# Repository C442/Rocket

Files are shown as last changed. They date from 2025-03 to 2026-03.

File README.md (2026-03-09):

Rocket 2025
======
Project 2025 (http://www.youtube.com/watch?v=yQALvxHjtCE)

Welcome to our latest Project: a rocket guidance system. 

This project took around half a year to build, the other part of the year was spent documenting it. It was originally aimed to improve larger project management under time pressure and university schedule. We wanted to do this project a few years ago already, but somehow ended up with other side quests to fulfill, so this can be seen as our last highschool project, marking a waypoint for bigger, badder and more complex projects. I almost forgot that this project was also supposed to "cure problems related to boredom" and I want to point out that it definitely managed to fill quite some hours...maybe a few too many? Nah...this was worth it. 

This repo will only serve as a project overview and memory. This encompasses the code, the prints, the project paper and most importantly: some pictures 

Table of Content
================

<!--ts-->
- [Visual Designs](#Visual-Designs)
- [Board Computer](#Board-Computer)
- [Parachute Deployment](#Parachute-Deployment)
- [Thrust Vector Control System](#TVC-System)
- [About us](#About-us)
<!--te-->

Visual Designs
==============
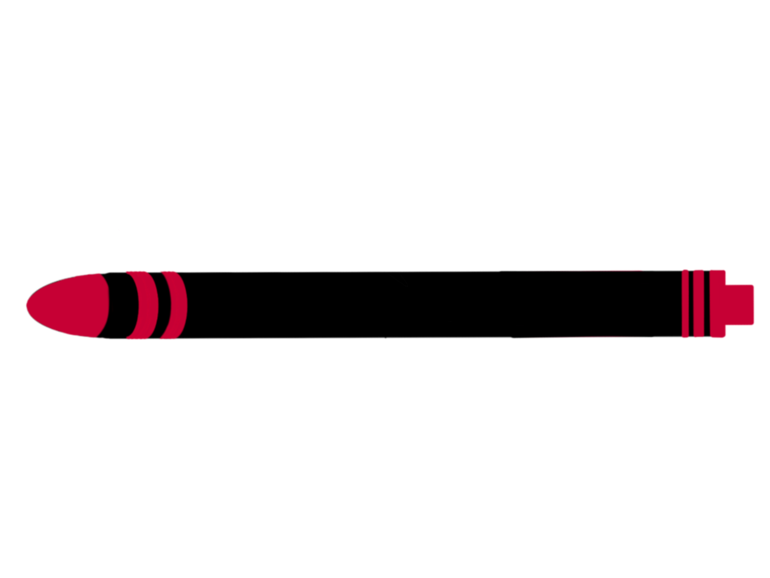
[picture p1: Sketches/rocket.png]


Board Computer
==============
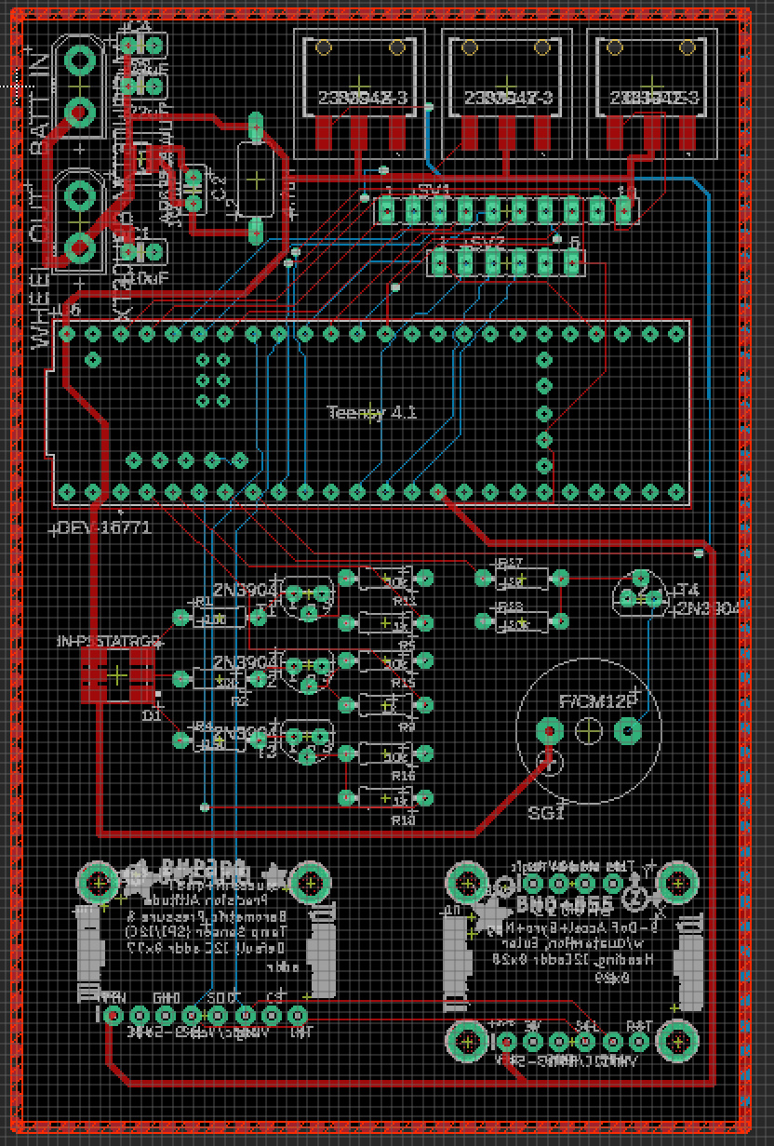
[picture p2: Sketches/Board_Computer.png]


Parachute Deployment
====================
Demo Preview

TVC System
==========
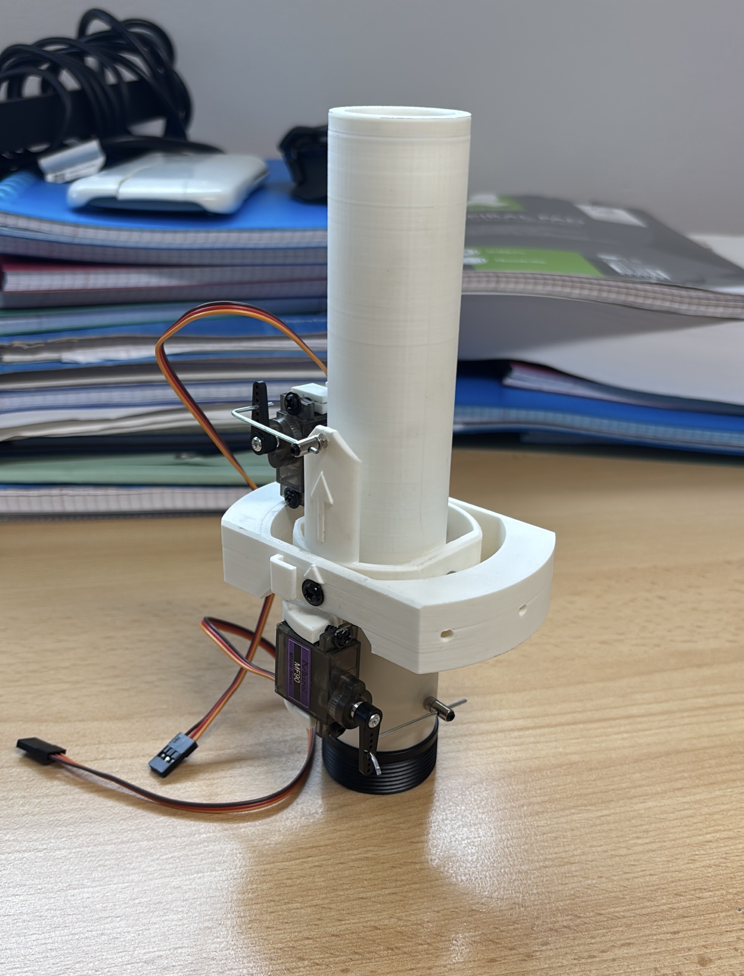
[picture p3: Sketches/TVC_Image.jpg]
TVC System


References
==========

1. [Collins Dictionary – Rocketry](https://www.collinsdictionary.com/dictionary/english/rocketry)  
   Accessed 12 January 2026.

2. [YouTube Video – Our first rocket launch](https://www.youtube.com/watch?v=nfHlhmoQnFs)  
   Accessed 27 January 2026.

3. [Luxembourg Space Agency – Spacewatch Global Article](https://spacewatch.global/2018/09/luxembourg-space-agency-open-for-business-as-new-space-hub/)  
   Accessed 28 January 2026.

4. [BBC News – Rocket Article](https://www.bbc.com/news/articles/cjewvpkw7weo)

5. [NASA Rockets Educator Guide](https://www.nasa.gov/wp-content/uploads/2012/07/rockets-educator-guide-20.pdf)  
   Accessed 28 January 2026.

6. [Wikipedia – Booster (Rocketry)](https://en.wikipedia.org/wiki/Booster_(rocketry))  
   Accessed 28 January 2026.

7. [BBC Science & Environment – Rocket Article](https://www.bbc.com/news/science-environment-24331860)  
   Accessed 28 January 2026.

8. [Eurocircuits – PCB Manufacturing](https://www.eurocircuits.com/)  
   Accessed 2 February 2026.

9. [Printables – Rocket Thrust Vector Control Gimbal](https://www.printables.com/model/9920-k-9-rocket-thrust-vector-control-gimbal-v8/related?lang=de)  
   Accessed 2 February 2026.

10. [YouTube – Nicola Gaiani](https://www.youtube.com/@nicola_gaiani)  
    Accessed 2 February 2026.

11. [Springer – Technische Mechanik Buch](https://link.springer.com/book/10.1007/978-3-662-59886-3)  
    p. 290. Accessed 9 February 2026.

12. [Wikipedia – PID Controller](https://en.wikipedia.org/wiki/Proportional%E2%80%93integral%E2%80%93derivative_controller)  
    Accessed 28 January 2026.

13. [YouTube – Parachute Ejection Inspiration](https://www.youtube.com/watch?v=COkh5ykzC3Y)  
    Accessed 9 February 2026.

14. [Madgwick Filter Explanation](https://medium.com/@k66115704/imu-madgwick-filter-explanation-556fbe7f02e3)  
    Accessed 9 February 2026.

15. [Introduction to Quaternions](https://lisyarus.github.io/blog/posts/introduction-to-quaternions.html)  
    Accessed 9 February 2026.

16. [YouTube – Moto Moto Song](https://www.youtube.com/watch?v=vx5vpG6jEXI)  
    Accessed 9 February 2026.

17. ChatGPT was used to check the text and correct it. In the abstract it was used to rephrase. It was also used to generate code.

18. [Project GitHub Repository](https://github.com/C442/Rocket)  
    The repository designated to this project.

About us
========
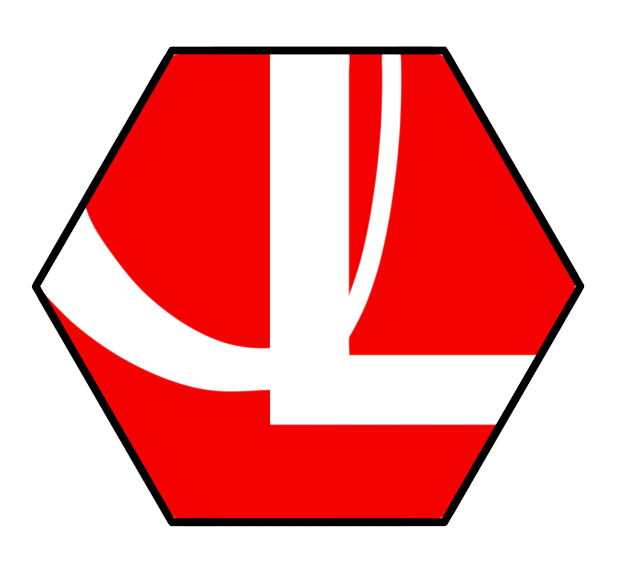
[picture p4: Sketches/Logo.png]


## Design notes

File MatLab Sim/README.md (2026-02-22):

# Modeling a Thrust Vector Controlled Rocket in Simulink

View Modeling a Thrust Vector Controlled Rocket in Simulink on File Exchange (https://www.mathworks.com/matlabcentral/fileexchange/80716-modeling-a-thrust-vector-controlled-rocket-in-simulink)

Thrust Vectoring or Thrust Vector control is the ability of an aircraft or a rocket's propulsion system to manipulate the direction of its thrust to control the rocket or aircrafts attitude or angular velocity. Adjusting the gimbal angle, controls the direction and attitude of the of the rocket as shown in the image below

Gimbaled_thrust_diagram

<a href="https://commons.wikimedia.org/wiki/File:En_Gimbaled_thrust_diagram.svg" title="via Wikimedia Commons">Gimbaled_thrust_diagram.gif:Brian0918 at en.wikipediaderivative work: Titimaster</a> / Public domain

Code in this repository is discussed in this BPS.Space YouTube video shown below.(http://www.youtube.com/watch?v=nwgd1CV__rs "")

To use the files,

- Clone the repository as seen [here](https://www.mathworks.com/help/simulink/ug/clone-git-repository.html)

- Open `simpleTVCRocketModel.slx`

- Click the appropriate hyperlink to choose between a simple Aerospace Blockset or Simscape implementation

- Move the Gimbal angle slider to see the effect of different gimbal angles on the trajectory of the rocket. 

[Learn how to get MATLAB and Simulink](https://www.mathworks.com/products/get-matlab.html)

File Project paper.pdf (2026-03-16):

# Project Paper

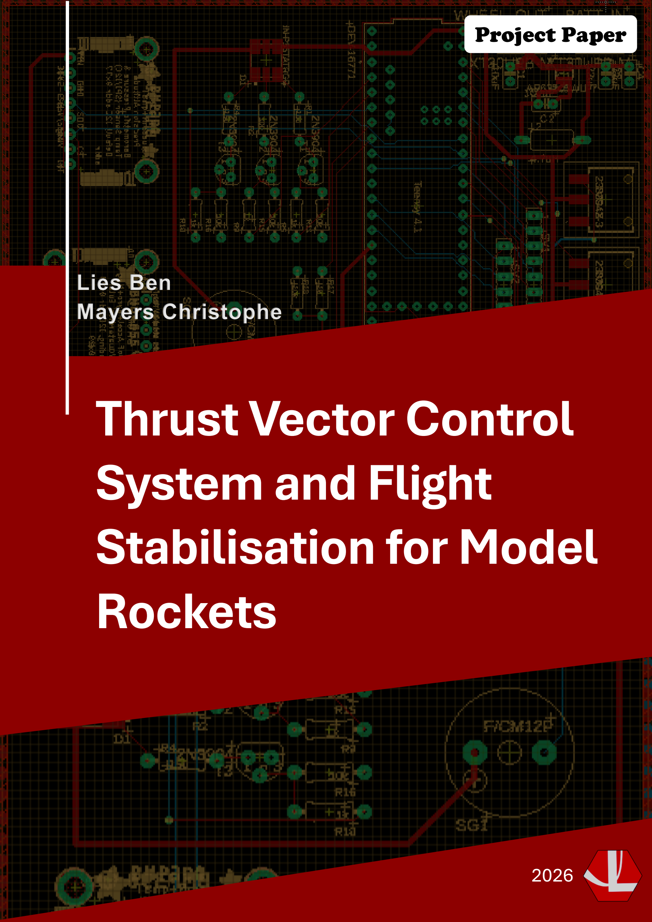
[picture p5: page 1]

## Lies Ben Mayers Christophe

# Thrust Vector Control System and Flight Stabilisation for Model Rockets

## Abstract

Rocketry is an engineering discipline concerned with the design, construction, and launch of rockets at both professional and amateur levels [1]. Due to its modular nature, it provides an effective framework for introducing engineering concepts at an early stage, allowing increasing levels of complexity to be incorporated across successive projects.

A first model rocket was launched in 2023 [2] and was equipped with an Arduinobased flight computer for data acquisition. Post-flight analysis revealed significant issues, including an unstable, highly elliptical flight path and limited usefulness of the collected data. These shortcomings motivated the development of the present project.

Building upon the earlier design, a new model rocket was designed, constructed, and simulated. Improvements included a smaller body tube, a higher-performance flight computer, and the integration of a flight guidance and stabilisation system based on thrust vector control. The primary objectives were achieved; however, the results also revealed new limitations, providing clear direction for future design iterations.
Index terms- Rocketry, guided flight, thrust vector control, flight stabilisation

List of Figures

## Contents

1 Introduction | 6
1.1 Domain | | 6
1.2 Scientific deliveries | | 6
1.3 Technical deliveries | | 6
2 Methodology | 7
2.1 Tools and prerequisites | | 7
2.2 Printed Circuit Board (PCB) | | 8
| 2.2.1 Design | | 8
| 2.2.2 Production | | 9
2.3 Thrust-Vector-Control System (TVC) | | 9
| 2.3.1 Design | | 9
| 2.3.2 Production | | 9
2.4 Reaction wheel | 11
2.4.1 Design | 11
2.4.2 Production | 13
2.5 Rocket body and nosecone | 15
2.5.1 Design | 15
2.5.2 Production | 16
2.6 Software | 16
2.6.1 Madgwick Filter [14] | 16
2.6.2 State Machine | 17
2.6.3 LQR Controller | 18
2.7 Simulations | 19
3 Results | 21
3.1 Printed Circuit Board (PCB) | 21
3.2 Thrust-Vector-Control System (TVC) | 21
3.3 Reaction Wheel | 22
3.4 Body and nosecone | 23
3.5 Simulations | 23
3.6 Software | 25
4 Conclusion | 25

## List of Figures

1 | Final board designed in EAGLE | | 8
2 | Final assembled PCB | | 9
3 | First TVC Mount prototype | 10

List of Figures

4 | Curve Fitting of the Y TVC Servo | 10
5 | Reaction wheel | 12
6 | Casing for the reaction wheel and PCB | 12
7 | Test setup | 13
8 | Early rocket body design | 15
9 | Nosecone | 15
10 Overview of the state machine | 17
11 Overview of the whole SIMULINK simulation | 19
12 Simulation of the rocket dynamics | 19
13 Simulation of the LQR Controller | 20
14 Converting torque to TVC angles | 20
15 Final TVC | 21
16 Finished reaction wheel | 22
17 Final assembled rocket | 23
18 Torque applied to the rocket | 24
19 Simulation results | 24
20 Software results | 25

1 Introduction

## 1 Introduction

Aerospace engineering has seen drastic advancements and an increasing public interest in Luxembourg. With the Luxembourg Space Agency (LSA) pushing the frontiers of international politics into an extra-planetary dimension in pursuit of a “commercial space hub“[3], the question of a sustainable rocket launching infrastructure rises naturally. The core problem of a space economy and the ability to utilise the associated vast resources is a logistical one. Transportation costs are currently not sustainable[4]. Reducing overall cost per launch is hence a necessary step for future space travel that can be achieved by optimizing the most cost inducing sections, like booster stages. Boosters are rocket engines that help with the initial thrust of a rocket to escape Earth’s gravity until reaching low orbit [5]. After expending all available fuel, they are cut off [6] and fall back to earth. The possibility of reusing these booster stages for future missions would substantially reduce operational costs [7] and could be achieved by making them land themselves, reducing potential damages. This work focuses on replicating a mandatory capability towards this novelty, namely controlled flight, and documenting it.

### 1.1 Domain

This project can be placed into the engineering domain. Main problems will revolve around correct algorithm tuning, managing components and the operating speed of the flight computer. Connecting so many electrical components to a development platform usually results in unpredictable behavior and requires a lot of careful preparation. This will be solved using a printed circuit board. The chosen algorithm must be adapted to the rocket, simulated and tuned which is closer to an art form than a science. However, the most important aspect is the operating speed of the development board which must keep up with mid-flight-calculation and communication. These parameters are most decisive for the success of this project.

### 1.2 Scientific deliveries

The scientific deliveries for this project are a deepened understanding of rocketry and preparing for more complex future projects. Rocket science is renowned to demand precision and a lot of knowledge. To attain a professional, or even an amateur level, can take years and depend on a lot of dedication, like any other skill. With the finalisation of this project, perseverance is proven and a contribution to public awareness is made. Potentially inspiring others to become scientists themselves would be one of the most preferable deliveries: “Not everyone can become a great [scientist], but a great [scientist] can come from anywhere”. (Ratatouille, 2007)

### 1.3 Technical deliveries

The technical deliveries are more dispersed and build up to a fully functioning model rocket with a directional guidance system. The hardware consisting of the printed circuit board (PCB), the thrust-vector-control (TVC) system, the reaction wheel, the nose cone with its parachute release mechanism and the rocket body. The software will be a directory of files responsible for the communication between components, collecting information, controlling servo and brushless motors, and the flight algorithm.

## 2 Methodology

### 2.1 Tools and prerequisites

Since this project encompasses the entire production process of a rocket, a wide range of technical skills and tools is required:

- Simulink is the software used to simulate the flight algorithms performance and later tune the necessary parameters in the program on the development board. A rocket computer alone is unaware that it is a flying object and only reacts within the rules of its programming. If one were to use the exact same algorithm for a 2m and a 20 cm long rocket, one would most likely have drastically different results. Flight algorithms are not “add-on solutions” and must be tested and adjusted. This fine tuning allows to adapt the algorithm to the rocket’s specific requirements. Understanding how Simulink works is hence crucial for this project.
- Autodesk Fusion360 is the computer-Aided-Design (CAD) platform used for 3d modelling. 3D modelling is necessary to visualise and later easily, qualitatively and efficiently try out hardware components for the rocket. This skill set is hence not only a must for this project, but for any future engineer.
- GitHub is the chosen developer platform that helps to organise, manage and store our files for this project. It is beneficial, but not mandatory since it mostly just improves team related workflow.
- Arduino/C++/Matplotlib/Jupyter Notebook are the programming languages used for this project because of all the algorithms and scripts for the electronic components. Matplotlib and jupyter notebook were mostly used to do some quick calculations and TVC gimbal curve fitting. The entire software relies on understanding these programming languages.
- Autodesk Eagle is an electronic design automation software (EDA) that helps to design PCBs. As this project revolves around a custom printed circuit board, knowing the physical behaviour of the components and being familiar with this tool is recommended.
- Prusa/Cura Slicer and Bambulab PS1 printer are the next natural step after the 3D modelling program. The slicer is used to prepare the 3D model for printing. Most parts of this project require high precision and durability. Access to good printers and a general comprehension of this process is therefore compulsory.

2 Methodology

- Hand tools and painting equipment are also required. All secondary tasks, like the assembly of the PCB or painting the rocket body need tools, like a soldering iron or spray paint.

### 2.2 Printed Circuit Board (PCB)

The PCB is the heart of the entire rocket. It is connected to an 11.1V battery and controls all the actuators. Besides that, it gathers important sensor data, logs it onto an SD Card and has sensor fusion to predict and correct the rocket’s position.

### 2.2.1 Design

The design process mostly began with the question of which information would be needed to keep a rocket upright. We settled on a BNO055 inertial measurement unit (IMU) sensor to obtain the orientation and a BMP390 barometer to determine the altitude. Then, only the actuator side needed to be covered. To accomplish this, three terminal blocks were used to connect the X and Y servos of the TVC and the servo controlling the parachute ejection. For visual and audible feedback, a bright RGB LED and a buzzer was chosen. As most of the components required 3.3V or 5V, a voltage converter from 11.1V to 5V was implemented. The most important component of the PCB was a Teensy 4.1 acting as main MCU. It is known for its incredible speed and even having an SD Card reader/writer already onboard, outperforming the more commonly used Arduino Uno by far.

As the last step we used EAGLE to draw a simple schematic and create a board connecting all previously chosen components. Additionally, some headers for debugging and a reaction wheel was added.

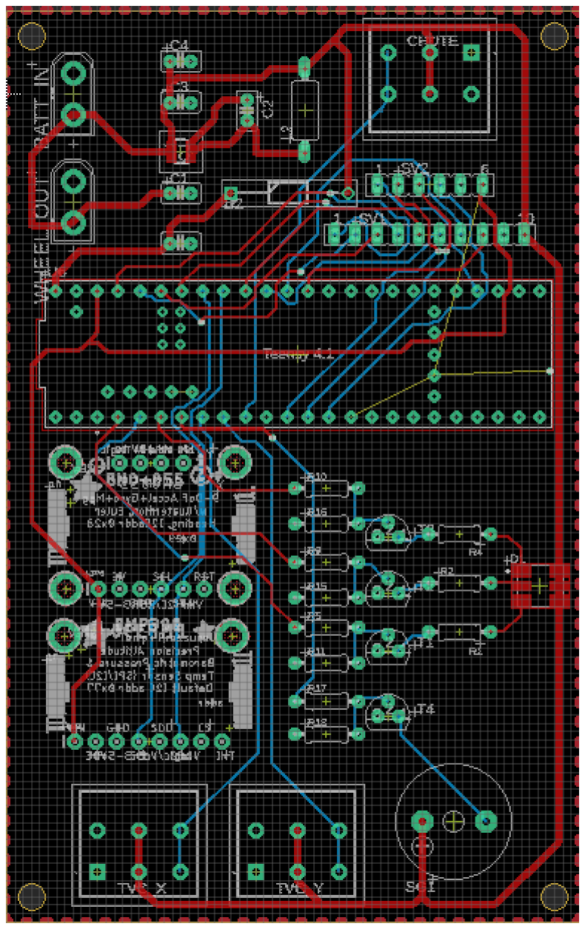
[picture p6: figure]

Figure 1: Final board designed in EAGLE

2.3 Thrust-Vector-Control System (TVC)

### 2.2.2 Production

The files of the PCB were sent to Eurocircuits [8] from which the later on finished boards were received. All components were then soldered onto it and tested with a voltmeter to prevent unexpected future errors. To exemplify, it was through this method immediately noticeable that an RGB LED was soldered the wrong way onto the PCB or the voltage converter design flawed. The voltage converter was then later replaced by the brushless motor’s electronic speed controller which luckily also had the necessary 5V power distribution.

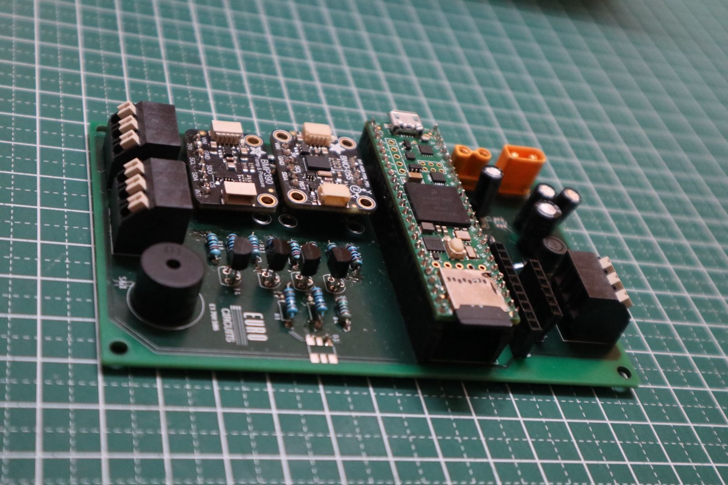
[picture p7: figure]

Figure 2: Final assembled PCB

### 2.3 Thrust-Vector-Control System (TVC)

The TVC can be simply described as a two axis gimbal which holds a solid rocket motor in place and allows to precisely control the motors orientation through two servos. Without it, stabilizing a rocket would be impossible.

### 2.3.1 Design

For the design we looked for online inspiration and quickly found some already existing solutions [9] which seem to work quite well. After adapting the design to the required parameters of the chosen rocket body in Fusion360, the first prototype was made.

### 2.3.2 Production

The TVC mount was fully 3D printed in PLA and then assembled with screws and servo linkages until we end up with the following:

2 Methodology


Figure 3: First TVC Mount prototype

Having the physical model ready, it was then essential to determine a function that converts servo angle to gimbal angle for both axis. Two approaches were trialed to achieve this:

Engineering approach: For this approach we strapped an inertial measurement unit (IMU) to the gimbal, sent known angles to the servos and measured the resulting gimbal angle with the IMU. This process was repeated several times for redundancy. Afterwards, one would only need to do some curve fitting with Matplotlib/Jupyter Notebook and get an appropriate function.

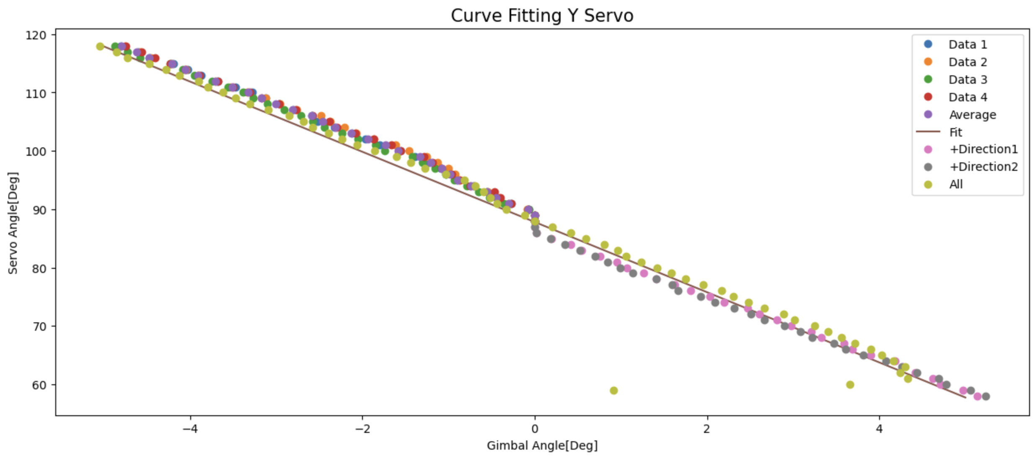
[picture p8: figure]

Figure 4: Curve Fitting of the Y TVC Servo

Mathematical approach: For this approach we used a mathematical model developed by the YouTuber Nicola Gaiani [10]. One would need to enter the specific parameters of the TVC mount and then get for each servo angle input an appropriate gimbal angle output. This process required curve fitting again.

2.4 Reaction wheel

Source code 1: Mathematical model of the TVC mount 1 import math

2
3 | # Constants (in mm)
4 | l1_s1 = 10.5 | # length of servo attach
5 | l2_s1 = 32.5 | # bar length
6 | l3_s1 = 42.5 | # distance from pin to bar on the 3D printed part
7 | Cx_s1 = 30.0 | # x distance between servo wheel and mount pin
8 | Cy_s1 = -29.0 # y distance

9
10 import numpy as np

11
12 | def m_to_s1(a):
13 | a = np.radians(90-a)

14
15 | px = Cx_s1 + l3_s1 * np.cos(a)
16 | py = Cy_s1 + l3_s1 * np.sin(a)
17 | d = np.sqrt(px**2+ py**2)

18
19 | x1 =(l1_s1**2+ d**2- l2_s1**2) / (2 * d)
20 | y1 = np.sqrt(l1_s1**2- x1**2)

21
22 ang = np.arctan2(py, px)

23
24 | x2 = x1 * np.cos(ang)- y1 * np.sin(ang)
25 | y2 = x1 * np.sin(ang)+ y1 * np.cos(ang)

26

27
28 return np.degrees(np.arctan2(y2, x2))

### 2.4 Reaction wheel

The reaction wheel tries to conserve the angular momentum of the rocket while not using any fuel. It tries to counter rotate any undesired rotational spin, caused by air drag for example, acting as a small support system for the thrust vector control system. By keeping the rotational speed low, or null at best, it could prevent a potential coning motion, usually referred to as precession. In this project, it consists of an electronic speed controller (ESC), a brushless motor and the reaction wheel.

### 2.4.1 Design

The design phase mostly revolved around finding an acceptable hardware solution for a reaction wheel, finding a good production method and deciding on its placement in the rocket.

2 Methodology

Originally, the reaction wheel was supposed to be out of lightweight aluminum to maximize the power limits of the brushless motor, but the addressed milling company made us reconsider. Consequently, it was 3D printed. To achieve the highest moment of inertia the reaction wheel got the form of a ring with radial support to a central hub that connects directly to the brushless motor [11]. To compensate for the missing weight, screw holes were added for later weight addition.

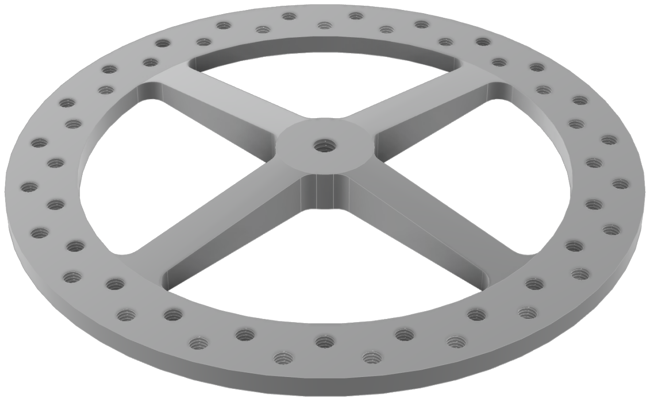
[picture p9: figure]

Figure 5: Reaction wheel

To guarantee the safety of the internal rocket body and simultaneously give the brushless motor a fixed place, a casing was designed for it. However, the casing sealed the motor from the PCB and entailed the electronics to run between the inner rocket body wall and the casing.

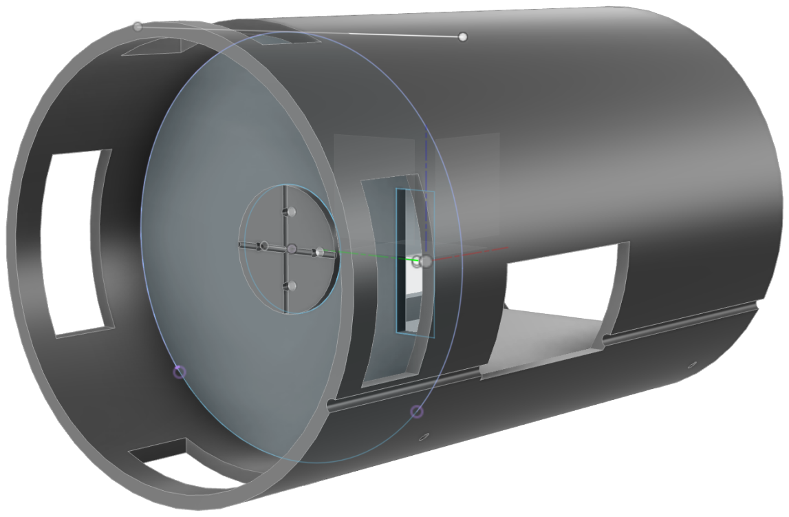
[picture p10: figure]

Figure 6: Casing for the reaction wheel and PCB

2.4 Reaction wheel

### 2.4.2 Production

The production process describes the practical realization of the reaction wheel and its addition to the PCB. It began with 3D printing the reaction wheel and adding screws onto it. Afterwards, the brushless motor was tested while attached to the PCB.

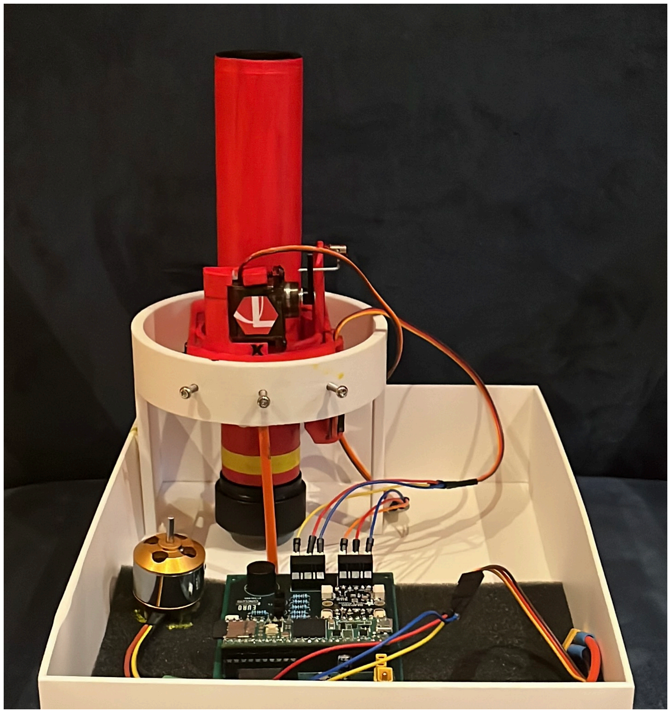
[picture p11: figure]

Figure 7: Test setup

In these coding experiments, the electronic speed controller didn’t support bi-directional spin. After projecting the problem into the domain of model cars, it could have been solved with an H-bridge, allowing switching the polarity of the brushless motor with relays. This task was not foreseen, implied a redesign of the power supply and remodeling of all involved components. The easiest solution was however to replace it with a new bidirectionally supported ESC, even though it was monetarily more expensive. The latter solution was implemented. For improved movement, we added a PID controller to the reaction wheel [12]. A PID controller is a control algorithm that works with a continuous feedback loop for a correct adjustment around a fixed setpoint. In this project, this fix set point can be interpreted as a state, namely the rocket not rotating around its own axis. This correction revolves around magnitude of the error between the setpoint and the actual value. This controller projects this error into the near future and remembers how it was in the past. Based on this information it tries to decides to adjust the motor speed accordingly. This lowers the risk of overshooting and consequently making too harsh movements in this time sensitive operation.

Source code 2: PID controller implementation for reaction wheel

1 | void MotorController::update() {
2 | // 1. Read gyro (Y-axis rate)
3 | imu::Vector<3> gyro = bno.getVector(Adafruit_BNO055::→ω
| VECTOR_GYROSCOPE);
4 | measuredRate = gyro.y();

5

2 Methodology

6 | // 2. Time step
7 | unsigned long now = millis();
8 | float dt =(now - prevTime) / 1000.0;
9 | prevTime = now;

10
11 | // 3. PID
12 | float error = setpoint - measuredRate;
13 | integral += error * dt;
14 | float derivative =(error - prevError)/ dt;
15 | prevError = error;

16
17 | float pidOutput = Kp * error + Ki * integral + Kd * derivative→ω
| ;

18
19 | // 4. Compute throttle
20 | int throttle = computeThrottle(error, pidOutput);
21 | esc.writeMicroseconds(throttle);

22
23 | // 5. Debug
24 | Serial.print("Y rate: "); Serial.print(measuredRate);
25 | Serial.print(" | Error: "); Serial.print(error);
26 | Serial.print(" | PID: "); Serial.print(pidOutput);
27 | Serial.print(" | Throttle: "); Serial.println(throttle);
28 | }

After testing completed successfully, no further problems arose. The reaction wheel was added to the casing and the ESP finally soldered to the PCB. We then used 2 component glue to fix the casing into the rocket body.

2.5 Rocket body and nosecone

### 2.5 Rocket body and nosecone

The rocket body contains all the electronics. The nosecone is responsible for the parachute release.

### 2.5.1 Design

The design phase of the rocket body and nosecone covers the decision for the size, appearance and the parachute mechanism.

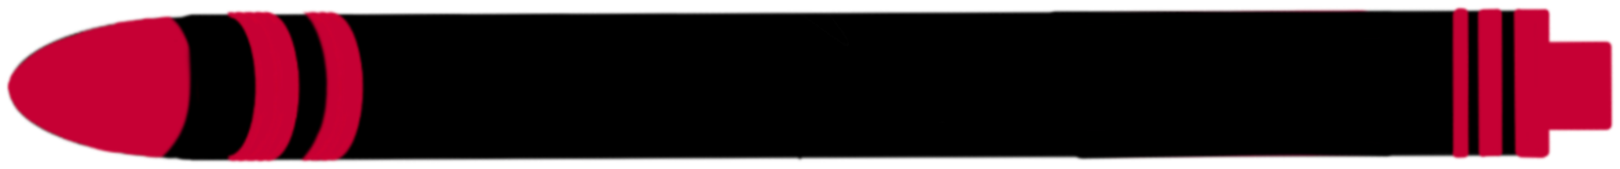
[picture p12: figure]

Figure 8: Early rocket body design

The most influential factor for the decision of the rocket body was convenience. It should be large enough to justify a TVC system, but not too large to unnecessarily waste space. A tube with a diameter of 10 cm and length of 100 cm was chosen. The nose cone must have a reliable parachute release mechanism and fit our personalised rocket body. Taking inspiration from the Youtube Channel Air Command Rockets [13] it was hence opted to 3D model it and add an empty chamber that opened with a servo motor. This servo motor would hold a plate that could fall off and open the chamber, allowing the parachute to simply fall out.

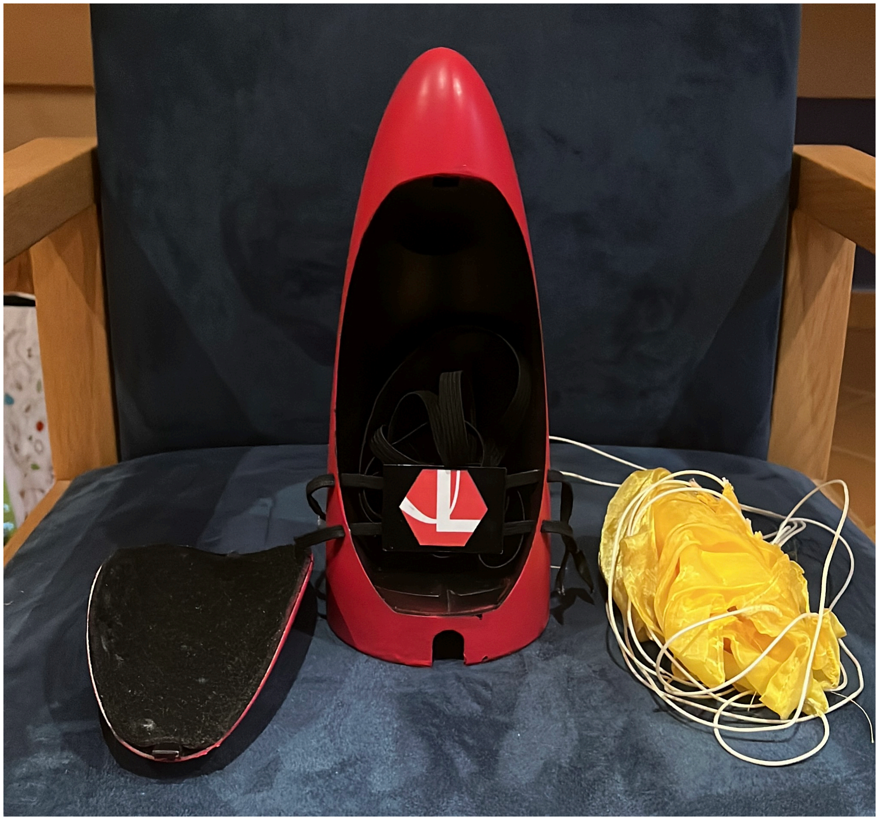
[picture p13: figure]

Figure 9: Nosecone

2 Methodology

For the paint job, it was decided to go for a bright red with yellow and dark elements imitating a famous Formula 1 car design.

### 2.5.2 Production

The production process included the rocket body and nosecone modifications. On arrival, the rocket body was painted with spray cans and then cut in half. Firstly, it received a black coating and then red stripes. At the same time, we painted the nosecone completely red. The cord was attached to the parachute, folded, put into the nosecone chamber and then sealed with the door. After putting in all the electronics, the lower half contained the TVC system and PCB. The upper part consisted out of the reaction wheel and the nosecone. At last, we reattached the 2 halves.

### 2.6 Software

The onboard flight software is responsible for real-time state estimation, flight-phase management, and thrust vector control during powered ascent.

The software is structured into three main layers:

1. Sensor acquisition and attitude estimation,
2. State machine governing flight phases, and
3. a control layer computing thrust vector commands based on the estimated state

### 2.6.1 Madgwick Filter [14]

Accurate attitude estimation is essential for thrust vector control, as control commands depend directly on the rocket’s orientation. Gyroscopes provide smooth short-term orientation but suffer from drift, while accelerometers provide an absolute reference to the gravity direction but are sensitive to dynamic accelerations.

The Madgwick filter fuses both sensor types in a computationally efficient manner, making it well suited for real-time embedded applications. Orientation is represented using quaternions [15], avoiding gimbal locks. Gyroscope measurements are used to propagate orientation through quaternion integration, while accelerometers are used to correct long-term drift.

The correction is obtained by comparing the measured gravity direction with the direction predicted by the current orientation estimate. The resulting misalignment is expressed as an error function in quaternion space and its gradient provides a correction direction. The estimated quaternion derivative is given by:

2.6 Software

q˙ est = q˙ ω ↑ ω ↓f
↔↓f↔ | (1)

Where ω controls the influence of the accelerometer-based correction. In our case this value is set very low as the rocket represents a highly dynamic environment.

### 2.6.2 State Machine

The flight software is organized as a finite state machine to ensure deterministic and robust behavior throughout the flight. Each state encapsulates a distinct flight phase with well-defined actions and transition conditions. Separating the flight into phases also improves safety, since time-critical control tasks are only enabled when required.

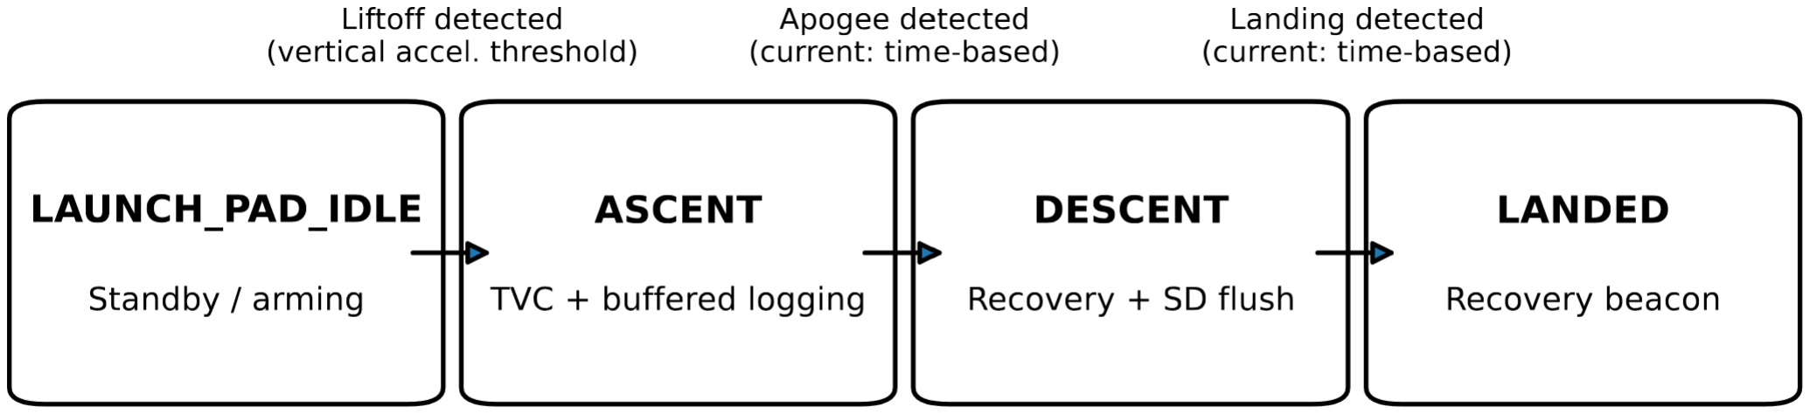
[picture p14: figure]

Figure 10: Overview of the state machine

LAUNCH_PAD_IDLE (pre-launch) In the LAUNCH_PAD_IDLE state, the flight computer remains in a safe standby mode on the launch pad. Sensors are active and the system continuously evaluates a liftoff condition using the measured vertical acceleration. Once liftoff is detected, the system timestamps the start of flight and records a corresponding entry in the event log.
Transition to ASCENT: Liftoff detected (vertical acceleration threshold exceeded).

ASCENT (powered flight / TVC active) During ASCENT, thrust vector control is enabled and the software runs two periodic tasks with different update rates. The control loop executes at 100 Hz and performs attitude estimation, control law evaluation, and servo command output. In parallel, a health monitoring and logging task runs at 25 Hz. To avoid non-deterministic latency introduced by SD card writes, high-rate flight data is buffered in the Teensy flash memory during ascent. Discrete events (e.g., liftoff, apogee) are stored in a separate event file together with timestamps.
Transition to DESCENT: Apogee detected (current implementation: time-based criterion).

DESCENT (recovery phase) After apogee, the system transitions to DESCENT and the parachute is ejected. Since strict real-time control is no longer required, buffered flight data stored in flash is flushed to the SD card during descent. Logging is finalized and closed as well as flight control actions are disabled.
Transition to LANDED: Landing detected (current implementation: time-based criterion).

2 Methodology

LANDED (post-flight) In the terminal LANDED state the system enters a safe post-flight mode. A recovery beacon (buzzer and LED) is activated to facilitate locating the rocket.

### 2.6.3 LQR Controller

During powered ascent, the rocket is stabilized using a Linear Quadratic Regulator (LQR) acting on the rotational dynamics of the vehicle. The system is linearized about the nominal upright flight condition, and the state vector is defined as

x = !

ωε"T , | (2)

where ω denotes small attitude deviations from the vertical reference and ε the corresponding angular rates.

The LQR computes a state-feedback control law of the form

ϑ cmd = ↑Kx, | (3)

where ϑ cmd is the demanded control torque about the rocket’s center of mass. The gain matrix K is obtained by minimizing the quadratic cost function

J =

#→

0

$
xTQx + ϑ T

cmdRϑ cmd%
dt. | (4)

The weighting matrices Q and R penalize attitude deviations and excessive control torque, respectively, allowing a systematic trade-off between stability and control effort.

The demanded torque is subsequently converted into thrust vector deflection commands using the known thrust magnitude and lever arm of the thrust vector control mechanism. The LQR controller is active exclusively during the ascent phase and relies on the attitude estimate provided by the Madgwick filter.

2.7 Simulations

### 2.7 Simulations

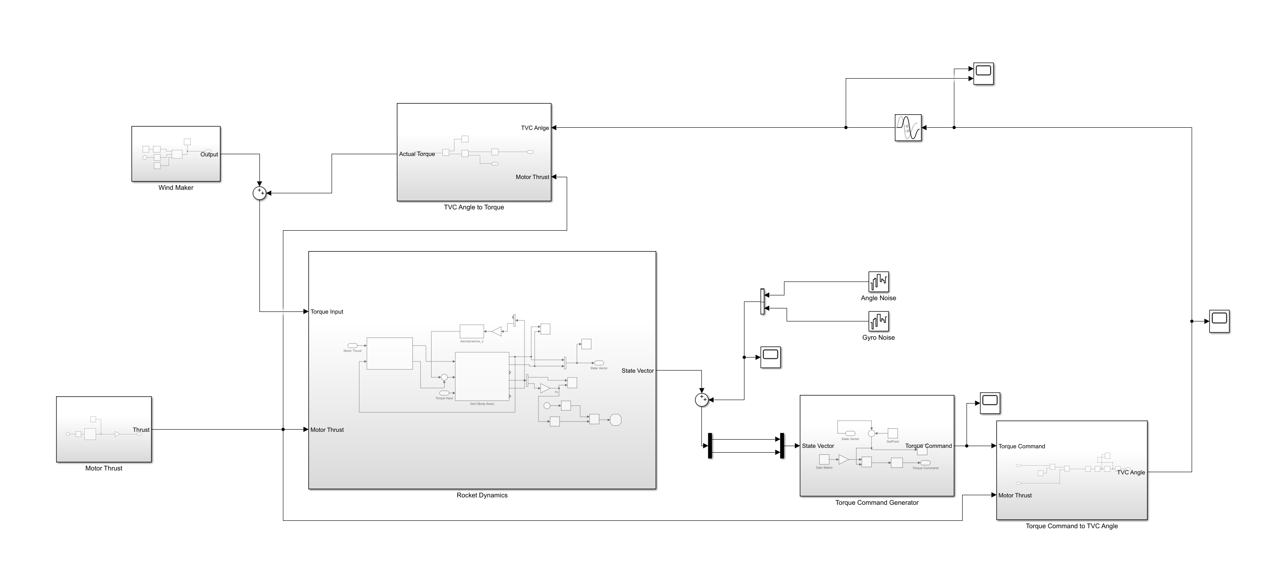
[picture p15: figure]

Figure 11: Overview of the whole SIMULINK simulation

A nonlinear simulation environment was developed in SIMULINK to validate the proposed state estimation and control architecture prior to flight testing. The simulation captures the rotational dynamics of the rocket, thrust vector control actuation, sensor noise, and external disturbances, while maintaining a structure that closely resembles the onboard flight software. This allows controller parameters and state machine logic to be evaluated under realistic conditions before deployment.

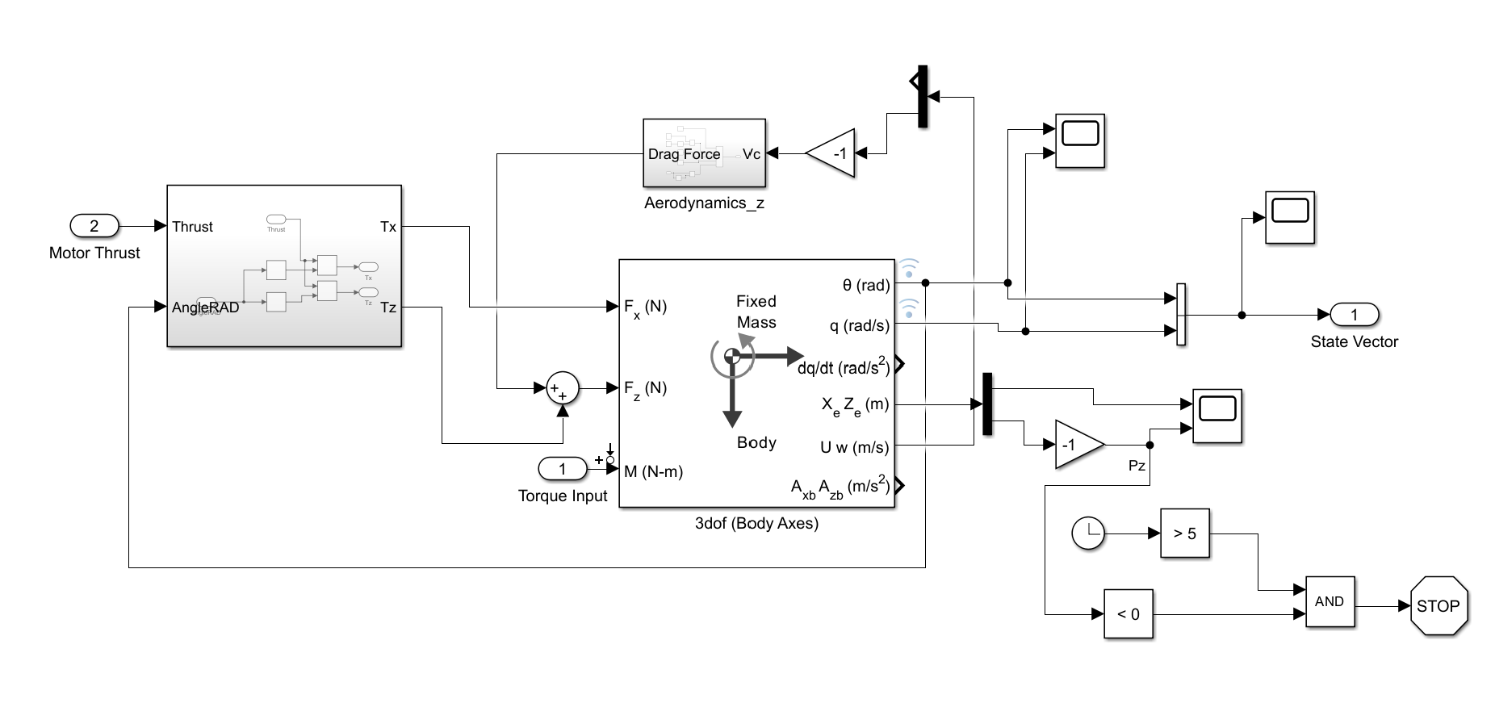
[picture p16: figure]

Figure 12: Simulation of the rocket dynamics

Rocket Dynamics Model The rocket is modeled as a rigid body rotating about its center of mass. The rotational dynamics are governed by Euler’s equation:

Iε˙ = ϑ TVC + ϑ dist,

2 Methodology

where I denotes the moment of inertia, ϑ TVC the control torque generated by thrust vectoring, and ϑ dist external disturbance torques.
The angular rate is integrated to obtain the attitude state, which forms the basis for feedback control. Motor thrust is provided as an external input to the dynamics block, allowing the simulation to capture thrust variations over time.

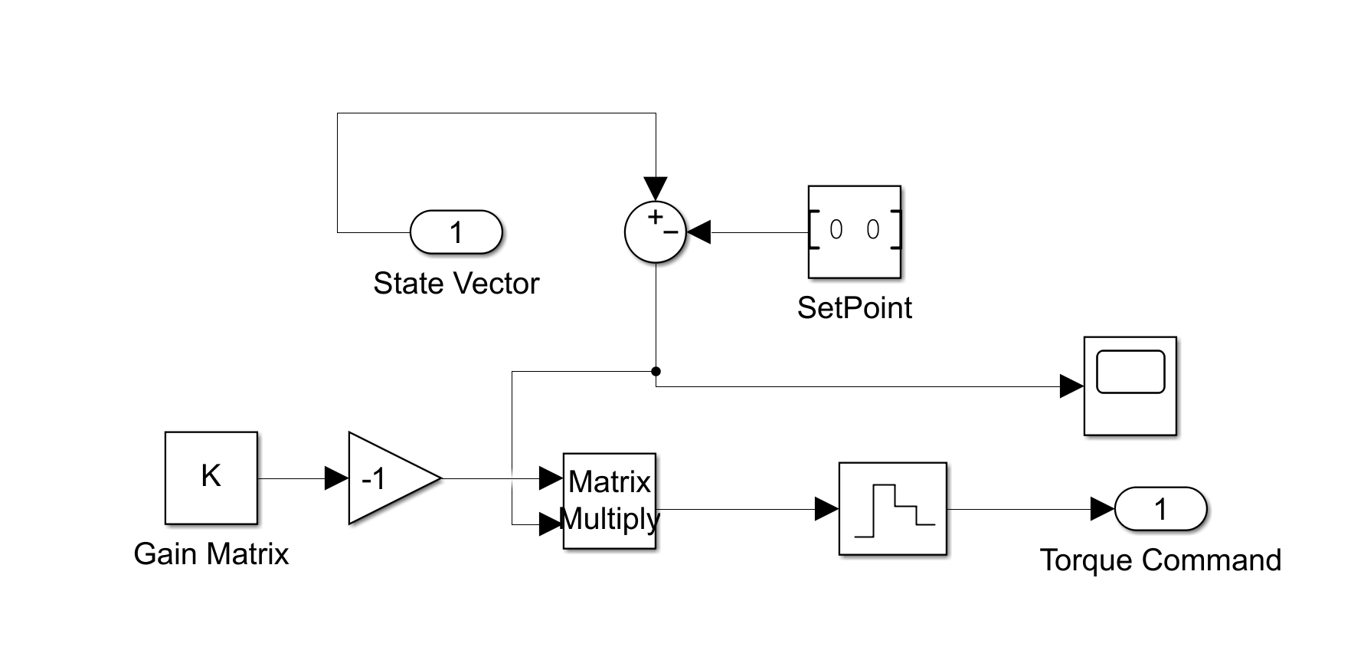
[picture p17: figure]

Figure 13: Simulation of the LQR Controller

Thrust Vector Control and Actuator Mapping The LQR controller outputs a demanded control torque about the rocket body axes. This torque is converted into a thrust vector deflection angle using the known motor thrust magnitude and moment arm of the TVC mechanism. The resulting TVC angle represents the actuator command applied to the motor mount.

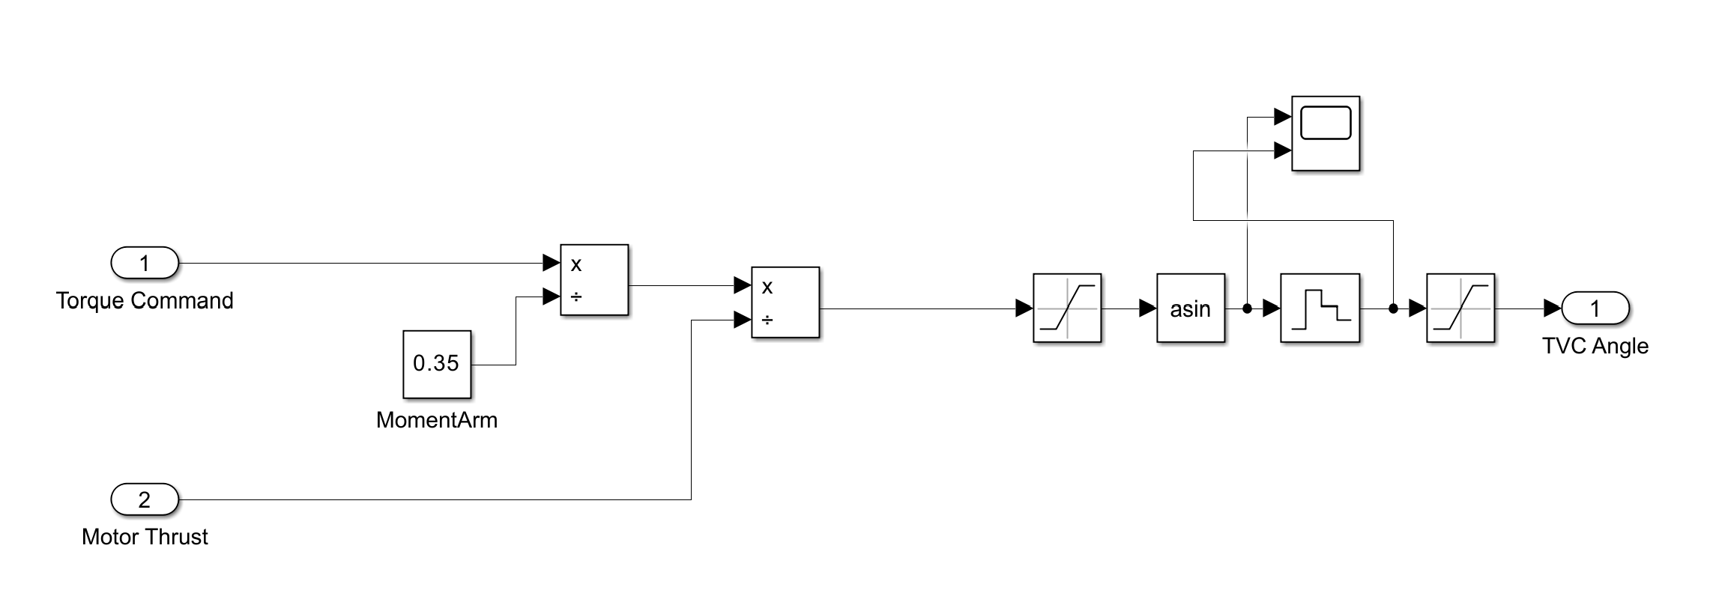
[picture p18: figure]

Figure 14: Converting torque to TVC angles

Within the simulation, this mapping takes into account actuator limits (max deflection angle, actuator delay, etc) as well as flight computer limits (control loop runs at 100Hz)

Sensor Noise and Disturbances To evaluate robustness, sensor noise and external disturbances are explicitly included in the simulation. Gaussian noise is added to both the measured attitude and angular rate signals to emulate inertial sensor imperfections.

Additionally, external disturbance torques are injected into the system to represent aerodynamic effects such as wind gusts. These disturbances act directly on the rotational dynamics and allow the controller’s disturbance rejection capability to be assessed.

## 3 Results

In the following subsections, each component is analysed and discussed. The discussions will revolve around expected behaviour, the accuracy of the simulation and suggested improvements for the next project. Disclaimer: As there were two failed launches our results only rely on ground tests.

### 3.1 Printed Circuit Board (PCB)

The PCB works perfectly as expected besides the voltage converter being replaced by the motor driver. Structurally one could improve the terminal blocks because cables tend to get stuck in them and are therefore hard to remove. In addition one could have made appropriate outputs for the reaction wheel and reduce its size as it is pretty chunky[16].

### 3.2 Thrust-Vector-Control System (TVC)

The TVC fulfills its purpose but there are a lot of things to improve. First of all, it was printed in PLA which is structurally weak and sensitive to high temperature. Better would have been materials like ABS or nylon. Secondly, the motor plug at the top was printed with 30% infill and immediately ripped open when firing the rocket motor and therefore the reason for our first failed launch. Better would have been a 100% infill. Finally, the servos are fine when choosing a rocket motor with a max thrust of around 60N but above that we would have to look for stronger servos.

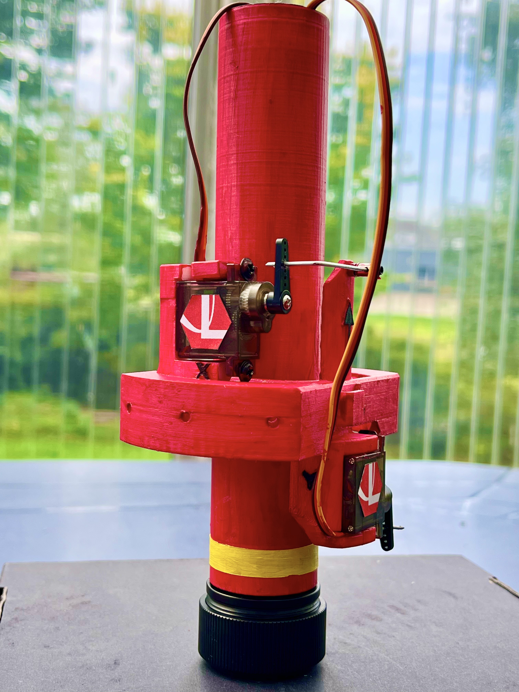
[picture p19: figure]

Figure 15: Final TVC

3 Results

### 3.3 Reaction Wheel

The reaction wheel works as intended and can serve as a small support system. It is capable of counter acting the rotational movement the rocket could experience, lowering the risk of coning motions.

In contrast to the TVC system however, the range of referenced capabilities can be questioned because of a lack of calculations and simulations. Most parameters, like weight, motor strength and the necessity of a PID controller are estimated and not part of the simulations. It is hence a possible sources of error and can, in the worst case, cause the opposite of the desired effect.

Even if the reaction wheel has been successfully made, it will not be used in the launch since it could taint the following evaluation of the simulations too much. It will hence unfortunately only be additional weight. The reason for it not being implemented in the simulations is the difference in the time of completion of the components. The TVC System was the first realised part of the rocket and took months for proper simulation and testing. The idea and decision to add a reaction wheel came much later. It serves now as a prototype and can be considered in the next project from the very beginning.

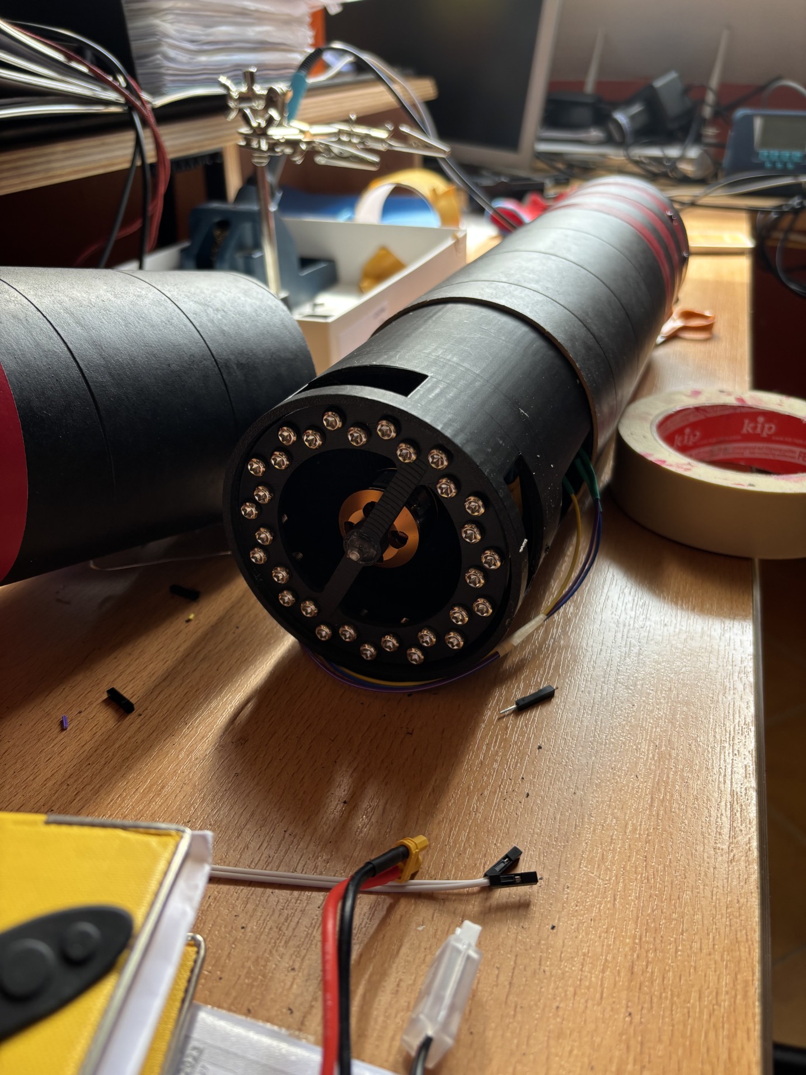
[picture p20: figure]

Figure 16: Finished reaction wheel

3.4 Body and nosecone

### 3.4 Body and nosecone

As there have not been any strong modifications to the rocket body, there are not many results in that regard. The desired visual appeal has been achieved and the nosecone works reliably. Besides the parachute opening midair, there are no concerns.

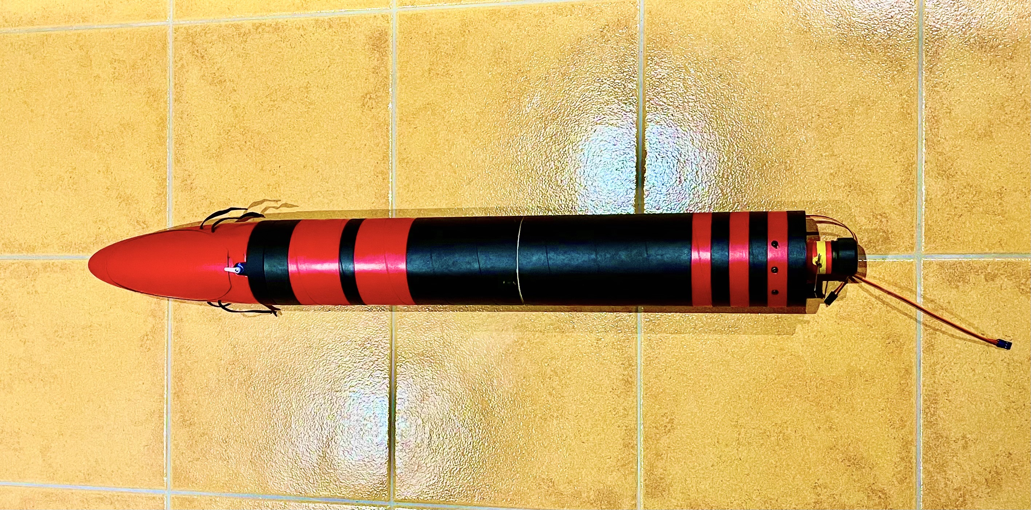
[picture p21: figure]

Figure 17: Final assembled rocket

### 3.5 Simulations

The rotational dynamics used for LQR design are described by the linear state-space model

x˙ = Ax + Bϑ cmd, | (5)

with the state vector

x =

&
ε
ϑ

'

The system matrices are given by

A =

&
01

00'
, B =

&
0

1
I

'
=

& 0

11.6686'
, | (6)

where the moment of inertia is I =0.0857 kg m². The LQR weighting matrices are chosen as

Q =

&
10 0

01'
, | R =2.5. | (7)

Solving the algebraic Riccati equation yields the optimal state feedback gain K = !

2.0000 0.8619"
| , | (8)

resulting in the control law

ϑ cmd = ↑Kx. | | (9)

By applying random torque to the rocket over a period of time (simulating wind gusts or other disturbances) like shown in the following graph:

3 Results

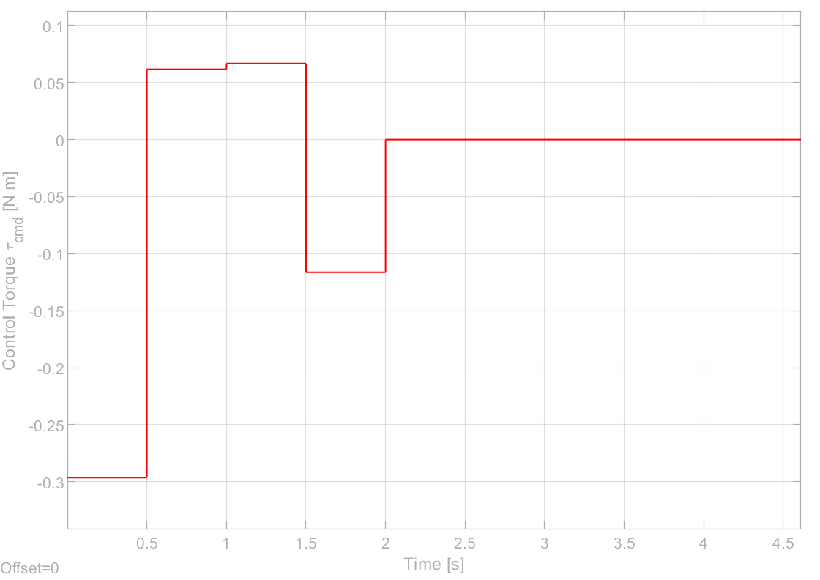
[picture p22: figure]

Figure 18: Torque applied to the rocket

We come to the following results:

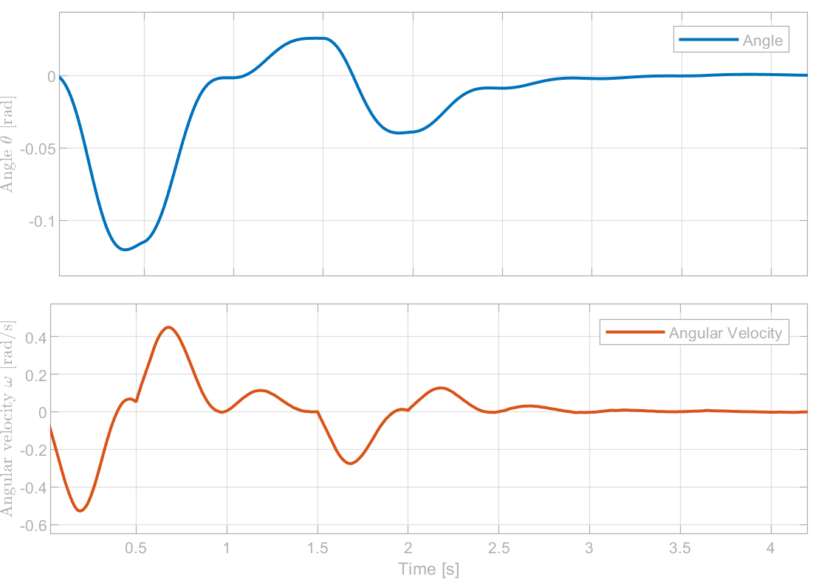
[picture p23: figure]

Figure 19: Simulation results

Figure 19 shows the resulting closed-loop attitude and angular rate response. Despite the applied disturbance torques, the controller maintains stability and rapidly drives both the attitude deviation and angular velocity back toward zero. The response exhibits well-damped behavior with no sustained oscillations, indicating effective disturbance rejection.

The peak attitude deviation remains limited, and angular rates stay within acceptable bounds for the thrust vector control system. This demonstrates that the selected LQR gains provide a

3.6 Software

favorable balance between disturbance rejection performance and control effort, validating the controller design.

### 3.6 Software

By feeding our flight software with sensor data from the simulation we could check if the whole system acts as expected. Placing an IMU on the top of the TVC mount we get the following results:

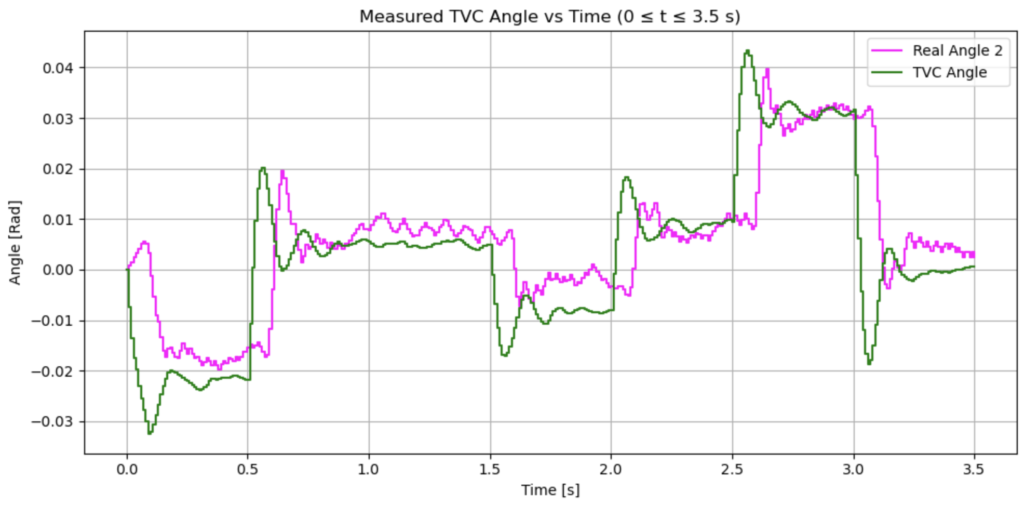
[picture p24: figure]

Figure 20: Software results

Figure 20 compares the simulated TVC angle (in green) with the measured TVC angle (in magenta) obtained during experimental testing. The measured response closely follows the simulated trajectory over the entire time interval, indicating that our software works perfectly.

A consistent time offset between the commanded and measured TVC angle is visible and corresponds to the servo actuation delay of approximately 0.09 s, which is already explicitly modeled in the simulation.

Remaining discrepancies between the simulated and measured TVC angles are attributed primarily to the measurement setup. As stated the TVC angle is inferred from an inertial measurement unit mounted on top of the TVC mechanism, which introduces additional dynamics and measurement noise.

## 4 Conclusion

To conclude, this project was a total success. In 6 months, the entire process of designing, building and simulating a model rocket was achieved. It was a great opportunity to improve necessary skills for future projects, like 3D modelling, printing, painting, soldering, simulating and, most importantly, teamwork. A deeper understanding of rocketry has also been accomplished by discovering the Madgwick filter allowing for accurate sensor fusion, the importance

References

of simulations for component expectations and the gained knowledge on solving the problem for controlled flight. The project hence resulted in a fully functioning, painted and simulated rocket.

When comparing the previously made model rocket in 2023, major differences can be noted. Firstly, the PCB was a huge improvement in regards to cable management and testability. It saved a lot of time and, of course, was visually more appealing. Secondly, it should be impossible with the newly designed nosecone for the parachute to remain stuck in the rocket, like the last time. Lastly, the TVC system could solve the biggest problem yet encountered: the rocket drifting in the wrong direction. This was the reason why the last rocket recovery had become fairly time intensive. All these improvements make this rocket a milestone of a project. This journey is however far from over and every skill and all the experience will be carried into the next projects, just like before.

With all the calculations, simulations, expectations and waiting, there is only one thing left to do and we are sincerely looking forward to it. This project was presented to you by Ben and Christophe and we are ready for our third attempt.

## References

[1] https://www.collinsdictionary.com/dictionary/english/rocketry (https://www.collinsdictionary.com/dictionary/english/rocketry) accessed on 12 January 2026.
[2] https://www.youtube.com/watch?v=nfHlhmoQnFs accessed on 27 January 2026.
[3] https://spacewatch.global/2018/09/luxembourg-space-agencyopen-for-business-as-new-space-hub/ (https://spacewatch.global/2018/09/luxembourg-space-agency-open-for-business-as-new-space-hub/) Accessed on 28 January 2026.
[4] https://www.bbc.com/news/articles/cjewvpkw7weo
[5] https://www.nasa.gov/wp-content/uploads/2012/07/rocketseducator-guide-20.pdf (https://www.nasa.gov/wp-content/uploads/2012/07/rockets-educator-guide-20.pdf) Accessed on 28 January 2026.
[6] https://en.wikipedia.org/wiki/Booster_(rocketry) Accessed on 28 January 2026.
[7] https://www.bbc.com/news/science-environment-24331860 Accessed on 28 January 2026.
[8] https://www.eurocircuits.com/ Accessed on 2 February 2026.
[9] https://www.printables.com/model/9920-k-9-rocket-thrustvector-control-gimbal-v8/related?lang=de (https://www.printables.com/model/9920-k-9-rocket-thrust-vector-control-gimbal-v8/related?lang=de) Accessed on 2 February 2026.

References

[10] https://www.youtube.com/@nicola_gaiani Accessed on 2 February 2026.
[11] https://link.springer.com/book/10.1007/978-3-662-59886-3?utm_source=chatgpt.com (https://link.springer.com/book/10.1007/978-3-662-59886-3?utm_source=chatgpt.com) (S. 290). Accessed on 9 February 2026.
[12] https://en.wikipedia.org/wiki/Proportional%E2%80%93integral%E2%80%93derivative_controller (https://en.wikipedia.org/wiki/Proportional%E2%80%93integral%E2%80%93derivative_controller) Accessed on 28 January 2026.
[13] https://www.youtube.com/watch?v=COkh5ykzC3Y Accessed on 9 February 2026.
[14] https://medium.com/@k66115704/imu-madgwick-filterexplanation-556fbe7f02e3 (https://medium.com/@k66115704/imu-madgwick-filter-explanation-556fbe7f02e3) Accessed on 9 February 2026.
[15] https://lisyarus.github.io/blog/posts/introduction-toquaternions.html (https://lisyarus.github.io/blog/posts/introduction-to-quaternions.html) Accessed on 9 February 2026.
[16] https://www.youtube.com/watch?v=vx5vpG6jEXI Accessed on 9 February 2026.
[17] ChatGPT was used to check over the text and correct. In the abstract it was used to rephrase. It was also used to generate code.
[18] https://github.com/C442/Rocket The Github repository designated to this project ! (https://github.com/C442/Rocket)

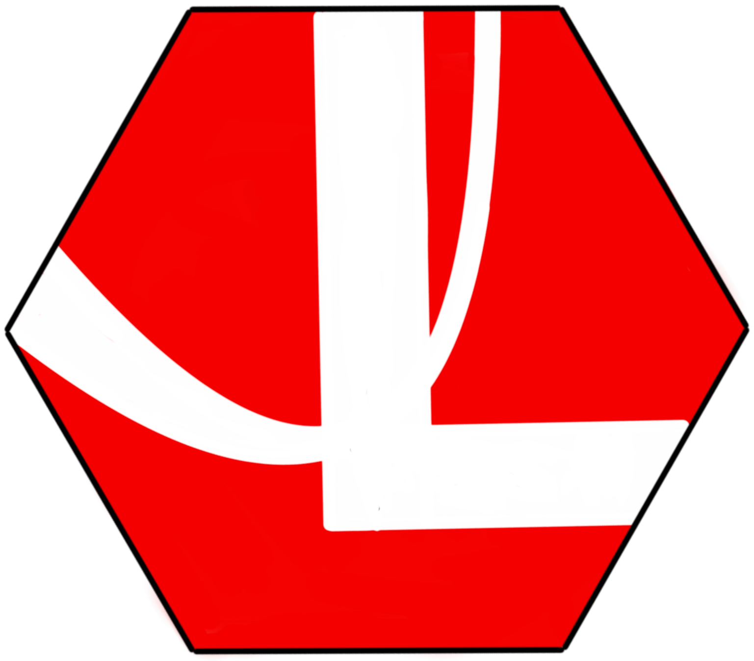
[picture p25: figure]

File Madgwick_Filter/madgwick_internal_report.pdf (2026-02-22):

# An efficient orientation filter for inertial and inertial/magnetic sensor arrays

### Sebastian O.H. Madgwick

### April 30, 2010

Abstract

This report presents a novel orientation filter applicable to IMUs consisting of tri-axis gyroscopes and accelerometers, and MARG sensor arrays that also include tri-axis magnetometers. The MARG implementation incorporates magnetic distortion and gyroscope bias drift compensation. The filter uses a quaternion representation, allowing accelerometer and magnetometer data to be used in an analytically derived and optimised gradient-descent algorithm to compute the direction of the gyroscope measurement error as a quaternion derivative. The benefits of the filter include: (1) computationally inexpensive; requiring 109 (IMU) or 277 (MARG) scalar arithmetic operations each filter update, (2) effective at low sampling rates; e.g. 10 Hz, and (3) contains 1 (IMU) or 2 (MARG) adjustable parameters defined by observable system characteristics. Performance was evaluated empirically using a commercially available orientation sensor and reference measurements of orientation obtained using an optical measurement system. A simple calibration method is presented for the use of the optical measurement equipment in this application. Performance was also benchmarked against the propriety Kalman-based algorithm of orientation sensor. Results indicate the filter achieves levels of accuracy exceeding that of the Kalman-based algorithm; < 0.6

◦
static RMS error, < 0.8
- dynamic RMS error. The implications of the low computational load and ability to operate at low sampling rates open new opportunities for the use of IMU and MARG sensor arrays in real-time applications of limited power or processing resources or applications that demand extremely high sampling rates.

## Contents

1 Introduction | 3
2 Quaternion representation | 4
3 Filter derivation | 6
4 Experimentation | 14
5 Results | 19
6 Discussion | 24
7 Conclusions | 25
A IMU filter implementation optimised in C | 29
B MARG filter implementation optimised in C | 30

## 1 Introduction

The accurate measurement of orientation plays a critical role in a range of fields including: aerospace [1, 2, 3], robotics [4, 5], navigation [6, 7] and human motion analysis [8, 9] and machine interaction [10]. Whilst a variety of technologies enable the measurement of orientation, inertial based sensory systems have the advantage of being completely self contained such that the measurement entity is constrained neither in motion nor to any specific environment or location. An IMU (Inertial Measurement Unit) consists of gyroscopes and accelerometers enabling the tracking of rotational and translational movements. In order to measure in three dimensions, tri-axis sensors consisting of 3 mutually orthogonal sensitive axes are required. A MARG (Magnetic, Angular Rate, and Gravity) sensor is a hybrid IMU which incorporates a tri-axis magnetometer. An IMU alone can only measure an attitude relative to the direction of gravity which is sufficient for many applications [4, 2, 8, 1]. MARG systems, also known as AHRS (Attitude and Heading Reference Systems) are able to provide a complete measurement of orientation relative to the direction of gravity and the earth’s magnetic field.
A gyroscope measures angular velocity which, if initial conditions are known, may be integrated over time to compute the sensor’s orientation [11, 12]. Precision gyroscopes, ring laser for example, are too expensive and bulky for most applications and so less accurate MEMS (Micro Electrical Mechanical System) devices are used in a majority of applications [13]. The integration of gyroscope measurement errors will lead to an accumulating error in the calculated orientation. Therefore, gyroscopes alone cannot provide an absolute measurement of orientation. An accelerometer and magnetometer will measure the earth’s gravitational and magnetic fields respectively and so provide an absolute reference of orientation. However, they are likely to be subject to high levels of noise; for example, accelerations due to motion will corrupt measured direction of gravity. The task of an orientation filter is to compute a single estimate of orientation through the optimal fusion of gyroscope, accelerometer and magnetometer measurements.
The Kalman filter [14] has become the accepted basis for the majority of orientation filter algorithms [4, 15, 16, 17] and commercial inertial orientation sensors; xsens [18], micro-strain [19], VectorNav [20], Intersense [21], PNI [22] and Crossbow [23] all produce systems founded on its use. The widespread use of Kalman-based solutions are a testament to their accuracy and effectiveness, however, they have a number of disadvantages. They can be complicated to implement which is reflected by the numerous solutions seen in the subject literature [3, 4, 15, 16, 17, 24, 25, 26, 27, 28, 29, 30, 31, 32]. The linear regression iterations, fundamental to the Kalman process, demand sampling rates far exceeding the subject bandwidth; for example, a sampling rate between 512 Hz [18] and 30 kHz [19] may be used for a human motion caption application. The state relationships describing rotational kinematics in three-dimensions typically require large state vectors and an extended Kalman filter implementation [4, 17, 24] to linearise the problem.
These challenges demand a large computational load for implementation of Kalman-based solutions and provide a clear motivation for alternative approaches. Many previous approaches to address these issues have implemented either fuzzy processing [2, 5] or fixed filters [33] to favour accelerometer measurements of orientation at low angular velocities and the integrated gyroscope measurements at high angular velocities. Such an approach is simple but may only be effective under limited operating conditions. Bachman et al [34] proposed an alternative approach where the filter achieves an optimal fusion of measurements data at all angular velocities. However, the process requires a least squares regression, which also brings in an associated computational load. Mahony et al [35] developed the complementary filter which is shown to be an efficient and effective solution; however, performance is only validated for an IMU.
This report introduces novel orientation filter that is applicable to both IMUs and MARG sensor arrays addressing issues of computational load and parameter tuning associated with Kalman-based approaches. The filter employs a quaternion representation of orientation (as in: [34, 17, 24, 30, 32]) to describe the coupled nature of orientations in three-dimensions and is not subject to the problematic singularities associated with an Euler angle representation¹ .
A complete derivation and empirical evaluation of the new filter is presented. Its performance is benchmarked against an existing commercial filter and verified with optical measurement system. Innovative aspects of the proposed filter include: a single adjustable parameter defined by observable systems characteristics; an analytically derived and optimised gradient-descent algorithm enabling performance at low sampling rates; an on-line magnetic distortion compensation algorithm; and gyroscope bias drift compensation.

## 2 Quaternion representation

A quaternion is a four-dimensional complex number that can be used to represent the orientation of a ridged body or coordinate frame in three-dimensional space. An arbitrary orientation of frame B relative to frame A can be achieved through a rotation of angle θ around an axis Arˆ defined in frame A. This is represented graphically in figure 1 where the mutually orthogonal unit vectors xÂ, yÂ and zÂ, and xˆB, yˆB and zˆB define the principle axis of coordinate frames A and B respectively. The quaternion describing this orientation, A Bqˆ,
is defined by equation (1) where rx, ry and rz define the components of the unit vector Arˆ in the x, y and z axes of frame A respectively. A notation system of leading super-scripts and sub-scripts adopted from Craig [37] is used to denote the relative frames of orientations and vectors. A leading sub-script denotes the frame being described and a leading super-script denotes the frame this is with reference to. For example, A
Bqˆ describes the orientation of frame B relative to frame A and Arˆ is a vector described in frame A. Quaternion arithmetic often requires that a quaternion describing an orientation is first normalised. It is therefore conventional for all quaternions describing an orientation to be of unit length.

A
Bqˆ =
q1 | q2 | q3 | q4
=
cos θ
2 | −rxsinθ
2 | −rysinθ
2 | −rzsinθ
2
(1)

The quaternion conjugate, denoted by ∗ , can be used to swap the relative frames described by an orientation. For example, B

Aqˆ is the conjugate of A
Bqˆ and describes the orientation of frame A relative to frame B. The conjugate of A Bqˆ is defined by equation (2).

A
Bqˆ

∗ =
B
Aqˆ =
q1 | −q2 | −q3 | −q4
(2)

1Kuipers [36] offers a comprehensive introduction to this use of quaternions.

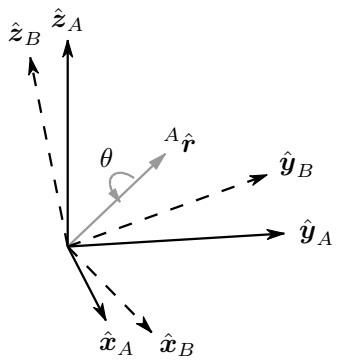
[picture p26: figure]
yÂ; yˆB; Arˆ; xÂ; xˆB; zÂ zˆB

Figure 1: The orientation of frame B is achieved by a rotation, from alignment with frame A, of angle θ around the axis Ar.

The quaternion product, denoted by ⊗, can be used to define compound orientations. For example, for two orientations described by A
Bqˆ and B

C qˆ, the compounded orientation A
Cqˆ
can be defined by equation (3).

A
Cqˆ =

B
C qˆ ⊗

A
Bqˆ | (3)

For two quaternions, a and b, the quaternion product can be determined using the Hamilton rule and defined as equation (4). A quaternion product is not commutative; that is, a ⊗ b 6= b ⊗ a.

a ⊗ b =

a1 | a2 | a3 | a4
⊗
b1 | b2 | b3 | b4

=

a1b1 − a2b2 − a3b3 − a4b4
a1b2 + a2b1 + a3b4 − a4b3
a1b3 − a2b4 + a3b1 + a4b2
a1b4 + a2b3 − a3b2 + a4b1

T
(4)

A three dimensional vector can be rotated by a quaternion using the relationship described in equation (5) [36]. Av and Bv are the same vector described in frame A and frame B respectively where each vector contains a 0 inserted as the first element to make them 4 element row vectors.

Bv =

A
Bqˆ ⊗

Av ⊗

A
Bqˆ

∗
(5)

The orientation described by A

Bqˆ can be represented as the rotation matrix A BR defined
by equation (6) [36].

A
BR =

2q

2
1 − 1 + 2q

2
2

2(q2q3 + q1q4) 2(q2q4 − q1q3) 2(q2q3 − q1q4) 2q

2
1 − 1 + 2q

2
3

2(q3q4 + q1q2)
2(q2q4 + q1q3) 2(q3q4 − q1q2) 2q

2
1 − 1 + 2q

2
4

- (6)

Euler angles ψ, θ and φ in the so called aerospace sequence [36] describe an orientation of frame B achieved by the sequential rotations, from alignment with frame A, of ψ around zˆB, θ around yˆB, and φ around xˆB. This Euler angle representation of A Bqˆ is defined by
equations (7), (8) and (9).

ψ = Atan2
2q2q3 − 2q1q4, 2q

2
1 + 2q

2
2 − 1
(7)

θ = −sin⁻¹
(2q2q4 + 2q1q3) | (8)

φ = Atan2
2q3q4 − 2q1q2, 2q

2
1 + 2q

2
4 − 1
(9)

## 3 Filter derivation

### 3.1 Orientation from angular rate

A tri-axis gyroscope will measure the angular rate about the x, y and z axes of the senor
frame, termed ωx, ωy and ωz respectively. If these parameters (in rads⁻¹ | ) are arranged into
the vector Sω defined by equation (10), the quaternion derivative describing the rate of
change of orientation of the earth frame relative to the sensor frame S | Eq˙ can be calculated
[38] as equation (11).

Sω =

0 ωx | ωy | ωz
(10)

S
Eq˙ =

1
2

S
Eqˆ ⊗
Sω | (11)

The orientation of the earth frame relative to the sensor frame at time t,

E
| S qω,t, can
be computed by numerically integrating the quaternion derivative S | Eq˙ω,t as described by
equations (12) and (13) provided that initial conditions are known. In these equations, Sωt
is the angular rate measured at time t, ∆t is the sampling period and S | Eqêst,t-1 is the previous
estimate of orientation. The sub-script ω indicates that the quaternion is calculated from angular rates.

S
Eq˙ω,t =

1
2

S
Eqêst,t-1 ⊗
Sωt | (12)

S
Eqω,t =

S
Eqêst,t-1 +

S
Eq˙ω,t∆t | (13)

### 3.2 Orientation from vector observations

A tri-axis accelerometer will measure the magnitude and direction of the field of gravity in the sensor frame compounded with linear accelerations due to motion of the sensor. Similarly, a tri-axis magnetometer will measure the magnitude and direction of the earth’s magnetic field in the sensor frame compounded with local magnetic flux and distortions. In the context of an orientation filter, it will initially be assumed that an accelerometer will measure only gravity, a magnetometer will measure only the earth’s magnetic field.

If the direction of an earth’s field is known in the earth frame, a measurement of the field’s direction within the sensor frame will allow an orientation of the sensor frame relative to the earth frame to be calculated. However, for any given measurement there will not be a unique sensor orientation solution, instead there will infinite solutions represented by all those orientations achieved by the rotation the true orientation around an axis parallel with the field. In some applications it may be acceptable to use an Euler angle representation allowing an incomplete solution to be found as two known Euler angles and one unknown [5]; the unknown angle being the rotation around an axis parallel with the direction of the field. A quaternion representation requires a complete solution to be found. This may be achieved through the formulation of an optimisation problem where an orientation of the sensor, S Eqˆ,
is that which aligns a predefined reference direction of the field in the earth frame, Edˆ, with the measured direction of the field in the sensor frame, Ssˆ, using the rotation operation described by equation (5). Therefore S
Eqˆ may be found as the solution to (14) where equation
(15) defines the objective function. The components of each vector are defined in equations
(16) to (18).

min

S
E

qˆ∈<⁴

f(

S
Eqˆ,

Edˆ,
S
sˆ) | (14)

f(

S
Eqˆ,

Edˆ,
S

sˆ) = S
Eqˆ

∗ ⊗

Edˆ⊗
S
Eqˆ −

S
sˆ | (15)

S
Eqˆ =
q1 | q2 | q3 | q4
(16)

Edˆ=

0 dx | dy | dz
(17)

S
sˆ =
0 sx | sy | sz
(18)

Many optimisation algorithms exist but the gradient descent algorithm is one of the simplest to both implement and compute. Equations (19) describes the gradient descent algorithm for n iterations resulting in an orientation estimation of S
Eqˆn+1 based on an ‘initial guess’ orientation S
Eqˆ0 and a step-size µ. Equation (20) computes the gradient of the solution surface defined by the objective function and its Jacobian; simplified to the 3 row vectors defined by equations (21) and (22) respectively.

S
Eqk+1 =

S
Eqˆk − µ

∇f(

S
Eqˆk
,

Edˆ,
Ssˆ)

∇f(

S
E

qˆk
,

Edˆ,
Ssˆ)
, k = 0, 1, 2...n | (19)

∇f(

S
Eqˆk
,

Edˆ,
S
sˆ) = J

T
(

S
Eqˆk
,

Edˆ)f(
S
Eqˆk
,

Edˆ,
S
sˆ) | (20)

f(

S
Eqˆk
,

Edˆ,
S
sˆ) =

2dx(

1
2 − q

2
3 − q
2/4) + 2dy(q1q4 + q2q3)+
2dx(q2q3 − q1q4) + 2dy(

1
2 − q

2
2 − q
2/4)+
2dx(q1q3 + q2q4) + 2dy(q3q4 − q1q2)+

2dz(q2q4 − q1q3) − sx
2dz(q1q2 + q3q4) − sy
2dz(

1
2 − q

2
2 − q

2/3) − sz

(21)

J(

S
Eqˆk,

Edˆ) =

2dyq4 − 2dzq3 | 2dyq3 + 2dzq4
−2dxq4 + 2dzq2 | 2dxq3 − 4dyq2 + 2dzq1
2dxq3 − 2dyq2 | 2dxq4 − 2dyq1 − 4dzq2
−4dxq3 + 2dyq2 − 2dzq1 | −4dxq4 + 2dyq1 + 2dzq2
2dxq2 + 2dzq4 | −2dxq1 − 4dyq4 + 2dzq3
2dxq1 + 2dyq4 − 4dzq3 | 2dxq2 + 2dyq3

(22)

Equations (19) to (22) describe the general form of the algorithm applicable to a field predefined in any direction. However, if the direction of the field can be assumed to only have components within 1 or 2 of the principle axis of the global coordinate frame then the equations simplify. An appropriate convention would be to assume that the direction of gravity defines the vertical, z axis as shown in equation (23). Substituting Egˆ and normalised accelerometer measurement Sâ for Edˆ and Ssˆ respectively, in equations (21) and (22) yields equations (25) and (26).

E
gˆ =
0 0 0 1
(23)

Sâ =

0 ax | ay | az
(24)

fg(

S
Eqˆ,

Sâ) =

2(q2q4 − q1q3) − ax
2(q1q2 + q3q4) − ay
2( ¹
2 − q

2
2 − q
2/3) − az

- (25)

Jg(

S
Eqˆ) =
−2q3 | 2q4 | −2q1 | 2q2
2q2 | 2q1 | 2q4 | 2q3
0 | −4q2 | −4q3 | 0

- (26)

The earth’s magnetic field can be considered to have components in one horizontal axis and the vertical axis; the vertical component due to the inclination of the field which is between 65◦ and 70◦
to the horizontal in the UK [39]. This can be represented by equation (27). Substituting Eˆb and normalised magnetometer measurement Smˆ for Edˆ and Ssˆ respectively, in equations (21) and (22) yields equations (29) and (30).

Eˆb =

0 bx 0 bz
(27)

Smˆ =

0 mx | my | mz
(28)

fb(

S
Eqˆ,

Eˆb,
Smˆ ) =

2bx(0.5 − q

2
3 − q

2/4) + 2bz(q2q4 − q1q3) − mx 2bx(q2q3 − q1q4) + 2bz(q1q2 + q3q4) − my 2bx(q1q3 + q2q4) + 2bz(0.5 − q

2
2 − q

2/3) − mz

- (29)

Jb(

S
Eqˆ,

Eˆb) =

−2bzq3 | 2bzq4 | −4bxq3 − 2bzq1
−2bxq4 + 2bzq2 | 2bxq3 + 2bzq1 | 2bxq2 + 2bzq4
2bxq3 | 2bxq4 − 4bzq2 | 2bxq1 − 4bzq3
| | −4bxq4 + 2bzq2
| | −2bxq1 + 2bzq3
| | 2bxq2

(30)

As has already been discussed, the measurement of gravity or the earth’s magnetic field alone will not provide a unique orientation of the sensor. To do so, the measurements and reference directions of both fields may be combined as described by equations (31) and (32). Whereas the solution surface created by the objective functions in equations (25) and
(29) have a minimum defined by a line, the solution surface define by equation (31) has a minimum define by a single point, provided that bx 6= 0.

fg,b(

S
Eqˆ,

Sâ,

Eˆb,

Smˆ ) =
fg(

S
Eqˆ,

Sâ)
fb(

S
Eqˆ,

Eˆb,
Smˆ )
(31)

Jg,b(

S
Eqˆ,

Eˆb) =
J

T
g

(

S
Eqˆ)
J

T
b

(

S
Eqˆ,

Eˆb)

(32)

A conventional approach to optimisation would require multiple iterations of equation
(19) to be computed for each new orientation and corresponding senor measurements. Efficient algorithms would also require the step-size µ to be adjusted each iteration to an optimal value; usually obtained based on the second derivative of the objective function, the Hessian. However, these requirements considerably increase the computational load of the algorithm and are not necessary in this application. It is acceptable to compute one iteration per time sample provided that the convergence rate governed by µt

is equal or greater than
the physical rate of change of orientation. Equation (33) calculates the estimated orientation S
Eq∇,t computed at time t based on a previous estimate of orientation S
Eqêst,t-1
and the
objective function gradient ∇f defined by sensor measurements Saˆt and Smˆ t sampled at time t. The form of ∇f is chosen according to the sensors in use, as shown in equation (34). The sub-script ∇ indicates that the quaternion is calculated using the gradient descent algorithm.

S
Eq∇,t =

S
Eqêst,t-1 − µt

∇f

# k∇fk

(33)

∇f =

J

T
g

(

S
Eqêst,t-1)fg(

S
Eqêst,t-1,

Saˆt)
J

T
g,b(

S
Eqêst,t-1,

Eˆb)fg,b(
S
Eqêst,t-1,

Sâ,

Eˆb,
Smˆ )

(34)

An optimal value of µt can be defined as that which ensures the convergence rate of S
Eq∇,t
is limited to the physical orientation rate as this avoids overshooting due an unnecessarily large step size. Therefore µt can be calculated as equation (35) where ∆t is the sampling period and S
Eq˙ω,t is the physical orientation rate measured by gyroscopes and α is an augmentation of µ to account for noise in accelerometer and magnetometer measurements.

µt = α

S
Eq˙ω,t
∆t, α > 1 | (35)

### 3.3 Filter fusion algorithm

An estimated orientation of the sensor frame relative to the earth frame, S | Eqest,t, is obtained
through the fusion of the orientation calculations, S
Eqω,t and S | Eq∇,t; calculated using equations
(13) and (33) respectively. The fusion of S

Eqˆω,t and S
Eq∇,t is described by equation (36) where γt and (1 − γt) are weights applied to each orientation calculation.

S
Eqest,t = γt

S
Eq∇,t + (1 − γt)

S
Eqω,t, 0 ≤ γt ≤ 1 | (36)

An optimal value of γt can be defined as that which ensures the weighted divergence of S

Eqω is equal to the weighted convergence of S
Eq∇. This is represented by equation (37) where µt
∆t

is the convergence rate of S

Eq∇ and β is the divergence rate of S Eqω expressed as
the magnitude of a quaternion derivative corresponding to the gyroscope measurement error. Equation (37) can be rearranged to define γt as equation (38).

(1 − γt)β = γt

µt
∆t

(37)

γt =

β

µt
∆t + β

(38)

Equations (36) and (38) ensure the optimal fusion of S

Eqω,t and S
Eq∇,t assuming that the
convergence rate of S
Eq∇ governed by α is equal or greater than the physical rate of change of orientation. Therefore α has no upper bound. If α is assumed to be very large then µt

, defined by equation (35), also becomes very large and the orientation filter equations simplify. A large value of µt used in equation (33) means that S
Eqêst,t-1 becomes negligible and the equation can be re-written as equation (39).

S
Eq∇,t ≈ −µt

∇f

# k∇fk

(39)

The definition of γt

in equation (38) also simplifies as the β term in the denominator becomes negligible and the equation can be rewritten as equation (40). It is possible from equation (40) to also assume that γt ≈ 0.

γt ≈

β∆t
µt

(40)

Substituting equations (13), (39) and (40) into equation (36) directly yields equation (41). It is important to note that in equation (41), γt has been substituted as both as equation (39) and 0.

S
Eqest,t =

β∆t
µt
−µt

∇f

# k∇fk

+ (1 − 0)
S
Eqêst,t-1 +

S
Eq˙ω,t∆t
(41)

Equation (41) can be simplified to equation (42) where S Eqėst,t is the estimated rate of change of orientation defined by equation (43) and S
E

˙qˆ,t is the direction of the error of S
Eqėst,t
defined by equation (44).

S
Eqest,t =

S
Eqêst,t-1 +

S
Eqėst,t∆t | (42)

S
Eqėst,t =

S
Eq˙ω,t − β

S
E
˙qˆ,t | (43)

S
E

˙qˆ,t =

∇f

# k∇fk

(44)

It can be seen from equations (42) to (44) that the filter calculates the orientation S
Eqest
by numerically integrating the estimated orientation rate S
Eq˙

est. The filter computes S
Eqėst
as the rate of change of orientation measured by the gyroscopes, S
Eq˙ω
, with the magnitude
of the gyroscope measurement error, β, removed in the direction of the estimated error, S
E

˙qˆ
,
computed from accelerometer and magnetometer measurements. Figure 2 shows a block diagram representation of the complete orientation filter implementation for an IMU.

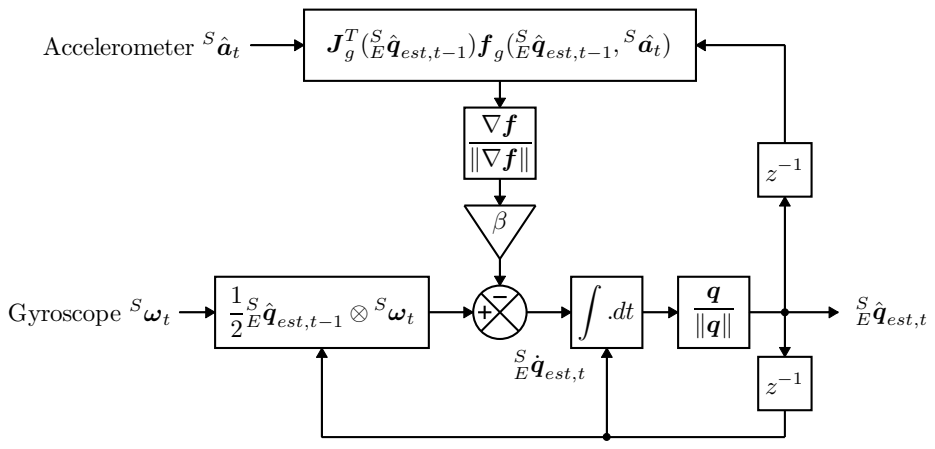
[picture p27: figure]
Accelerometer Saˆt; Gyroscope Sωt; S Eqêst,t; S Eq˙ est,t; S Eqêst,t−1 ⊗; Sωt; q kqk; S Eqêst,t−1; Saˆt)

Figure 2: Block diagram representation of the complete orientation filter for an IMU implementation

### 3.4 Magnetic distortion compensation

Measurements of the earth’s magnetic field will be distorted by the presence of ferromagnetic elements in the vicinity of the magnetometer. Investigations into the effect of magnetic distortions on an orientation sensor’s performance have shown that substantial errors may be introduced by sources including electrical appliances, metal furniture and metal structures within a buildings construction [40, 41]. Sources of interference fixed in the sensor frame, termed hard iron biases, can be removed through calibration [42, 43, 44, 45]. Sources of interference in the earth frame, termed soft iron, cause errors in the measured direction of the earth’s magnetic field. Declination errors, those in the horizontal plane relative to the earth’s surface, cannot be corrected without an additional reference of heading. Inclination errors, those in the vertical plane relative to the earth’s surface, may be compensated for as the accelerometer provides an additional measurement of the sensor’s attitude.
The measured direction of the earth’s magnetic field in the earth frame at time t,

Ehˆ
t

, can
be computed as the normalised magnetometer measurement, Smˆ t , rotated by the estimated orientation of the sensor provided by the filter, S
Eqêst,t-1; as described by equation (45). The effect of an erroneous inclination of the measured direction earth’s magnetic field, Ehˆ
t

, can
be corrected if the filter’s reference direction of the earth’s magnetic field, Eˆbt
, is of the same
inclination. This is achieved by computing Eˆbt as Ehˆ
t normalised to have only components in the earth frame x and z axes; as described by equation (46).

Ehˆ
t =
0 hx | hy | hz
=

S
Eqêst,t-1 ⊗

Smˆ t ⊗
S
Eqˆ

∗
est,t-1

(45)

Eˆbt =

0

p
h

2
x + h

2
y

0 hz

(46)

Compensating for magnetic distortions in this way ensures that magnetic disturbances are limited to only affect the estimated heading component of orientation. The approach also eliminates the need for the reference direction of the earth’s magnetic field to be predefined; a potential disadvantage of other orientation filter designs [17, 24].

### 3.5 Gyroscope bias drift compensation

The gyroscope zero bias will drift over time, with temperature and with motion. Any practical implementation of an IMU or MARG sensor array must account for this. An advantage of Kalman-based approaches is that they are able to estimate the gyroscope bias as an additional state within the system model [26, 30, 15, 24]. However, Mahony et al [35] showed that gyroscope bias drift may also be compensated for by simpler orientation filters through the integral feedback of the error in the rate of change of orientation. A similar approach will be used here.
The normalised direction of the estimated error in the rate of change of orientation, S
E

˙qˆ
,
may be expressed as the angular error in each gyroscope axis using equation (47); derived as the inverse to the relationship defined in equation (11). The gyroscope bias, Sωb, is represented by the DC component of Sω and so may removed as the integral of Sω weighted by an appropriate gain, ζ. This would yield the compensated gyroscope measurements Sωc, as shown in equations (48) and (49). The first element of Sωc is always assumed to be 0.

Sω,t = 2S
Eqˆ

∗
est,t-1 ⊗

S
E
˙qˆ,t | (47)

Sωb,t = ζ

X

t

Sω,t∆t | (48)

Sωc,t =

Sωt −

Sωb,t | (49)

The compensated gyroscope measurements, Sωc, may then be used in place of the of the gyroscope measurements, Sω, in equation (11). The magnitude of the angular error in

each axis, Sω
is equal to a quaternion derivative of unit length. Therefore the integral gain ζ directly defines the rate of convergence of the estimated gyroscope bias, Sωb, expressed as the magnitude of a quaternion derivative. As this process requires the use of the filter estimate of a complete orientation, S
Eqêst, it is only applicable to a MARG implementation of the filter. Figure 3 shows a block diagram representation of the complete filter implementation for a MARG sensor array, including the magnetic distortion and gyroscope bias drift

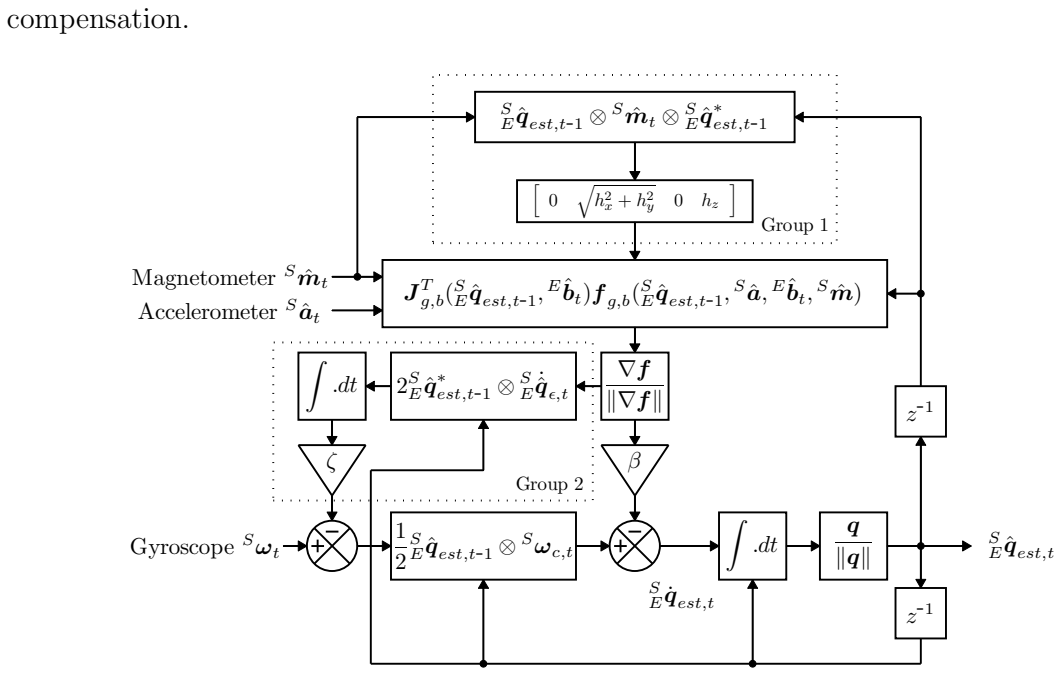
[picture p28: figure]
compensation.; Accelerometer Saˆt; Magnetometer Smˆ t; Gyroscope Sωt; S Eqêst,t; S Eq˙ est,t; S Eqêst,t-1 ⊗; Sωc,t; q kqk; S Eqêst,t-1; E ˆbt)fg,b( S Eqêst,t-1; Sâ,; E ˆbt; Smˆ ); Smˆ t ⊗; S Eqˆ; ∗ est,t-1; ∗ est,t-1 ⊗; ˙qˆ²,t Z .dt; Group 2; Group 1

Figure 3: Block diagram representation of the complete orientation filter for an MARG implementation including magnetic distortion (Group 1) and gyroscope drift (Group 2) compensation

### 3.6 Filter gains

The filter gain β represents all mean zero gyroscope measurement errors, expressed as the magnitude of a quaternion derivative. The sources of error include: sensor noise, signal aliasing, quantisation errors, calibration errors, sensor miss-alignment, sensor axis nonorthogonality and frequency response characteristics. The filter gain ζ represents the rate of convergence to remove gyroscope measurement errors which are not mean zero, also expressed as the magnitude of a quaternion derivative. These errors represent the gyroscope bias. It is convenient to define β and ζ using the angular quantities ωβ and ˙ωζ respectively, where ˜ωβ represents the estimated mean zero gyroscope measurement error of each axis and ω˙ ζ represents the estimated rate of gyroscope bias drift in each axis. Using the relationship described by equation (11), β may be defined by equation (50) where qˆ is any unit quaternion. Similarly, ζ may be described by equation (51).

β =

1
2

qˆ ⊗

0 ˜ωβ | ω˜β | ω˜β
=

r
3
4
ω˜β | (50)

ζ =

r
3
4
ω˜˙ ζ | (51)

## 4 Experimentation

### 4.1 Equipment

The filter was tested using the xsens MTx orientation sensor [18] containing 16 bit resolution tri-axis gyroscopes, accelerometers and magnetometers. The device and accompanying software offer a mode of operations where raw sensor data may be logged at a rate of 512 Hz and then post-processed to provide calibrated sensor measurements. The calibrated sensor measurements could then be processed by the proposed filter to provide the estimated orientation of the sensor. The software also incorporates a propriety Kalman-based orientation filter to provide an additional estimate orientation. As both the Kalman-based algorithm and proposed filter’s outputs could be computed using identical sensor data, the performance of each algorithm could be evaluated relative to one-another, independent of sensor performance.
A Vicon system, consisting of 8 MX3+ cameras connected to an MXultranet server
[46] and Nexus [47] software was used to provide reference measurement of the orientation sensor’s actual orientation. The system is an array of IR (Infrared) sensitive cameras with incorporated IR flood lights. The cameras are fixed at calibrated positions and orientations so that the measurement subject is within the field of view of multiple cameras. The Cartesian positions of IR reflective optical markers fixed to the measurement subject may then be computed in the coordinate frame of the camera array. Cameras were fixed at a height of approximately 2.5 m, evenly distributed around the perimeter of a 4 m by 4 m enclosure. Each camera was orientated to face toward the centre of the room, approximately 30◦
| to
60◦
to horizontal. Experiments were conducted with the measurement subject in the centre of the room at a height of approximately 1 m. To measure the orientation of the sensor, it was fixed to an optical orientation measurement platform specifically designed for this application. The system was used to log the positions of optical markers at a rate of 120 Hz.

### 4.2 Orientation from optical measurements

The orientation measurement platform is comprised of 3 500 mm, mutually orthogonal rods, rigidly connected at the central position along each length. Optical markers were positioned at both ends of each rod and the orientation sensor fixed to a platform at the point where the rods coincide. The platform was constructed from an aluminium central hub, carbon fibre rods and assembled using adhesives to ensure that it had no magnetic properties that may interfere with the orientation sensor’s magnetometer. Additional optical markers were placed at arbitrary but dissimilar positions along the lengths of the rods to break the rotational symmetry and aid the identification of each rod within the measurement data. Figure 4 shows an annotated photograph of the orientation measurement platform where Cistart,

Ciend,

Cjstart,

Cjend,

Ckstart and Ckend define the measured position of each marker within the camera frame. These positions may be used to define 3 mutually orthogonal unit vectors,

CxˆM,

CyˆM, and CzˆM within the camera frame representing the direction the x, y and z axes of the orientation measurement platform coordinate frame; as described by equations (52),
(53) and (54). These vectors define the rotation matrix describing the orientation of the measurement platform in the camera frame; as shown in equation (55).

C xstart; C xend; C jstart; C jend; C zstart; C zend; Sensor

Figure 4: Photograph of the orientation measurement platform

CxˆM =

Ciend − Cistart
k

Ciend − Cistartk

(52)

CyˆM =

Cjend − Cjstart
k

Cjend − Cjstartk

(53)

CzˆM =

Ckend − Ckstart
k

Ckend − Ckstartk

(54)

C
MR =
CxˆM

CyˆM

CzˆM

(55)

Due to measurement errors and tolerances in the marker frame construction, the rotation matrix defined by equation (55) cannot be considered orthogonal and so does not represent a pure rotation. Bar-Itzhack provides a method [48] where by an optimal ‘best fit’ quaternion may be extracted from an imprecise and non-orthogonal rotation matrix. The method requires the construction of the symmetric 4 by 4 matrix, K, defined by equation (56), where rmn corresponds to the element of the mth row and n

th column of C
MR. The optimal
quaternion C
Mqˆ is found as the normalised Eigen vector corresponding to the maximum Eigen value of K. Equation (57) defines the optimal quaternion accounting the alternative quaternion element order convention assumed by the method, where v1, v2, v3 and v4 define elements of the normalised Eigen vector.

K =

1
3
r11 − r22 − r33 | r21 + r12 | r31 + r13 | r23 − r32
r21 + r12 | r22 − r11 − r33 | r32 + r23 | r31 − r13
r31 + r13 | r32 + r23 | r33 − r11 − r22 | r12 − r21
r23 − r32 | r31 − r13 | r12 − r21 | r11 + r22 + r33

(56)

C
Mqˆ =
v4 | v1 | v2 | v3
(57)

### 4.3 Calibration of frame alignments

In order to compare the optical measurement of the platform orientation in the camera frame,

C
Mqˆ, and the orientation filter’s estimated orientation of the earth in the sensor frame, S
Eqêst,
it is necessary to know the alignment of the earth frame relative to the camera frame, C Eqˆ,
and the alignment of the measurement platform relative to the sensor frame, S
Mqˆ. Once these
quantities are found the optical measurement of the sensor frame orientation in the earth frame, S
Eqˆmeas, may be defined by equation (58). Although the use of optical measurement equipment in this application is documentaed [26, 24, 41], little discussion is offered on the calibration of these two quantities.

S
Eqˆmeas =

C
Eqˆ ⊗

M
C qˆ ⊗

S
Mqˆ | (58)

The earth frame x and z axes are defined by the earth’s magnetic and gravitational fields respectively. Measurements of these fields in the camera frame can be used to define the alignment C
Eqˆ. The direction of gravity was measured using a pendulum constructed from a 1 m length of cotton thread with a small weight fixed to one end. Optical markers where fixed at either end of the length of cotton and the pendulum left to come to rest. Additional optical markers were required at arbitrary fixed positions relative to the static pendulum to break the rotational symmetry of the optical marker constellation. Figure 5 shows an annotated photograph of the pendulum where Cpstart and Cpend define the position of the optical markers in the camera frame. The mean position of each marker over a period of time defines the direction of the pendulum in the camera frame, Cpˆ. This directly defines the earth frame z axis in the camera frame, CzÊ; as shown in equation (59).

Cpˆ =

Cp¯end − Cp¯start
k

Cp¯end − Cp¯startk

=

CzÊ =

z1
z2
z3

- (59)

The direction of earth’s magnetic field was measured using a magnetic compass constructed from a 1 m carbon-fibre rod with neodymium magnets fixed to each end; polarising each end to either magnetic north or south. The compass was hung from a 1 m length of cotton thread and left to come to rest. Optical markers were fixed to either end of the rod as well as to an arbitrary position along the length, but off-set form the rod’s axis, to beak the rotational symmetry optical marker constellation. Figure 60 shows an annotated photograph of the compass where Ccstart and Ccend define the position of the optical markers

C pend

C pstart


Figure 5: Photograph of the pendulum and optical markers used to measure the direction of gravity in the camera frame

in the camera frame. The mean position of each marker over a period of time define the direction of the compass in the camera frame, Ccˆ; as shown in equation (60).

C cstart; C cend

Figure 6: Photograph of the magnetic compass and optical markers used to measure the direction of the earth’s magnetic field in the camera frame

C
cˆ =

Cc¯end − Cc¯start
k

Cc¯end − Cc¯startk

(60)

Due to measurement errors and the imbalance of the suspended magnetic compass, Ccˆ cannot be assumed to be orthogonal to the direction of gravity defined by Cpˆ and so cannot be used to directly define the earth x axis. The non-orthogonal component of Ccˆ can be computed as the vector projection of Ccˆ on Cpˆ. This can then be removed from Ccˆ to define the the earth x axis direction in the camera frame, CxE; as shown in equation (61). Once normalised, this defines the earth x axis; CxÊ, as shown in equation (62).

CxE =

C
cˆ −

Ccˆ ·

Cpˆ
k

Cpˆk

2

Cpˆ | (61)

CxÊ =

CxE
k

CxEk

=

x1
x2
x3

- (62)

The earth frame y axis in the camera frame, CyÊ, can be calculated as the vector that is orthogonal to both CxÊ and CzÊ and so be defined by equation (63) where signs are chosen to satisfy the relative axis direction direction convention. The alignment of the earth frame may be defined as the rotation matrix C

ER, constructed from CxÊ,

CyÊ, and CzÊ. The
quaternion representation, C
Eqˆ, can then be extracted form this using Bar-Itzhack’s method [48].

CyÊ =

±

p
1 − x

2
1 − z

2
1
±

p
1 − x

2
2 − z

2
2
±

p
1 − x

2
3 − z

2
3
- ,
CxÊ ·

CyÊ = 0,

CzÊ ·

CyÊ = 0 | (63)

C
ER =
CxÊ

CyÊ

CzÊ

(64)

In order to find the alignment S
Mqˆ it is assumed that the static error of the orientation filter’s Kalman-based algorithm is mean zero. The mean algorithm’s output, S

Eqˆ¯Kalman, was
computed for the measurement platform held stationary for a period of approximate 10 seconds. This was used with the alignment E

Cqˆ and optical measurement C Mqˆ to define the
alignment of the measurement platform in the sensor frame, S Mqˆ, as equation (65).

S
Mqˆ =

C
Mqˆ ⊗

E
Cqˆ ⊗

S
Eqˆ¯Kalman | (65)

### 4.4 Experimental proceedure

The optical measurement data and raw orientation sensor data were logged simultaneously. The raw orientation sensor data was then processed by the accompanying software to provide the calibrated sensor data and Kalman-based algorithm output. This data then synchronised the optical measurement data, with the optical measurement data interpolated to match the higher sampling rate of the orientation sensor data. The calibrated sensor data was then processed through both the IMU and MARG implementations of the proposed orientation filter and calibrated orientation measurements were extracted from the optical measurement data using the methods described in sections 4.2 and 4.3.
The proposed filter’s gain β was set to 0.033 for the IMU implementation and 0.041 for the MARG implementation. Trials summarised in section 5.3, found these values to provide optimal performance. However, an initial value of 2.5 was used for the first 10 seconds of any experiment to ensure the convergence of algorithm states from initial conditions. The gain ζ, applicable to the MARG implementation of the proposed filer, was set to 0 as the calibrated orientation sensor data was not subject to gyroscope bias drift.

Data was obtained for a sequence of rotations preformed by hand. The measurement platform was initially held stationary for 20 to 30 seconds to allow time for algorithm states to converge to steady-state values. The platform was then rotated 90◦ around its x axis, then 180◦

in the opposite direction, and then 90◦ to bring the platform back to the starting position. The platform was held stationary for 3 to 5 seconds between each rotation. This sequence was then repeated around the y and then z axes. The peak angular rate measured during each rotation was between 110◦/s and 190◦/s. The experiment was repeated 8 times to compile a dataset representative of system performance.

## 5 Results

It is common [24, 26, 18, 19, 20, 21] to quantify orientation sensor performance as the static and dynamic RMS (Root-Mean-Square) errors in the decoupled Euler parameters describing the pitch, roll, and heading components of an orientation. Pitch, φ, roll, θ and heading, ψ correspond to rotations around the sensor frame x, y, and z axis respectively. An Euler angle representation has the advantage that the decoupled angles may be more easily interpreted or visualised. The disadvantage of an Euler representation is that it fails to described the coupling between each of the parameters and will subject to large and erratic errors if the Euler angle sequence reaches a singularity.
Euler parameters were computed directly from quaternion data using equations (7), (8) and (9). A total of 4 sets of of Euler parameters were computed, corresponding to the calibrated optical measurements of orientation, the Kalman-based algorithm estimated orientation and the proposed filter estimates orientation for both the MARG and IMU implementations. The errors of estimated Euler parameters, φ

, θ and ψ
, were computed as the
difference between the Euler parameters of the calibrated optical measurements and those of each of the corresponding estimated values.

### 5.1 Typical results

Figures 7, 8 and 9 show results typical of the 8 experiments for both the Kalman-based algorithm and the proposed filter MARG implementation. In each figure, the 3 traces of the upper plot represent the optically measured angle, the Kalman-based algorithm estimated angle, and the proposed filter estimated angle. The 2 traces of the lower plot represent the calculated error in each of the estimated angles.

φ (degrees); Measured Kalman Proposed filter; Error; ε (degrees); time (seconds); Kalman Proposed filter; θ (degrees)

Measured and estimated angle φ

Figure 7: Typical results for measured and estimated angle φ (top) and error (bottom)

Measured and estimated angle θ

Figure 8: Typical results for measured and estimated angle θ (top) and error (bottom)

Measured and estimated angle ψ; ψ (degrees); Measured Kalman Proposed filter; Error; ψε (degrees); time (seconds); Kalman Proposed filter

Figure 9: Typical results for measured and estimated angle ψ (top) and error (bottom)

### 5.2 Static and dynamic performance

The static and dynamic RMS values of φ

, θ
, and ψ were calculated where a static state was assumed when the measured corresponding angular rate was < 5

◦/s, and a dynamic
state when ≥ 5

◦/s. This threshold was chosen to be suitably high enough above the noise floor of the data. Each RMS value was calculated for the period of time framing only the rotation sequence of the corresponding Euler parameter; as indicated in figures 7, 8 and
9. This was to prevent errors due to initial convergence or singularities in the Euler angle representation from corrupting results; that is, when θ = ±90. The results are summarised in table 1. Each value, represents the mean of all 8 experiments. Values of RMS[ψ

] were
not computed for the IMU implementation of the proposed filter as the filter cannot, nor is intended to, compensate for an accumulating error in this parameter.
Euler parameter | Kalman-based Proposed filter Proposed filter
| algorithm | (MARG) | (IMU)
RMS[φ
] static | 0.789◦ | 0.581◦ | 0.594◦
RMS[φ
] dynamic | 0.769◦ | 0.625◦ | 0.623◦
RMS[θ
] static | 0.819◦ | 0.502◦ | 0.497◦
RMS[θ
] dynamic | 0.847◦ | 0.668◦ | 0.668◦
RMS[ψ
] static | 1.150◦ | 1.073◦ | N/A
RMS[ψ
] dynamic | 1.344◦ | 1.110◦ | N/A

Table 1: Static and dynamic RMS error of Kalman-based algorithm and proposed filter IMU and MARG implementations

Results indicate that the proposed filter achieves higher levels of accuracy than the Kalman-based algorithm. The manufacturer of orientation sensor specify the typical performance of the Kalman-based algorithm as having a static RMS error of < 0.5

◦
in φ and

θ, and < 1

◦
in ψ; and a dynamic RMS error of < 2

◦
in φ, θ, and ψ [18]. These values do not conform with those listed in table 1. Other studies [49] have shown that accuracy may far less than that quoted by the manufacture and that quoted levels of accuracy are only achieved once the devices is recalibrated. The lower levels of accuracy in the heading, ψ

, are to due characteristics of the sensor’s measurements of the earth’s magnetic field. The inclination of the earth’s magnetic field during testing was between 65◦ and 70◦
to the
horizontal [39]. As a consequence the component of the magnetic flux vector available as a reference of heading is relatively small. The larger component of the vector serves as an additional reference for pitch, φ, and roll, θ, alongside the reference measurement of gravity; hence errors in pitch, φ

, and roll, θ
, may be expected to be less than those in heading, ψ
The magnetometer is specified [18] as having a bandwidth of 10 Hz which, relative to the 30 Hz and 40 Hz bandwidth of the accelerometer and gyroscope respectively, suggests an increased heading error, ψ

, in dynamic conditions.

### 5.3 Filter gain vs. performance

The results of an investigation into the effect of the filter adjustable parameter, β, on the proposed filter performance are summarised in Figure 10. The static and dynamic performance is quantified as the mean of the corresponding RMS values of φ and θ

, for the IMU
implementation and φ

, θ and φ

for the MARG implementation. The experimental data was processed though the separate proposed filter IMU and MARG implantations, using fixed values of β between 0 to 0.5. There is a clear optimal value of β for each filter implementation; high enough to minimises errors due to integral drift but sufficiently low enough that unnecessary noise is not introduced by large steps of gradient descent iterations.

mean[ RMS[; ε], RMS[θ; ε] ] (degrees); Static performance Dynamic performance; ε], RMS[; ψε] ] (degrees)

Effect of β on proposed filter performance (IMU)

Effect of β on proposed filter performance (MARG)

Figure 10: The effect of the adjustable parameter, β, on the performance of the proposed filter IMU (left) and MARG (right) implementations

### 5.4 Sampling rate vs. performance

The results of an investigation into the effect of sampling rate on filter performance is summarised in Figure11. The experimental data was processed though the separate proposed filter IMU and MARG implantations, using the previously defined, optimal values β where the experimental data was decimated to simulate sampling rates between 1Hz and 512 Hz. It can be seen from Figure11 that the propsoed filter acheives similar levels of performance at 50 Hz as at 512 Hz. Both filter implemntation are able to acheive a static error < 2

◦
and dynamic error < 7
- while sampling at 10 Hz. This level of accracuy may be sufficent be effective for applications such as human motion capture.

Sampling rate (Hz); mean[ RMS[; ε], RMS[θ; ε] ] (degrees); Static performance Dynamic performance; ε], RMS[; ψε] ] (degrees)

Effect of sampling rate on proposed filter performance (IMU)

Effect of sampling rate on proposed filter performance (MARG)

Figure 11: The effect of sampling rate on the performance of the proposed filter IMU (left) and MARG (right) implementations

### 5.5 Gyroscope bias drift

The calibrated gyrscope data used by the propsoed filter did not contain any bias errors. To investiagate the propsoed filter’s ability to compensate for bias drift, errors were artifically introduced to the 8 experimental datasets. A constant drift of 0.2

◦/s/s was introduced to
the gyroscope x axis measuremnts, ωx and a constant bias error of −0.2

◦/s as added to the
gyroscope x axis measuremnts, ωy. The filter gain ζ was set to 0 for the first 10 seconds of each experiment whilst the filter states converge from intial conditions. After this a value of 0.015 was used corrisponding a maximum convergene rate of the esitmated gyroscope bias of 1◦/s/s.
Figure 12 shows resutls typical of teh 8 experimetns, showing the gyroscope x and y axis bias estimated by the filter, plotted against the actual. From these results, the fitler can be seen to scuseffuly esitmate teh gyroscope biases witht eh rate limtied rate of convergese. The filter performance under these conditions was constent with that described in Table 1.

Gyroscope bias drift compensation; degrees/s; seconds; ωx,b (actual) ωx,b (estimated) ωy,b (actual) ωy,b (estimated)

Figure 12: Filter tracking of gyroscope bias drift

## 6 Discussion

The derivation of the filter initially assumed that the accelerometer and magnetometer would only measure gravity and the earth’s magnetic field. In practise, accelerations due to motion will result in an erroneous observed direction of gravity and so a potentially corrupt the estimated attitude and local magnetic distortions may still corrupt the estimated heading. In many applications it can be assumed that accelerations due to motion and local magnetic distortions are present for only short periods of time. Therefore the magnitude of the filter gain β may be chosen low enough that the divergence caused by the erroneous gravitational and magnetic field observations is reduced to an acceptable level over the period. The minimum acceptable value of β is limited by the gyroscope measurement error. In many applications it may be beneficial to use dynamic values of gains β and ζ. This will the influence accelerometers and magnetometers have on the estimated orientation to be reduced during potential problematic periods; for example, when large accelerations are detected. The use of large gains during the filter initialisation may also improve the filter’s convergence from initial conditions. For example, it was found that a β and β gain of 10 enabled the filter states to converge within 5 seconds when initiated with a gyroscope bias error of 1000 deg/s in each axis.
The structure of the filter implantation for a MARG sensor array is similar to that proposed by Bachman et al [34]. Both filters estimate the gyroscope measurement error as the gradient of a error surface created by the magnetometer and accelerometer measurements. Bachman’s filter computes this using a Gauss-Newton approach which requires numerical differentiation and a matrix inversion. The filter proposed in this report uses an analytical derivation of the Jacobian and operates on a normalised gradient of the error surface. As a result, the filter proposed in this paper provides a substantial reduction in computational load and enables the derivation of an optimal filter gain based on system characteristics. Appendix A and B describe the filter IMU and MARG implementations respectively, each implemented in C where the code has been optimised to reduce the number of arithmetic operations at the expense of data memory. The IMU implementation requires 108 arithmetic operations each filter update, and the MARG implementation requires 277 arithmetic operations per filter update; which includes the magnetic distortion and gyroscope drift compensation. These low computational requirements make the algorithm accessible for low power embedded systems systems enabling the use of low cost, low power hardware. The experimental procedure used to evaluated the filter performances has a number of limitations; the filter performance was not evaluated for simultaneous rotations around more than one rotational axis and rotational velocities were limited to short periods and in magnitude. These limitations were necessary so that repeatable and quantifiable and practical.

## 7 Conclusions

In this work, we have introduced a novel orientation filter, applicable to both IMUs and MARG sensor arrays, that significantly ameliorates the computational load and parameter tuning burdens associated with conventional Kalman-based approaches. The filter is based on a Newton optimization using an analytic formulation of the gradient that is derived from a quaternion representation of motion. Novel aspects of the filter include:

- Analytic derivation of the Jacobian matrix, which eliminates significant computational load, allowing implementation at lower sampling frequencies and onto lower power, smaller platforms.
- The need to tune only one or two filter gains (β and ζ)), defined by the gyroscope measurement error. Least squares curve fitting and complex tuning processes are therefore eliminated.

The filter derivation, magnetic distortion anf gyroscope bias drift compensation, and experimental testing have been detailed. Empirical testing and benchmarking has shown that the filter performs as well as a high quality commercial Kalman-based system, even with a full order of magnitude in reduction of sampling rate. The filter is both simple to implement and simple to tune. The implications of the low computational load and ability to operate at low sampling rates open a very wide range of new opportunities for the use of IMU and MARG sensor arrays in real-time applications. Applications where limited power or processing resources may be available are particularly well suited for the new filter. The filter also has great potential to alleviate computational load for applications that demand extremely high sampling rates.

## References

[1] Mark Euston, Paul Coote, Robert Mahony, Jonghyuk Kim, and Tarek Hamel. A complementary filter for attitude estimation of a fixed-wing uav with a low-cost imu. In 6th International Conference on Field and Service Robotics, July 2007.
[2] Sung Kyung Hong. Fuzzy logic based closed-loop strapdown attitude system for unmanned aerial vehicle (uav). Sensors and Actuators A: Physical, 107(2):109 – 118, 2003.

[3] A. Kallapur, I. Petersen, and S. Anavatti. A robust gyroless attitude estimation scheme for a small fixed-wing unmanned aerial vehicle. pages 666 –671, aug. 2009.
[4] B. Barshan and H. F. Durrant-Whyte. Inertial navigation systems for mobile robots. 11(3):328–342, June 1995.
[5] L. Ojeda and J. Borenstein. Flexnav: fuzzy logic expert rule-based position estimation for mobile robots on rugged terrain. In Proc. IEEE International Conference on Robotics and Automation ICRA ’02, volume 1, pages 317–322, May 11–15, 2002.
[6] David H. Titterton and John L. Weston. Strapdown inertial navigation technology. The Institution of Electrical Engineers, 2004.
[7] S. Beauregard. Omnidirectional pedestrian navigation for first responders. In Proc. 4th Workshop on Positioning, Navigation and Communication WPNC ’07, pages 33–36, March 22–22, 2007.
[8] H. J. Luinge and P. H. Veltink. Inclination measurement of human movement using a 3-d accelerometer with autocalibration. 12(1):112–121, March 2004.
[9] Huiyu Zhou and Huosheng Hu. Human motion tracking for rehabilitation–a survey. volume 3, pages 1 – 18, 2008.
[10] E. A. Heinz, K. S. Kunze, M. Gruber, D. Bannach, and P. Lukowicz. Using wearable sensors for real-time recognition tasks in games of martial arts - an initial experiment. In Proc. IEEE Symposium on Computational Intelligence and Games, pages 98–102, May 22–24, 2006.
[11] J. E. Bortz. A new mathematical formulation for strapdown inertial navigation. (1):61– 66, January 1971.
[12] M B Ignagni. Optimal strapdown attitude integration algorithms. In Guidance, Control, and Dynamics, volume 13, pages 363–369, 1990.
[13] N. Yazdi, F. Ayazi, and K. Najafi. Micromachined inertial sensors. 86(8):1640–1659, August 1998.
[14] R. E. Kalman. A new approach to linear filtering and prediction problems. Journal of Basic Engineering, 82:35–45, 1960.
[15] E. Foxlin. Inertial head-tracker sensor fusion by a complementary separate-bias kalman filter. In Proc. Virtual Reality Annual International Symposium the IEEE 1996, pages 185–194,267, March 30–April 3, 1996.
[16] H. J. Luinge, P. H. Veltink, and C. T. M. Baten. Estimation of orientation with gyroscopes and accelerometers. In Proc. First Joint [Engineering in Medicine and Biology 21st Annual Conf. and the 1999 Annual Fall Meeting of the Biomedical Engineering Soc.] BMES/EMBS Conference, volume 2, page 844, October 13–16, 1999.

[17] J. L. Marins, Xiaoping Yun, E. R. Bachmann, R. B. McGhee, and M. J. Zyda. An extended kalman filter for quaternion-based orientation estimation using marg sensors. In Proc. IEEE/RSJ International Conference on Intelligent Robots and Systems, volume 4, pages 2003–2011, October 29–November 3, 2001.
[18] Xsens Technologies B.V. MTi and MTx User Manual and Technical Documentation. Pantheon 6a, 7521 PR Enschede, The Netherlands, May 2009.
[19] MicroStrain Inc. 3DM-GX3 -25 Miniature Attutude Heading Reference Sensor. 459 Hurricane Lane, Suite 102, Williston, VT 05495 USA, 1.04 edition, 2009.
[20] VectorNav Technologies, LLC. VN -100 User Manual. College Station, TX 77840 USA, preliminary edition, 2009.
[21] InterSense, Inc. InertiaCube2+ Manual. 36 Crosby Drive, Suite 150, Bedford, MA 01730, USA, 1.0 edition, 2008.
[22] PNI sensor corporation. Spacepoint Fusion. 133 Aviation Blvd, Suite 101, Santa Rosa, CA 95403-1084 USA.
[23] Crossbow Technology, Inc. AHRS400 Series Users Manual. 4145 N. First Street, San Jose, CA 95134, rev. c edition, February 2007.
[24] A. M. Sabatini. Quaternion-based extended kalman filter for determining orientation by inertial and magnetic sensing. 53(7):1346–1356, July 2006.
[25] H. J. Luinge and P. H. Veltink. Measuring orientation of human body segments using miniature gyroscopes and accelerometers. Medical and Biological Engineering and Computing, 43(2):273–282, April 2006.
[26] David Jurman, Marko Jankovec, Roman Kamnik, and Marko Topic. Calibration and data fusion solution for the miniature attitude and heading reference system. Sensors and Actuators A: Physical, 138(2):411–420, August 2007.
[27] Markus Haid and Jan Breitenbach. Low cost inertial orientation tracking with kalman filter. Applied Mathematics and Computation, 153(4):567–575, June 2004.
[28] D. Roetenberg, H. J. Luinge, C. T. M. Baten, and P. H. Veltink. Compensation of magnetic disturbances improves inertial and magnetic sensing of human body segment orientation. 13(3):395–405, September 2005.
[29] John L. Crassidis and Landis F. Markley. Unscented filtering for spacecraft attitude estimation. Journal of guidance, control, and dynamics, 26(4):536–542, 2003.
[30] D. Gebre-Egziabher, R.C. Hayward, and J.D. Powell. Design of multi-sensor attitude determination systems. Aerospace and Electronic Systems, IEEE Transactions on, 40(2):627 – 649, april 2004.

[31] N.H.Q. Phuong, H.-J. Kang, Y.-S. Suh, and Y.-S. Ro. A DCM based orientation estimation algorithm with an inertial measurement unit and a magnetic compass. Journal of Universal Computer Science, 15(4):859–876, 2009.
[32] Daniel Choukroun. Novel methods for attitude determination using vector observations. PhD thesis, Israel Institute of Technology, May 2003.
[33] R. A. Hyde, L. P. Ketteringham, S. A. Neild, and R. J. S. Jones. Estimation of upperlimb orientation based on accelerometer and gyroscope measurements. 55(2):746–754, February 2008.
[34] E. R. Bachmann, I. Duman, U. Y. Usta, R. B. McGhee, X. P. Yun, and M. J. Zyda. Orientation tracking for humans and robots using inertial sensors. In Proc. IEEE International Symposium on Computational Intelligence in Robotics and Automation CIRA ’99, pages 187–194, November 8–9, 1999.
[35] R. Mahony, T. Hamel, and J.-M. Pflimlin. Nonlinear complementary filters on the special orthogonal group. Automatic Control, IEEE Transactions on, 53(5):1203 –1218, june 2008.
[36] J. B. Kuipers. Quaternions and Rotation Sequences: A Primer with Applications to Orbits, Aerospace and Virtual Reality. Princeton University Press, 1999.
[37] John J. Craig. Introduction to Robotics Mechanics and Control. Pearson Education International, 2005.
[38] David R. Pratt Robert B. McGhee Joseph M. Cooke, Michael J. Zyda. Npsnet: Flight simulation dynamic modelling using quaternions. Presence, 1:404–420, 1994.
[39] John Arthur Jacobs. The earth’s core, volume 37 of International geophysics series. Academic Press, 2 edition, 1987.
[40] E. R. Bachmann, Xiaoping Yun, and C. W. Peterson. An investigation of the effects of magnetic variations on inertial/magnetic orientation sensors. In Proc. IEEE International Conference on Robotics and Automation ICRA ’04, volume 2, pages 1115–1122, April 2004.
[41] C.T.M. Baten F.C.T. van der Helm W.H.K. de Vries, H.E.J. Veeger. Magnetic distortion in motion labs, implications for validating inertial magnetic sensors. Gait & Posture, 29(4):535–541, 2009.
[42] Speake & Co Limited. Autocalibration algorithms for FGM type sensors. Application note.
[43] Michael J. Caruso. Applications of Magnetoresistive Sensors in Navigation Systems. Honeywell Inc., Solid State Electronics Center, Honeywell Inc. 12001 State Highway 55, Plymouth, MN 55441.

[44] J. F. Vasconcelos, G. Elkaim, C. Silvestre, P. Oliveira, and B. Cardeira. A geometric approach to strapdown magnetometer calibration in sensor frame. In Navigation, Guidance and Control of Underwater Vehicles, volume 2, 2008.
[45] Demoz Gebre-Egziabher, Gabriel H. Elkaim, J. David Powell, and Bradford W. Parkinson. Calibration of strapdown magnetometers in magnetic field domain. Journal of Aerospace Engineering, 19(2):87–102, 2006.
[46] Vicon Motion Systems Limited. Vicon MX Hardware. 5419 McConnell Avenue, Los Angeles, CA 90066, USA, 1.6 edition, 2004.
[47] Vicon Motion Systems Limited. Vicon Nexus Product Guide - Foundation Notes. 5419 McConnell Avenue, Los Angeles, CA 90066, USA, 1.2 edition, November 2007.
[48] Itzhack Y Bar-Itzhack. New method for extracting the quaternion from a rotation matrix. AIAA Journal of Guidance, Control and Dynamics, 23(6):10851087, Nov.Dec 2000. (Engineering Note).
[49] M. A. Brodie, A. Walmsley, and W. Page. The static accuracy and calibration of inertial measurement units for 3D orientation. Computer Methods in Biomechanics and Biomedical Engineering, 11(6):641–648, December 2008.
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

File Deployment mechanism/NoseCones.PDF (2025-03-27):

# THE DESCRIPTIVE GEOMETRY OF NOSE CONES

© 1996 Gary A. Crowell Sr.

In my work on the VCP program, it was necessary to collect the equations describing the various nose cone shapes. This collection also brought together some nomenclature and nose cone information that I have never seen gathered in a single source, so I’ve tried to tidy it up and present it here for your amusement.
GENERAL DIMENSIONS

In all of the following nosecone shape; centerline (C /L). Note that the equations; Dimensions used in the equations

equations, L is the overall length of the nosecone, and R is the radius of the base of the nosecone. y is the radius at any point x, as x varies from 0, at the tip of the nosecone, to L. The equations define the 2-dimensional profile of the nose shape.
The full body of revolution of the nosecone
is formed by rotating the profile around the

describe the ‘perfect’ shape; practical nosecones are often blunted or truncated for manufacturing or aerodynamic reasons (see the following section on ‘Bluffness Ratio’).
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

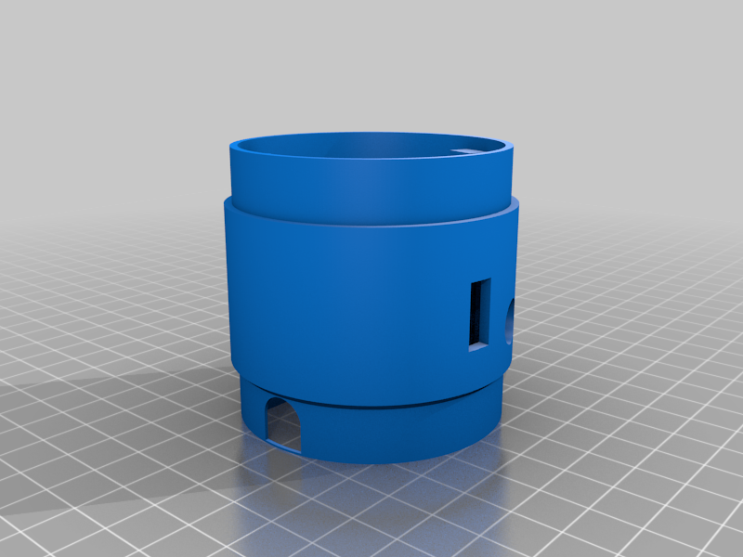
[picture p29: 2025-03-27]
Deployment mechanism/Nose Cone Inspo/images/16c3a8e3-1865-4696-90c5-e0d80077c4c7.png

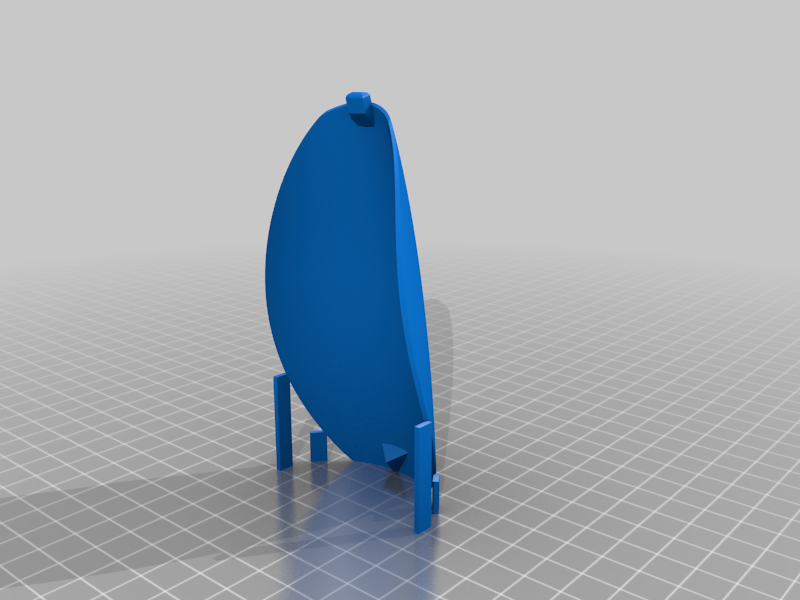
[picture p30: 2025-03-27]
Deployment mechanism/Nose Cone Inspo/images/69d2b99c-418d-4f8e-915a-3b5fa68790b6.png

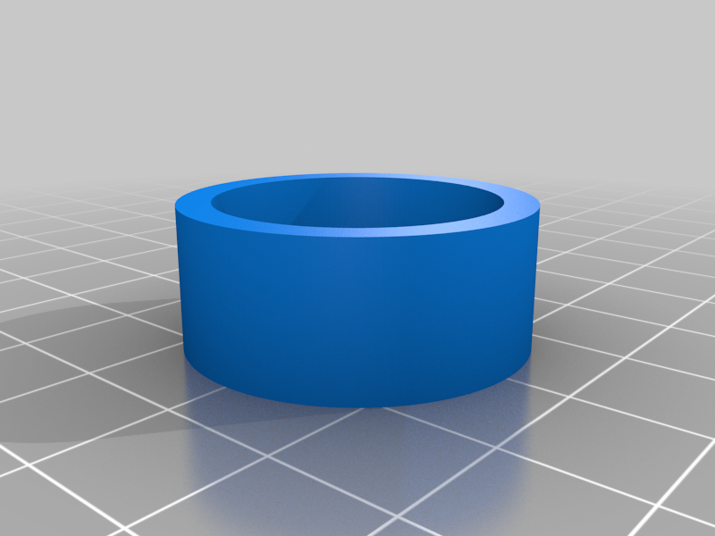
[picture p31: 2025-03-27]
Deployment mechanism/Nose Cone Inspo/images/36b71c4e-dd04-4948-948c-f88aedef48b5.png

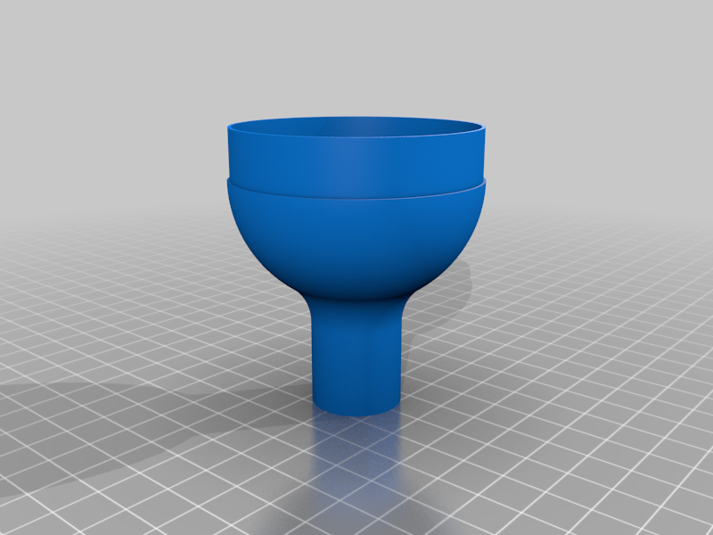
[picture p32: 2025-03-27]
Deployment mechanism/Nose Cone Inspo/images/e361d4f4-346d-4208-bea3-8abbda08b567.png

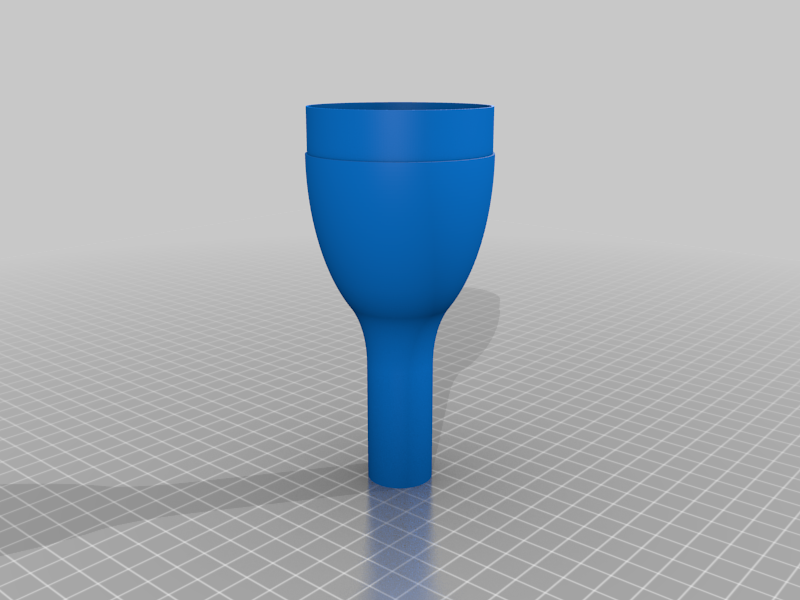
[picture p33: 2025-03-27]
Deployment mechanism/Nose Cone Inspo/images/b4a780fb-7740-4f21-b405-98c225118ab4.png

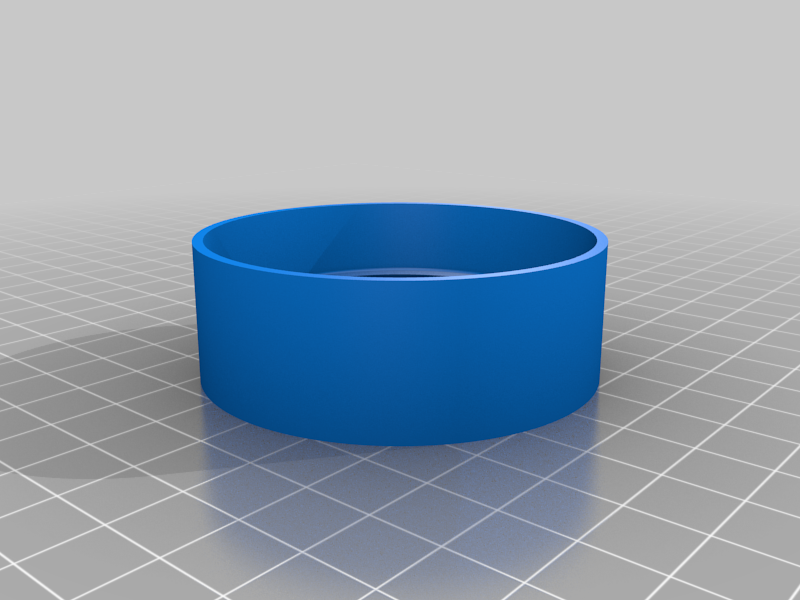
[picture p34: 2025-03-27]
Deployment mechanism/Nose Cone Inspo/images/b1d1b7d1-9ebb-4e82-9e29-f9c1a24ced98.png

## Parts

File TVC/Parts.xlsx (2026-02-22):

Parts | Where | Link
M3 Screws | Outer | https://shorturl.at/NAhjO
M3.5 Screws | Inner | https://shorturl.at/NAhjO
Servos Metal | Movement | https://shorturl.at/ichXq
Wire Metal | Connectors

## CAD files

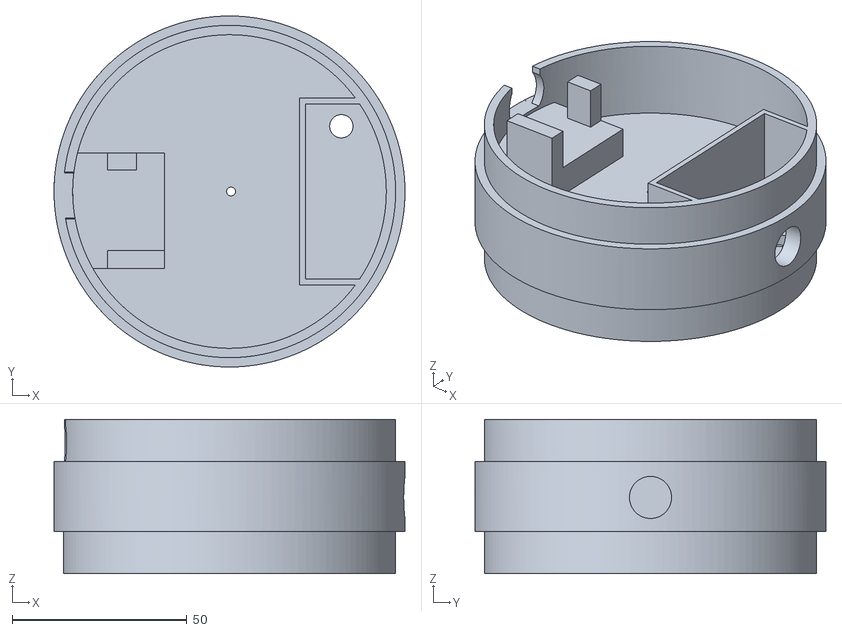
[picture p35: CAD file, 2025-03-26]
Deployment mechanism/Nose Cone Adjusted 10cm/New Base 10cm.stl
100.5 x 100.5 x 44.2

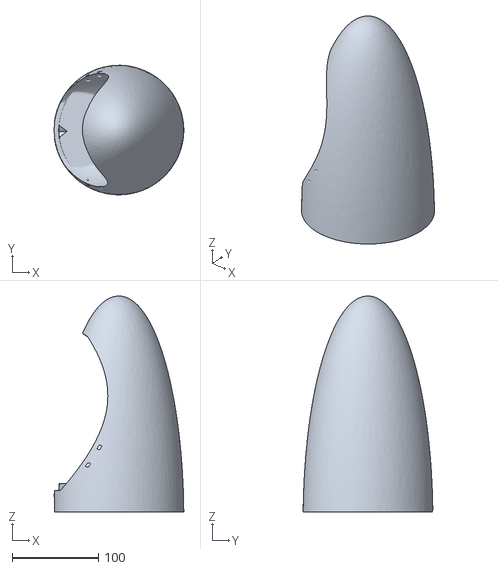
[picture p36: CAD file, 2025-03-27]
Deployment mechanism/Nose Cone Adjusted 15cm/Nose Cone.stl
150.0 x 150.0 x 250.0

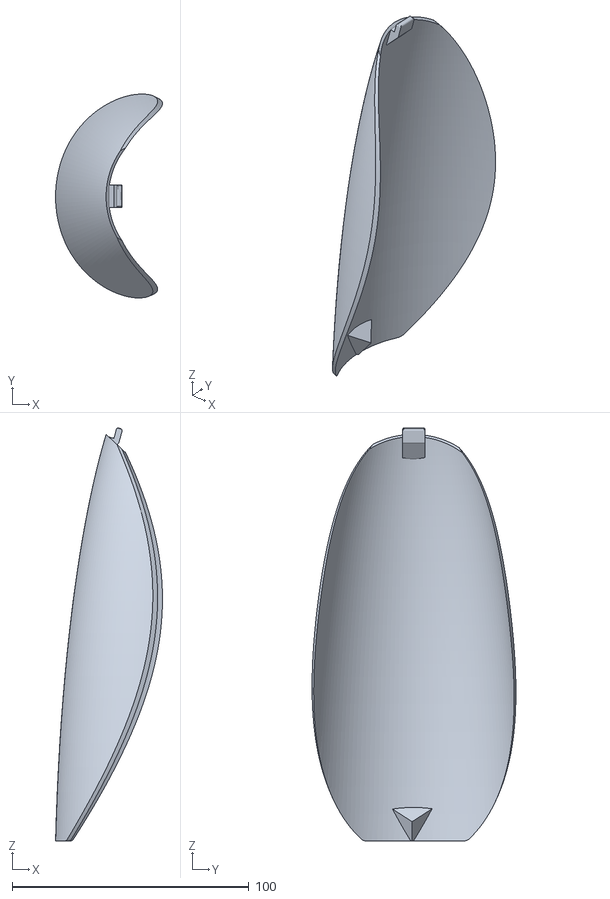
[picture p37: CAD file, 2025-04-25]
Deployment mechanism/Nose Cone Fit 10cm/Cap Finished.stl
45.1 x 86.1 x 174.4

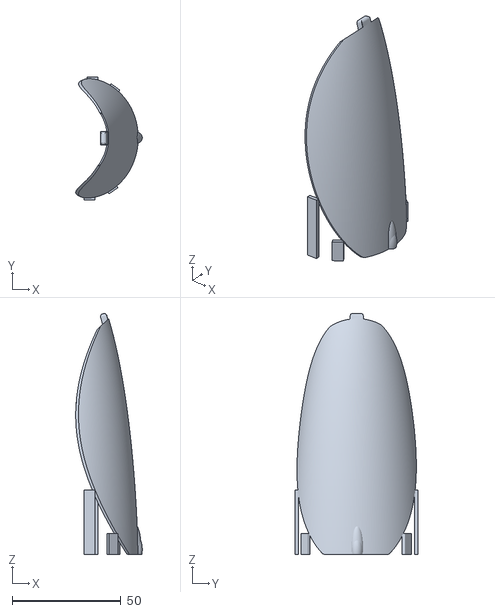
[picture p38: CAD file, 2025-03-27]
Deployment mechanism/Nose Cone Inspo/files/cover.stl
30.6 x 56.4 x 110.7

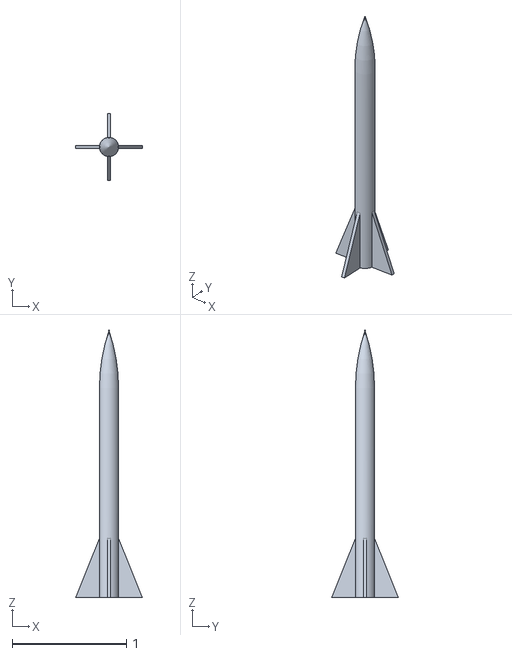
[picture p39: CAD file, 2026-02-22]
MatLab Sim/Rocket.stl
0.584 x 0.584 x 2.34

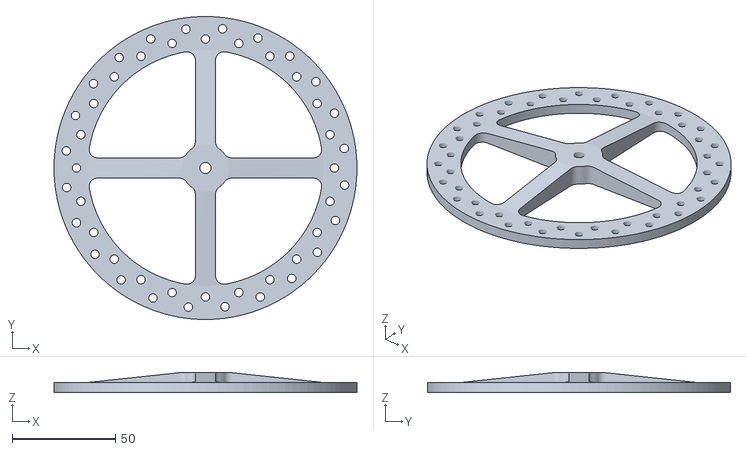
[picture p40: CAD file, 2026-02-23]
Reaction Wheel/3D Files/reaction_wheel.stl
146.7 x 146.7 x 9.78

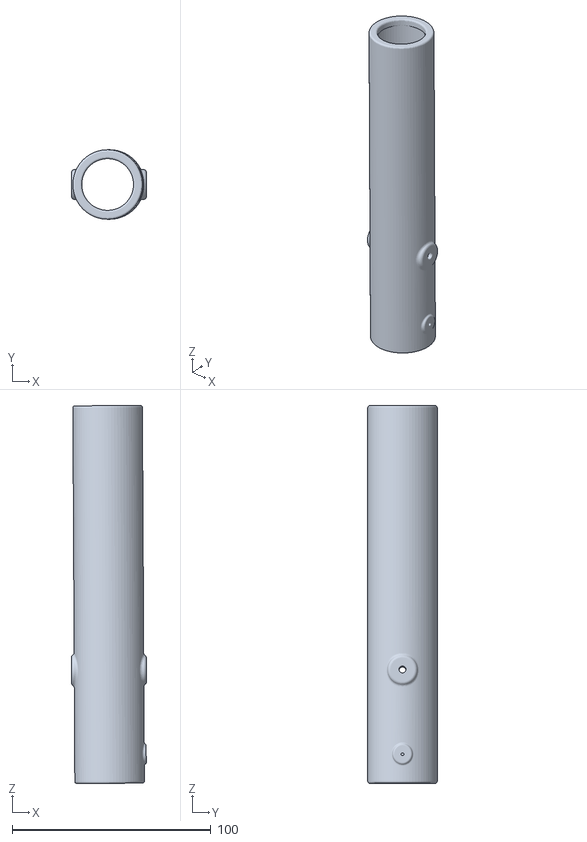
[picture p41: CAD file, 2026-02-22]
TVC/Design/Tube.stl
37.8 x 35.0 x 190.2

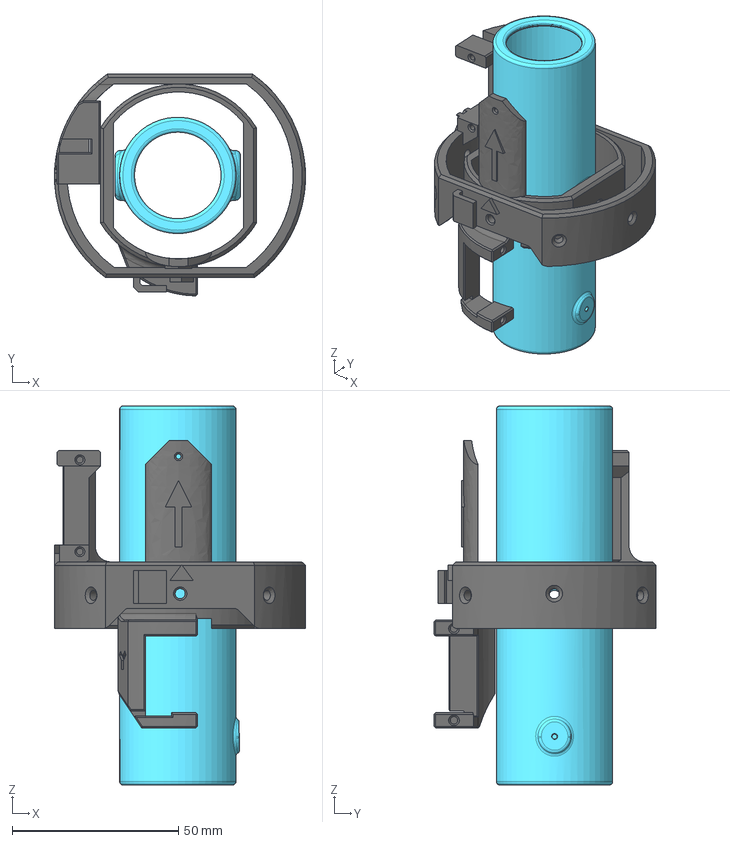
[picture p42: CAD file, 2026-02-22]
TVC/K-9_TVC_V7_R1_.step
75.5 x 66.8 x 114.0 mm
Outer GImbal
Motor Tube
Inner GImbal

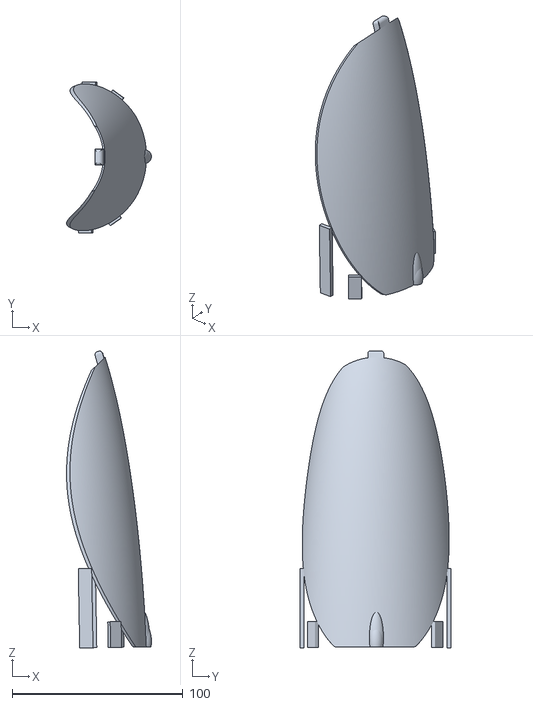
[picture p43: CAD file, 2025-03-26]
Deployment mechanism/Nose Cone Adjusted 10cm/Cap 10cm.stl
49.8 x 88.5 x 174.0

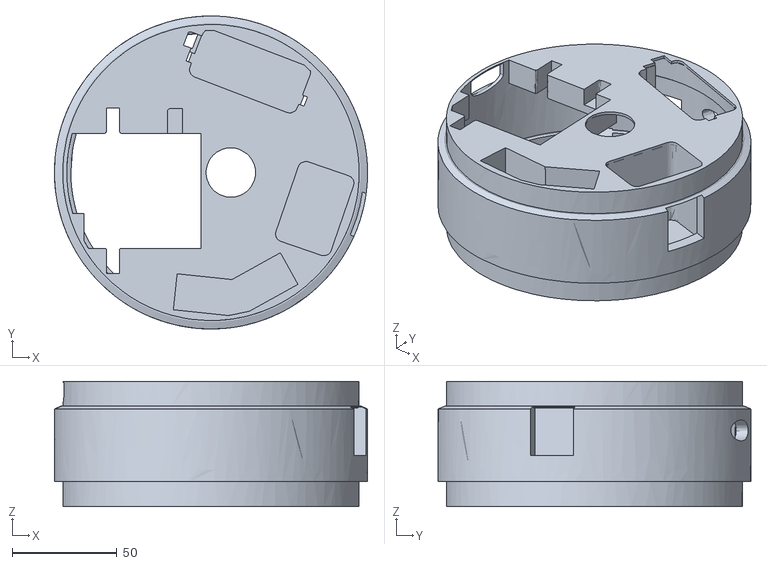
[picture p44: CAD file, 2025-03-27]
Deployment mechanism/Nose Cone Adjusted 15cm/Base.stl
149.2 x 149.1 x 59.8

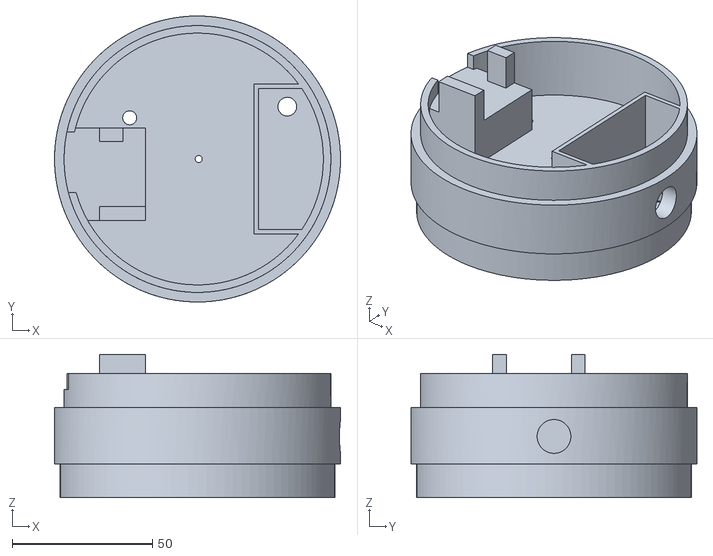
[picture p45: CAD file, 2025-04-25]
Deployment mechanism/Nose Cone Fit 10cm/Base Finished.stl
102.0 x 102.0 x 51.1

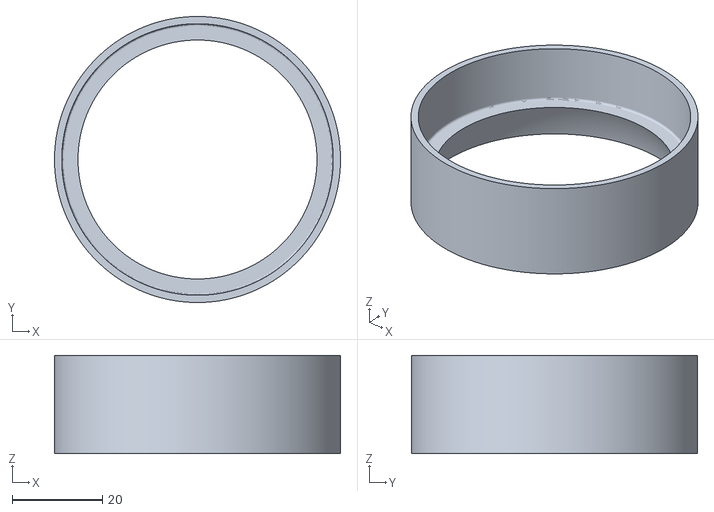
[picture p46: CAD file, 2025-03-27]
Deployment mechanism/Nose Cone Inspo/files/mount.stl
63.4 x 63.4 x 21.8

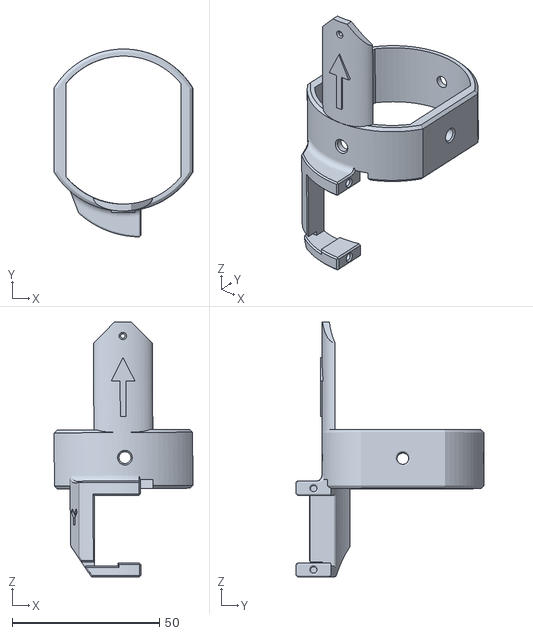
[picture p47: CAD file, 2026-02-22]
TVC/Design/Inner Gimbal.stl
47.1 x 63.8 x 86.5

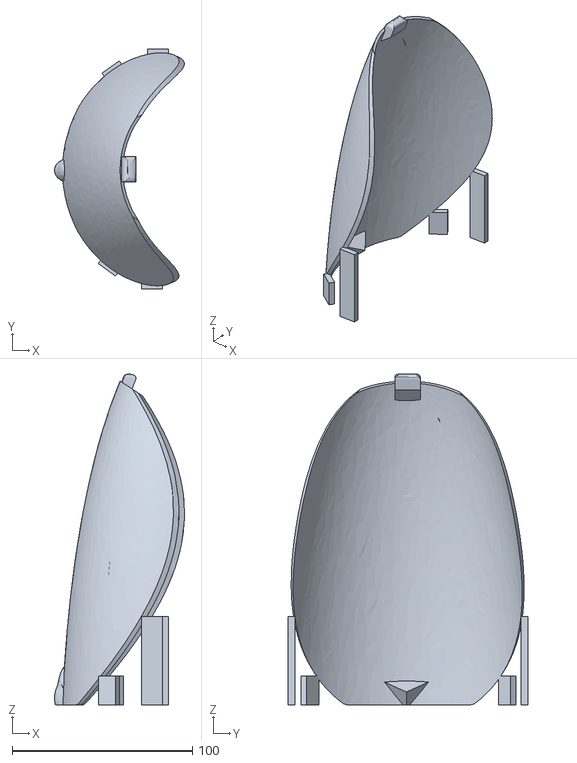
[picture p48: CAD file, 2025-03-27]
Deployment mechanism/Nose Cone Adjusted 15cm/Cap.stl
72.2 x 133.1 x 183.8

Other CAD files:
TVC/Motor Tube.stl
Deployment mechanism/Nose Cone Inspo/files/retain.stl
TVC/Design/Casing.stl
TVC/Inner Gimbal.stl
Deployment mechanism/Nose Cone Adjusted 15cm/New Base.stl
Deployment mechanism/Nose Cone Inspo/files/60mm_closure.stl
Deployment mechanism/Nose Cone Inspo/files/New Nose Cone.stl
Deployment mechanism/Nose Cone Inspo/files/payload.stl
TVC/Design/Outer Gimbal.stl
TVC/Design/Reaction Wheel.stl
TVC/Outer Gimbal.stl
TVC/TVC Test Stand.stl

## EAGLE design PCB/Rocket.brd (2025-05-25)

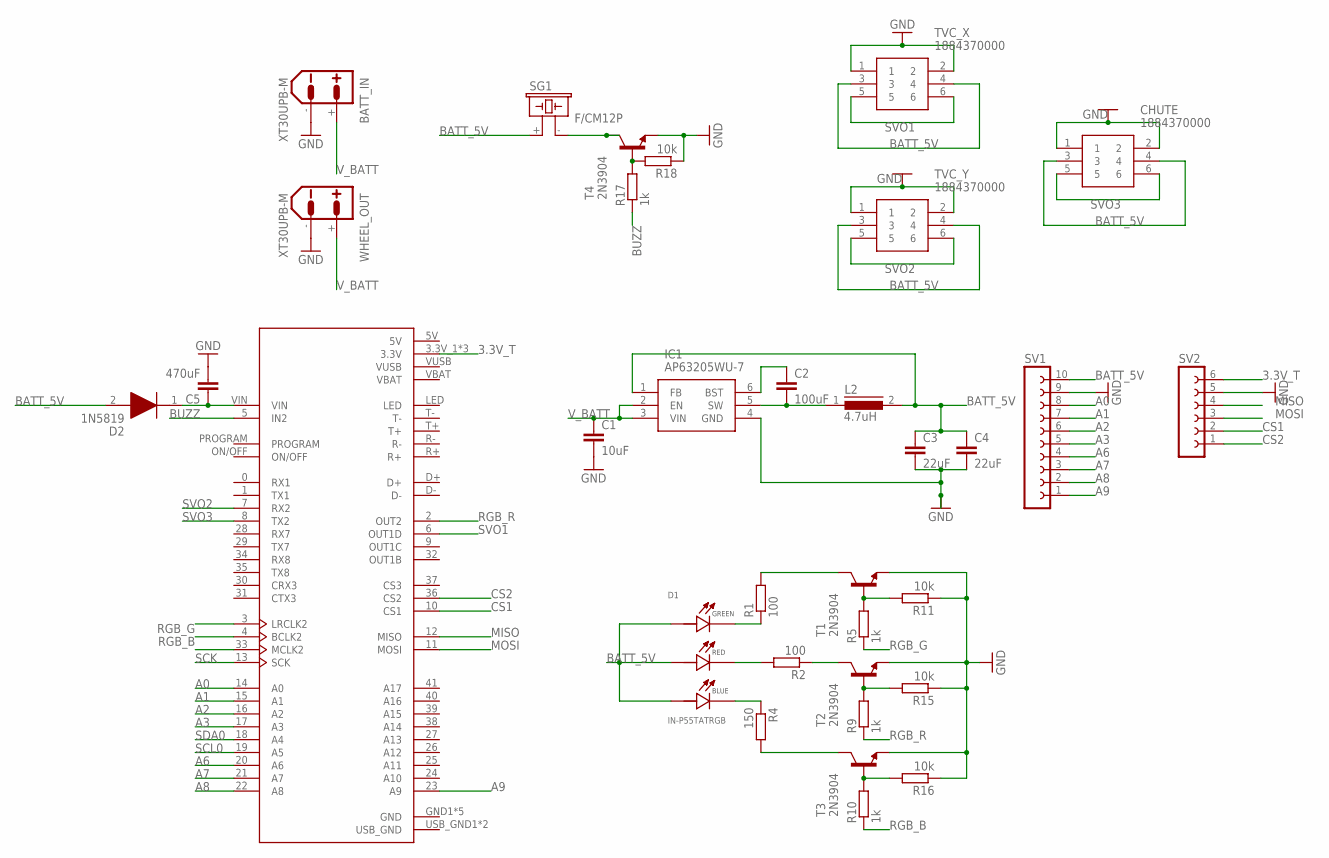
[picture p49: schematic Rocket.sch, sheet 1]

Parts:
BATT_IN: XT30UPB-M
C1: 10uF; C2.5-2
C2: 100uF; C2.5-2
C3, C4: 22uF; C2.5-2
C5: 470uF; C2.5-2
CHUTE: 1884370000
D1: IN-P55TATRGB; LED_IN-P55TATRGB
D2: 1N5819; DIOAD1414W86L464D238
IC1: AP63205WU-7; AP63205WU7
L2: 4.7uH; MCC10
R1, R2: 100; 0204/7
R4: 150; 0204/7
R5, R9, R10, R17: 1k; 0204/7
R11, R15, R16, R18: 10k; 0204/7
SG1: F/CM12P
SV1: FE10-1; FE10
SV2: FE06-1; FE06
T1, T2, T3, T4: 2N3904; TO92
TVC_X: 1884370000
TVC_Y: 1884370000
U6: DEV-16771; MODULE_DEV-16771
WHEEL_OUT: XT30UPB-M

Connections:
3.3V_T: SV2.6, U6.3.3V_1 (3.3V), U6.3.3V_2 (3.3V), U6.3.3V_3 (3.3V); also elsewhere on the board
5V: U6.5V
A0: SV1.8, U6.14 (A0)
A1: SV1.7, U6.15 (A1)
A2: SV1.6, U6.16 (A2)
A3: SV1.5, U6.17 (A3)
A6: SV1.4, U6.20 (A6)
A7: SV1.3, U6.21 (A7)
A8: SV1.2, U6.22 (A8)
A9: SV1.1, U6.23 (A9)
BATT_5V: C3.1, C4.1, CHUTE.3, CHUTE.4, D1.4 (G_A), D1.5 (R_A), D1.6 (B_A), D2.2 (A), IC1.1 (FB), L2.2, SG1.+ (1), SV1.10, TVC_X.3, TVC_X.4, TVC_Y.3, TVC_Y.4
BUZZ: R17.1, U6.5 (IN2)
CS1: SV2.2, U6.10 (CS1)
CS2: SV2.1, U6.36 (CS2)
GND: BATT_IN.-, C1.2, C3.2, C4.2, C5.2, CHUTE.1, CHUTE.2, IC1.4 (GND), R11.1, R15.1, R16.1, R18.1, SV1.9, SV2.5, T1.3 (E), T2.3 (E), T3.3 (E), T4.3 (E), TVC_X.1, TVC_X.2, TVC_Y.1, TVC_Y.2, U6.GND1 (GND), U6.GND2 (GND), U6.GND3 (GND), U6.GND4 (GND), U6.GND5 (GND), WHEEL_OUT.-; also elsewhere on the board
MISO: SV2.4, U6.12 (MISO)
MOSI: SV2.3, U6.11 (MOSI)
unnamed: D1.3 (G_C), R1.1
unnamed: D1.2 (R_C), R2.2
unnamed: C5.1, D2.1 (K), U6.VIN
unnamed: D1.1 (B_C), R4.1
unnamed: R1.2, T1.1 (C)
unnamed: C2.2, IC1.5 (SW), L2.1
unnamed: C2.1, IC1.6 (BST)
unnamed: R2.1, T2.1 (C)
unnamed: R4.2, T3.1 (C)
unnamed: R5.2, R11.2, T1.2 (B)
unnamed: R9.2, R15.2, T2.2 (B)
unnamed: R10.2, R16.2, T3.2 (B)
unnamed: SG1.- (2), T4.1 (C)
unnamed: R17.2, R18.2, T4.2 (B)
RGB_B: R10.1, U6.4 (BCLK2)
RGB_G: R5.1, U6.3 (LRCLK2)
RGB_R: R9.1, U6.2 (OUT2)
SCK: U6.13 (SCK)
SCL0: U6.19 (A5); also elsewhere on the board
SDA0: U6.18 (A4); also elsewhere on the board
SVO1: TVC_X.5, TVC_X.6, U6.6 (OUT1D)
SVO2: TVC_Y.5, TVC_Y.6, U6.7 (RX2)
SVO3: CHUTE.5, CHUTE.6, U6.8 (TX2)
USB_GND: U6.USB_GND1 (USB_GND), U6.USB_GND2 (USB_GND)
V_BATT: BATT_IN.+, C1.1, IC1.2 (EN), IC1.3 (VIN), WHEEL_OUT.+

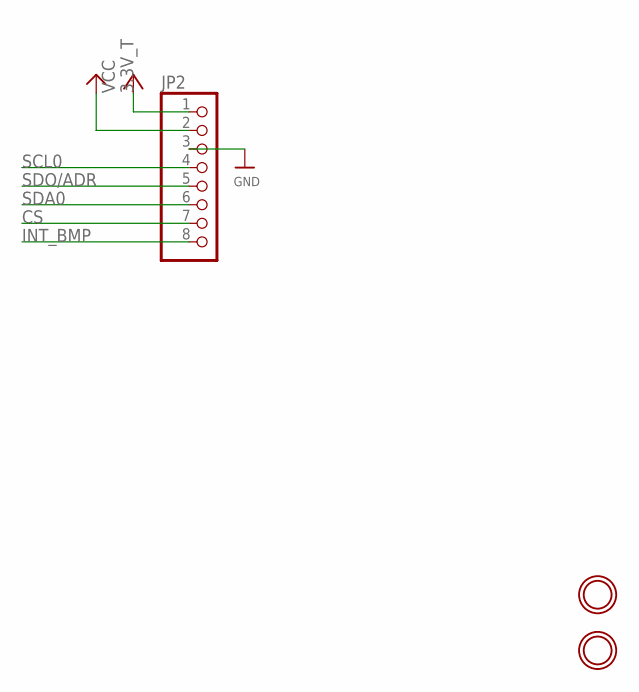
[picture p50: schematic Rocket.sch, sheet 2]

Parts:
JP2: HEADER-1X870MIL; 1X08_ROUND_70
U$24, U$26: MOUNTINGHOLE2.5; MOUNTINGHOLE_2.5_PLATED

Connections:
3.3V_BMP: JP2.2
3.3V_T: JP2.1; also elsewhere on the board
CS: JP2.7
GND: JP2.3; also elsewhere on the board
INT_BMP: JP2.8
SCL0: JP2.4; also elsewhere on the board
SDA0: JP2.6; also elsewhere on the board
SDO/ADR: JP2.5

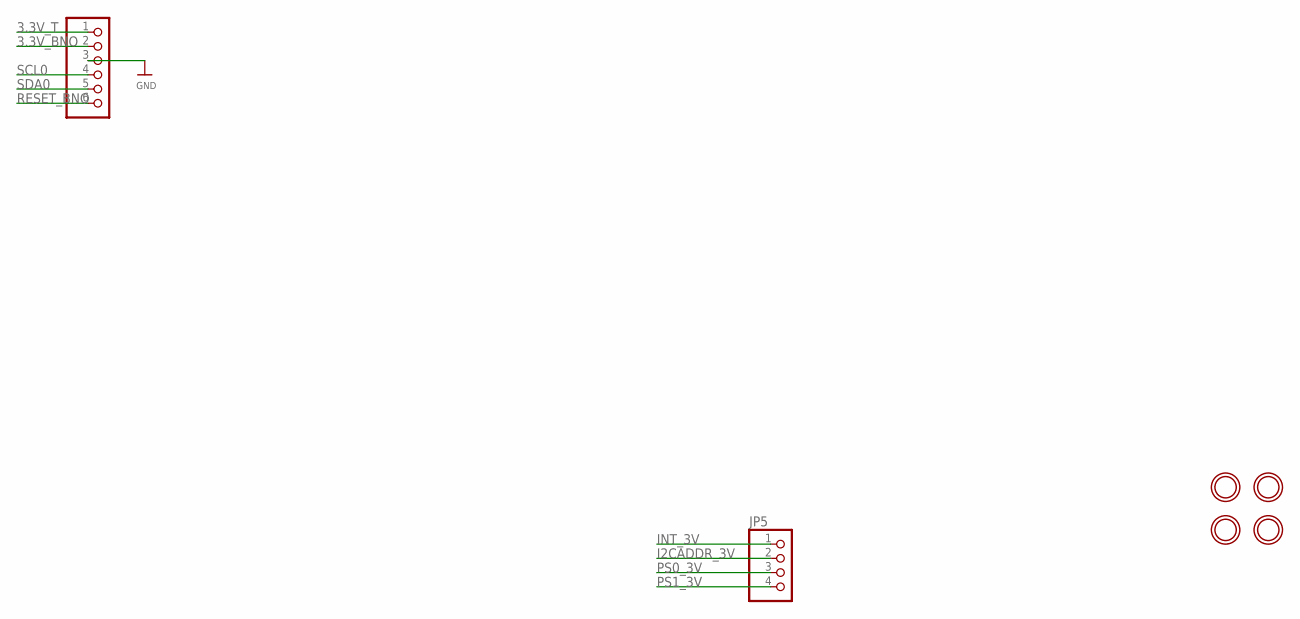
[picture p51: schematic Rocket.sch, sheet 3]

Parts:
JP5: HEADER-1X476MIL; 1X04_ROUND_76
JP6: HEADER-1X670MIL; 1X06_ROUND_70
U$109, U$110, U$112, U$113: MOUNTINGHOLE2.5; MOUNTINGHOLE_2.5_PLATED

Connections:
3.3V_BNO: JP6.2
3.3V_T: JP6.1; also elsewhere on the board
GND: JP6.3; also elsewhere on the board
I2CADDR_3V: JP5.2
INT_3V: JP5.1
PS0_3V: JP5.3
PS1_3V: JP5.4
RESET_BNO: JP6.6
SCL0: JP6.4; also elsewhere on the board
SDA0: JP6.5; also elsewhere on the board

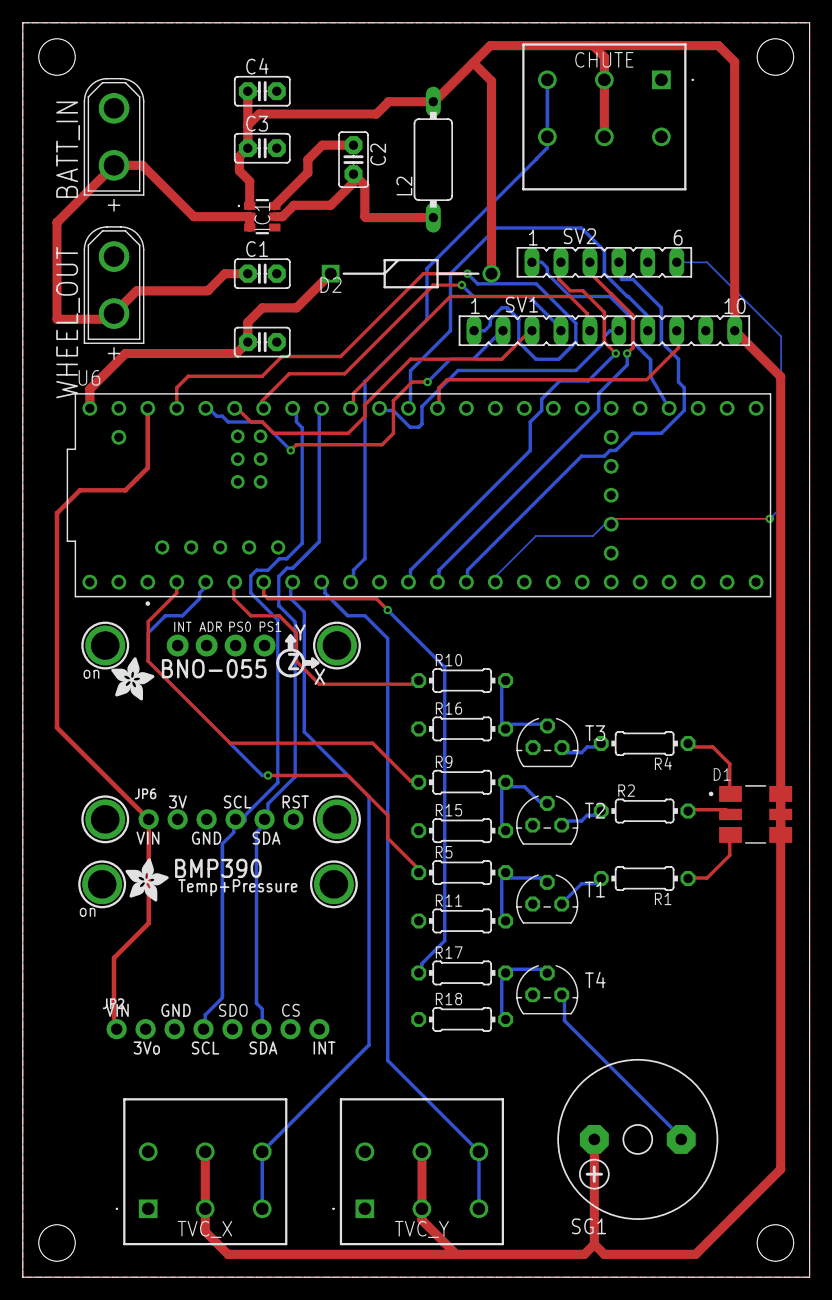
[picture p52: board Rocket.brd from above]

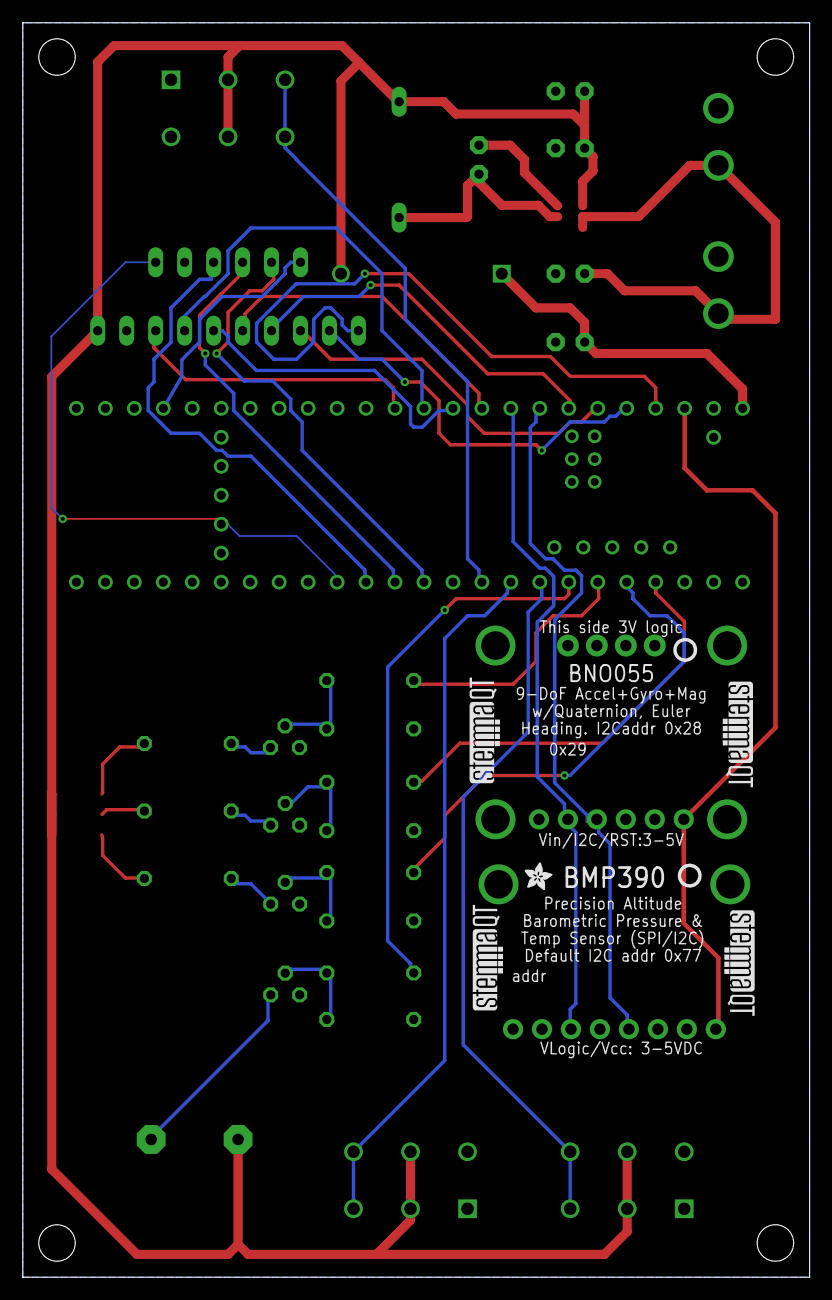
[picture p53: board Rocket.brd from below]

Board: 2 copper layers, 69.0 x 110.0 mm, 51 parts (7 on the bottom side), 40 nets.

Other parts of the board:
U$32: ADAFRUIT_2.5MM
U$39, U$117: ADAFRUIT_3.5MM
U$43, U$118: PCBFEAT-REV-040
U$44, U$50, U$119, U$120: STEMMAQT

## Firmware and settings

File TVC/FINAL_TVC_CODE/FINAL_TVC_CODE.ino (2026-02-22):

#include <Wire.h>
#include <Adafruit_BNO055.h>
#include <Servo.h>
#include <math.h>
#include <MadgwickAHRS.h>



// IMU and Servo setup
Adafruit_BNO055 bno = Adafruit_BNO055(55);
Servo tvcServoX, tvcServoY;


//Filter setup
Madgwick filter;

// Thrust curve data
const int thrustPoints = 9;
float thrustTimes[thrustPoints] = {0, 0.05, 0.1, 0.2, 0.5, 1.0, 2.0, 3.0, 60.0};
float thrustValues[thrustPoints] = {0, 62, 40, 38, 40, 39, 38, 37, 36};

//Middle Position of X and Y Servo
const int X_SERVO_MIDDLE = 102;
const int Y_SERVO_MIDDLE = 88;

//Set Moment Arm
const float momentArm = 0.35; // meters

//Gain Matrices for State Controller
const float K_Roll[2] = {1.1952, 0.6491};
const float K_Pitch[2] = {1.1952, 0.6491};

//Setpoint Matrices for State Controller
const float Setpoint_Roll[2] = {M_PI/2, 0.0};
const float Setpoint_Pitch[2] = {0.0, 0.0};

//Calculating thrust variables
unsigned long liftoffTime = 0;
bool launched = false;
unsigned long lastTime = 0;

//Set update rate
const unsigned long updateInterval = 10000; // 10 ms = 100 Hz


double gimbal_to_servo(double a, double b, double gimbal_angle_deg){
  return a * gimbal_angle_deg + b;
}

double state_controller(const float K[2], float x[2], const float setpoint[2]){
  float u = 0;
  x[0] -= setpoint[0];
  x[1] -= setpoint[1];
  u = -(K[0] * x[0] + K[1] * x[1]);
  return u;
}

double torque_to_angle(float torque, float thrust){
  double asin_input = constrain(torque / (momentArm * thrust), -1, 1);
  return asin(asin_input);
}

float RadToDegrees(float rad){
  return rad * 180/M_PI;
}

float getThrustFromCurve(float timeSinceLaunch) {
  if (timeSinceLaunch <= thrustTimes[0]) return thrustValues[0];
  if (timeSinceLaunch >= thrustTimes[thrustPoints - 1]) return thrustValues[thrustPoints - 1];

  for (int i = 0; i < thrustPoints - 1; i++) {
    if (timeSinceLaunch >= thrustTimes[i] && timeSinceLaunch <= thrustTimes[i + 1]) {
      float t0 = thrustTimes[i];
      float t1 = thrustTimes[i + 1];
      float thrust0 = thrustValues[i];
      float thrust1 = thrustValues[i + 1];
      float factor = (timeSinceLaunch - t0) / (t1 - t0);
      return thrust0 + factor * (thrust1 - thrust0);
    }
  }
  return 0.0;
}

void setup() {
  Serial.begin(115200);
  bno.begin();
  delay(1000);
  bno.setExtCrystalUse(true);
  tvcServoY.attach(7);
  tvcServoX.attach(6);
  tvcServoX.write(X_SERVO_MIDDLE);
  tvcServoY.write(Y_SERVO_MIDDLE);
  filter.begin(100);       // sample frequency of the filter
  filter.setInitialRollPitch(M_PI/2, 0.0);

  lastTime = micros();
  liftoffTime = millis(); // Simulate immediate launch (change for real launch detection)
}

void loop() {

    //Getting thrust
  unsigned long now = micros();
  if (now - lastTime >= updateInterval) {
    float dt = (now - lastTime) / 1e6;
    lastTime = now;

    float flightTime = (millis() - liftoffTime) / 1000.0;
    float thrust = getThrustFromCurve(flightTime);

    uint8_t system_cal, gyro_cal, accel_cal, mag_cal = 0;
    bno.getCalibration(&system_cal, &gyro_cal, &accel_cal, &mag_cal);
    Serial.println();
    Serial.print("Calibration: Sys=");
    Serial.print(system_cal);
    Serial.print(" Gyro=");
    Serial.print(gyro_cal);
    Serial.print(" Accel=");
    Serial.print(accel_cal);
    Serial.print(" Mag=");
    Serial.println(mag_cal);

    Serial.println("--");

    //Get the rates:
    imu::Vector<3> gyro = bno.getVector(Adafruit_BNO055::VECTOR_GYROSCOPE);
    float rollRate = gyro.x() * (M_PI/180); // rad/s
    float pitchRate = gyro.z() * (M_PI/180); // rad/s

    //Get filtered pitch and roll:
    imu::Vector<3> acc = bno.getVector(Adafruit_BNO055::VECTOR_ACCELEROMETER);

    filter.updateIMU(gyro.x(), gyro.y(), gyro.z(),acc.x(), acc.y(), acc.z());
    float roll = filter.getRollRadians();
    float pitch = filter.getPitchRadians();
    
    //Compute roll torque command:
    float state_vector_roll[2] = {roll, rollRate};
    float roll_torque = state_controller(K_Roll, state_vector_roll, Setpoint_Roll);
    float roll_state_output = torque_to_angle(roll_torque, thrust);
    float gimbalAngleRollDeg = RadToDegrees(roll_state_output);

    //Compute pitch torque command:
    float state_vector_pitch[2] = {pitch, -pitchRate};
    float pitch_torque = state_controller(K_Pitch, state_vector_pitch, Setpoint_Pitch);
    float pitch_state_output = torque_to_angle(pitch_torque, thrust);
    float gimbalAnglePitchDeg = RadToDegrees(pitch_state_output);

    //Convert demanded gimbal angle to servo angle (via CurveFitting)
    float servo_angle_y = gimbal_to_servo(6.0169, 90, gimbalAngleRollDeg);
    float servo_angle_x = gimbal_to_servo(-4.1024, 103.0, gimbalAnglePitchDeg);

    // Map output to servo range (30 degrees in each direction)
    int servoAngleY = constrain(round(servo_angle_y), 57, 118);
    int servoAngleX = constrain(round(servo_angle_x), 72, 132);

    //Write angle to servos
    tvcServoY.write(servoAngleY);
    tvcServoX.write(servoAngleX);

    // Debug
    
    Serial.print("Roll:"); Serial.print(roll * 180 / M_PI);
    Serial.print(",Roll Rate:"); Serial.print(rollRate);
    Serial.print(",StateY:"); Serial.print(roll_state_output);
    Serial.print(",ServoY:"); Serial.print(servoAngleY);
    Serial.print(",gimbalAngleRollDeg: "); Serial.print(gimbalAngleRollDeg);
    Serial.print(",Freq: "); Serial.print(1/dt);
    Serial.print(",Thrust: "); Serial.println(thrust);
    
    
    /*
    Serial.print("Pitch:"); Serial.print(pitch * 180 / M_PI);
    Serial.print(",Pitch Rate:"); Serial.print(-pitchRate);
    Serial.print(",StateX:"); Serial.print(pitch_state_output);
    Serial.print(",ServoX:"); Serial.print(servoAngleX);
    Serial.print(",gimbalAnglePitchDeg: "); Serial.println(gimbalAnglePitchDeg);
    Serial.println(thrust);
    */
  }
  
}

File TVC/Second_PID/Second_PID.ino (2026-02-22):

#include <Wire.h>
#include <Adafruit_BNO055.h>
#include <Servo.h>
#include "DualAxisPID.h"
#include <math.h>

// --- Settings ---
//#define BYPASS_INNER_LOOP  // Comment this out for full mode

// Thrust curve data
const int thrustPoints = 9;
float thrustTimes[thrustPoints] = {0, 0.05, 0.1, 0.2, 0.5, 1.0, 2.0, 3.0, 60.0};
float thrustValues[thrustPoints] = {0, 62, 40, 38, 40, 39, 38, 37, 36};

Adafruit_BNO055 bno = Adafruit_BNO055(55);
Servo tvcServoY, tvcServoX;

const int X_SERVO_MIDDLE = 102;
const int Y_SERVO_MIDDLE = 88;
const float momentArm = 0.35; // meters
const float targetRoll = M_PI/2;
const float targetPitch = 0.0;

// Initial PID gains (modifiable via Serial)
float outerKp = 50;
float outerKi = 20;
float outerKd = 0.0;

float innerKp = 0.1;
float innerKi = 0.0;
float innerKd = 0.002;

DualAxisPID controller(outerKp, outerKi, outerKd, innerKp, innerKi, innerKd, 40.0);  // Filter coeff N;

PIDState rollAnglePID, rollRatePID, pitchAnglePID, pitchRatePID;

unsigned long liftoffTime = 0;
bool launched = false;
unsigned long lastTime = 0;

float getThrustFromCurve(float timeSinceLaunch) {
  if (timeSinceLaunch <= thrustTimes[0]) return thrustValues[0];
  if (timeSinceLaunch >= thrustTimes[thrustPoints - 1]) return thrustValues[thrustPoints - 1];

  for (int i = 0; i < thrustPoints - 1; i++) {
    if (timeSinceLaunch >= thrustTimes[i] && timeSinceLaunch <= thrustTimes[i + 1]) {
      float t0 = thrustTimes[i];
      float t1 = thrustTimes[i + 1];
      float thrust0 = thrustValues[i];
      float thrust1 = thrustValues[i + 1];
      float factor = (timeSinceLaunch - t0) / (t1 - t0);
      return thrust0 + factor * (thrust1 - thrust0);
    }
  }
  return 0.0;
}

//Transformation in rad
void quaternionToEuler(float w, float x, float y, float z, float &yaw, float &pitch, float &roll) {
  float sinr_cosp = 2 * (w * x + y * z);
  float cosr_cosp = 1 - 2 * (x * x + y * y);
  roll = atan2(sinr_cosp, cosr_cosp);

  float sinp = 2 * (w * y - z * x);
  pitch = fabs(sinp) >= 1 ? copysign(M_PI / 2, sinp) : asin(sinp);

  float siny_cosp = 2 * (w * z + x * y);
  float cosy_cosp = 1 - 2 * (y * y + z * z);
  yaw = atan2(siny_cosp, cosy_cosp);
}

double gimbal_to_servo(double a, double b, double c, double gimbal_angle_deg){
  double c_prime = c - abs(gimbal_angle_deg);
  double discriminant = b*b - 4 * a * c_prime;

  if(discriminant < 0){
    Serial.println("No real solution for this gimbal angle.");
    return 0;
  }


  double servo_angle = (-b + sqrt(discriminant)) / (2 * a);
  if(gimbal_angle_deg<0){
    servo_angle *= -1;
  }
  return servo_angle;
}

void bno_ready(){
  Serial.println("Waiting for valid IMU orientation...");

  float roll = 0.0, pitch = 0.0, yaw = 0.0;
  unsigned long waitStart = millis();

  while (true) {
    imu::Quaternion quat = bno.getQuat();
    quaternionToEuler(quat.w(), quat.x(), quat.y(), quat.z(), yaw, pitch, roll);

    // Wait until roll or pitch has moved at least 5 degrees from zero
    if (abs(roll) > 5.0 || abs(pitch) > 5.0) break;

    // Optional: timeout safety
    if (millis() - waitStart > 5000) {
      Serial.println("Timeout: IMU never became ready!");
      break;
    }

    delay(10);
  }

  Serial.println("IMU orientation stabilized!");
}

void handleSerialTuning() {
  if (Serial.available()) {
    String input = Serial.readStringUntil('\n');
    input.trim();

    if (input.startsWith("O ")) {
      sscanf(input.c_str(), "O %f %f %f", &outerKp, &outerKi, &outerKd);
      controller.setOuterGains(outerKp, outerKi, outerKd);
      Serial.println("Updated Outer PID");
    } else if (input.startsWith("I ")) {
      sscanf(input.c_str(), "I %f %f %f", &innerKp, &innerKi, &innerKd);
      controller.setInnerGains(innerKp, innerKi, innerKd);
      Serial.println("Updated Inner PID");
    } else {
      Serial.println("Unknown command. Use:\n  O Kp Ki Kd\n  I Kp Ki Kd");
    }
  }
}

float RadToDegrees(float rad){
  return rad * 180/M_PI;
}

void setup() {
  Serial.begin(9600);
  bno.begin();
  delay(1000);
  bno.setExtCrystalUse(true);

  tvcServoY.attach(9);
  tvcServoY.write(Y_SERVO_MIDDLE);
  tvcServoX.attach(10);
  tvcServoX.write(X_SERVO_MIDDLE);

  // Wait for BNO to return a valid quaternion (not all zeros)
  bno_ready();
  lastTime = micros();
  liftoffTime = millis(); // Simulate immediate launch (change for real launch detection)
}

void loop() {
  handleSerialTuning();
  unsigned long now = micros();
  float dt = (now - lastTime) / 1e6;
  if (dt <= 0.0f || dt > 0.1f) dt = 0.01f;
  lastTime = now;

  float flightTime = (millis() - liftoffTime) / 1000.0;
  float thrust = getThrustFromCurve(flightTime);
  if (thrust > 0.0){
    imu::Quaternion quat = bno.getQuat();
    float roll, pitch, yaw;
    quaternionToEuler(quat.w(), quat.x(), quat.y(), quat.z(), yaw, pitch, roll);

    imu::Vector<3> gyro = bno.getVector(Adafruit_BNO055::VECTOR_GYROSCOPE);
    float rollRate = gyro.x(); // rad/s
    float pitchRate = gyro.z(); // rad/s

    // === Apply deadband to ignore noise ===
    const float gyroDeadband = 0.5; // rad/s

    if (abs(rollRate) < gyroDeadband) rollRate = 0.0;
    if (abs(pitchRate) < gyroDeadband) pitchRate = 0.0;

    float desiredRollRate = controller.computeOuterLoop(targetRoll, roll, rollAnglePID, dt);
    float desiredPitchRate = controller.computeOuterLoop(targetPitch, pitch, pitchAnglePID, dt);

    float torqueRoll, torquePitch;

    #ifdef BYPASS_INNER_LOOP
      // Bypass inner loop: Scale the desired rate directly to torque
      torqueRoll = desiredRollRate * 0.1;   // 0.1 = gain factor, you can tweak
      torquePitch = desiredPitchRate * 0.1;
    #else
      // Full cascade control: Angle PID + Rate PID
      torqueRoll = controller.computeInnerLoop(desiredRollRate, rollRate, rollRatePID, dt);
      torquePitch = controller.computeInnerLoop(desiredPitchRate, pitchRate, pitchRatePID, dt);
    #endif

    float inputRoll = constrain(torqueRoll / (thrust * momentArm), -1.0, 1.0);
    float gimbalAngleRollRad = asin(inputRoll);

    float inputPitch = constrain(torquePitch / (thrust * momentArm), -1.0, 1.0);
    float gimbalAnglePitchRad = asin(inputPitch);

    float gimbalAngleRollDeg = RadToDegrees(gimbalAngleRollRad);
    float gimbalAnglePitchDeg = RadToDegrees(gimbalAnglePitchRad);

    float ServoRollDeg = gimbal_to_servo(-0.00050, 0.22154, 0.04156, gimbalAngleRollDeg);
    float ServoPitchDeg = gimbal_to_servo(0.00094, 0.1562, -0.0443, gimbalAnglePitchDeg);

    tvcServoY.write(constrain(Y_SERVO_MIDDLE - ServoRollDeg, 58, 118));
    tvcServoX.write(constrain(X_SERVO_MIDDLE + ServoPitchDeg, 72, 132));

    Serial.print("Roll:"); Serial.print(RadToDegrees(roll));
    Serial.print(",Pitch:"); Serial.print(RadToDegrees(pitch));
    Serial.print(",GimbalY:"); Serial.print(gimbalAngleRollDeg);
    Serial.print(",GimbalX:"); Serial.print(gimbalAnglePitchDeg);
    Serial.print(",RollRate:"); Serial.print(rollRate);
    Serial.print(",PitchRate:"); Serial.print(pitchRate);
  }
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

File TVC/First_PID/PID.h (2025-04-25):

/*
 * PID-Controller
 * 
 * The orientation of the motor mount is calculated with two separate PID-Controllers
 */

#include <Wire.h>
#include <Arduino.h>

class PID {
  public:
    PID(float Kp, float Ki, float Kd, float filter, float setpoint);
    float update(float input);

  private:
    // Proportional gain
    float Kp = 0.0f;
    // Integral gain
    float Ki = 0.0f;
    // Derivative gain
    float Kd = 0.0f;

    // Loop interval time
    float deltaTime = 0.0f;
    float error = 0.0f;
    float setpoint = 0.0f;
    float errorIntegral = 0.0f;
    float rawDerivative = 0.0f;
    float filteredDerivative = 0.0f;
    float errorLastCycle = 0.0f;

    // Some sort of low pass filter on the derivative term
    float filter = 0.0f;
    
    float output = 0.0f;

    unsigned long currentTime = 0.0;
    unsigned long previousTime = 0.0;

    //Anti-windup clamp
    float maxIntegral = 50.0;
};

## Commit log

2025-03-20 pulling code from laptop to raspy- camera tryout
2025-03-20 semi-simultaneous camera(picture) usage
2025-03-26 Add files via upload
    Nose cone with chute release mechanism
    [Cap 10cm.stl, New Base 10cm.stl]
2025-03-27 Put my files in Deployment Mechanism
    [Cap 10cm.stl, New Base 10cm.stl]
2025-03-27 All my other file for the nose cone
    [60mm_closure.stl, Base.stl, Cap.stl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]
2025-03-28 Short/Easy Code for Parachute Deployment
    [Chute_Deploy_Code.ino]
2025-04-25 Loading up the TVC 3D Files
    [Inner Gimbal.stl, Motor Tube.stl, Outer Gimbal.stl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]
2025-04-25 Final version of the nose cone cap / base(Forget all the other)
    [Base Finished.stl, Cap Finished.stl]
2025-04-25 Uploaded 3D files of the reaction wheel
    [Casing.stl, Reaction Wheel.stl]
2025-04-25 My first PID Controller for the TVC
2025-04-25 Screenshot of the board computer (designed in Eagle)
2025-05-25 Probably final design of the rocket PCB / Gerber Files
    [Rocket.brd, Rocket.sch]
2025-05-25 Small changes on the PCB
2025-05-25 Removed old Gerber Files
2026-02-22 Uploaded all relevant files for our project
    [Casing.stl, Inner Gimbal.stl, K-9_TVC_V7_R1_.step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]
2026-02-22 Deleted some files
    [Inner Gimbal.stl, Motor Tube.stl, Outer Gimbal.stl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]
2026-02-23 Final touches of the repo
    [Reaction Wheel.stl, reaction_wheel.stl]

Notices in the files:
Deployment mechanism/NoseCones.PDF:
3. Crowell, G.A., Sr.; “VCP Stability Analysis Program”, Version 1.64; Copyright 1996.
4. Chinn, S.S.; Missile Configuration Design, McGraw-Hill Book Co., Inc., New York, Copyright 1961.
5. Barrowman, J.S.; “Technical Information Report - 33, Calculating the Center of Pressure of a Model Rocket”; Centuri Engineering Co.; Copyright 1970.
